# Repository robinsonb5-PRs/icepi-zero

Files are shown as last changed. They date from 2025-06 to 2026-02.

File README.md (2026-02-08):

# Icepi Zero - The portable FPGA development board

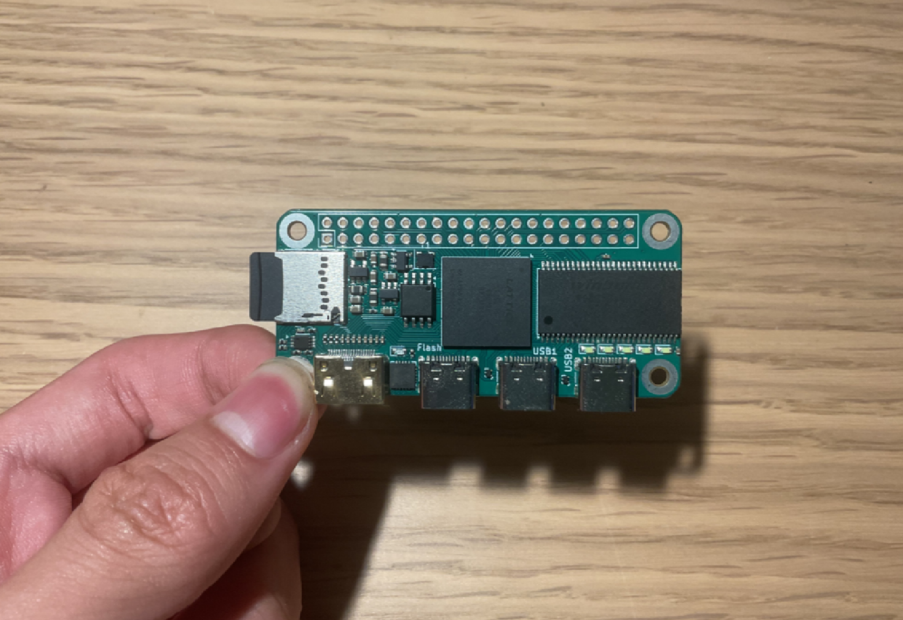
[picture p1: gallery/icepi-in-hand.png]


| Get your own on: | [**Crowd Supply**](https://www.crowdsupply.com/icy-electronics/icepi-zero)! | [**Elecrow**](https://www.elecrow.com/icepi-zero.html) |
| --- | --- | --- |

## What is the Icepi Zero?

The Icepi Zero is an FPGA development board in the popular Raspberry Pi Zero form factor. It carries a Lattice ECP5 25F, enabling powerful designs while keeping a small portable size. It also has a GPDI mini (General Purpose Display Interface, same as the one on the Pi Zero) port allowing easy digital video output.

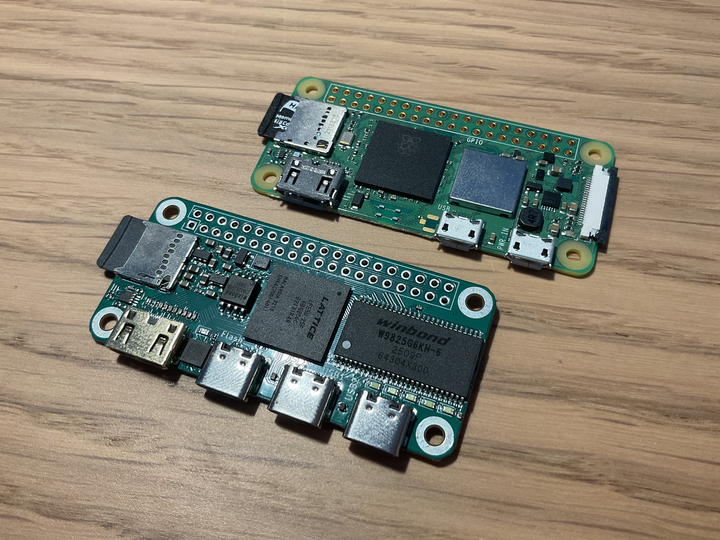
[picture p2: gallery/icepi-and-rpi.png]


## Why Icepi Zero?

Currently most powerful FPGA boards on the market are expensive and bulky.

I've always wanted a low-cost portable FPGA with video output to make my own CPU, but there isn't any on the market.

The Icepi Zero aims to fix this. Carrying a powerful ECP5 FPGA on a small Raspberry Pi Zero form factor, it is the ultimate portable solution for FPGA development. Additionally packing a GPDI mini port and 3 USB-C ports, it allows interfacing with multiple external I/O devices.

Icepi Zero is for everyone: Students can use it to learn about the internals of modern processors. Gamers can use it to emulate old hardware. Programmers can use it to test their code on multiple architectures.

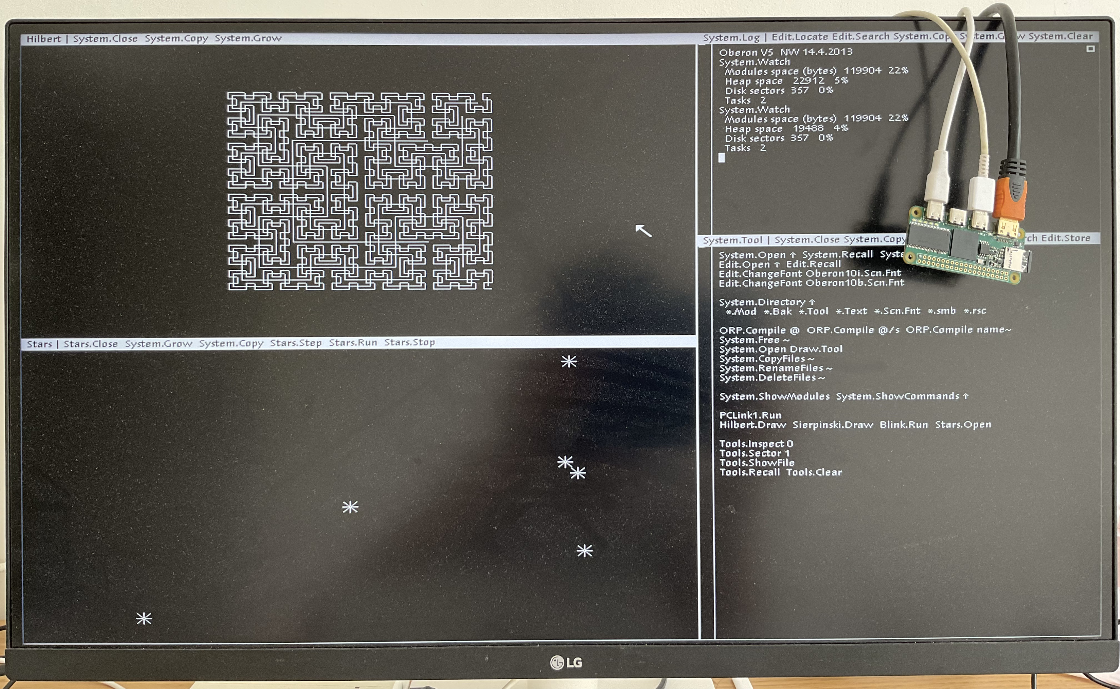
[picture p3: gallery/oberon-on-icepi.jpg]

<sub>Oberon running on Icepi Zero</sub>

Icepi Zero also has an on-board USB to JTAG converter, so no external programmers are needed.

Moreover Icepi Zero is fully open-source, no strings attached. Learn from the design! ([OSHWA cerified FR000026](https://certification.oshwa.org/fr000026.html)).



## Features

- Raspberry Pi Zero form factor
- Lattice ECP5U FPGA:
    - 24k LUT
    - 112 KiB of RAM
- One MiniGPDI connector (it's HDM- but I don't have the money to buy a license...)
- Three USB-C Ports
- 256Mbit 166MHz SDRAM
- MicroSD card slot
- On-board USB to JTAG and UART converter
- 50MHz external oscillator
- 128 Mbit of flash
- 4 user LEDs
- 2 user buttons

This powerful configuration allows the PCB to be used in numerous ways, including real time video processing, hardware AI acceleration and prototyping of ASICs. 

## Emulation

Over the course of multiple weeks, multiple emulation cores have been ported over, such as the [Oberon](https://github.com/cheyao/oberon), [Apple I](https://github.com/cheyao/apple-one) and the [Acorn Atom](https://github.com/cheyao/acorn_atom)! The Icepi Zero allows you to take cycle accurate replicas of your favourite systems in your pocket.


<sub>Apple I running on the Icepi</sub>


<sub>Acorn Atom running on the Icepi</sub>

## Learning

It is also supported by icestudio (custom fork: https://github.com/cheyao/icestudio), allowing easy access for beginners.



## Usage

Check out the `firmware` folder for example code and compilation instructions!

If you want to order this board, it uses a 1.2mm/1.6mm PCB with JLC04121H-7628 Stackup. Gerbers are in the `production` folder in the `hardware` directory.

For the PCB, the smallest component size is 0201 for 27 Ohm resistors on the USB-C datalines. But if you want only 0402 components, just delete those 0201 resistors and you will be fine.

NOTE: If you fabbed v1.1 before 01/06, the pins of the USB pullups and LED0 is different - check your gerbers.



[View PCB online](https://kicanvas.org/?github=https%3A%2F%2Fgithub.com%2Fcheyao%2Ficepi-zero%2Ftree%2Fmain%2Fhardware%2Fv1.2)

## Contact

If there is any questions DM `cyao.` on Discord. (Yup, with a dot. Send me a friend request!) Mail is also accepted at `cyao _at_ duck.com`. :)

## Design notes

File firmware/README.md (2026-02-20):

# Icedev Zero Firmware

## Table of Contents
- [Toolchain Setup](#toolchain-setup)
    - [Open Source Toolchain](#option-1-open-source-toolchain)
    - [Lattice Diamond](#option-2-lattice-diamond-ide)
- [Building Demos](#how-to-build-the-demos)
- [Flashing board](#how-to-flash)
- [Pinout](#pinout)
- [Linux on Litex SoC](#litex-soc)
- [More resources](#other-examples)

Welcome to the firmware folder! You can find numerous examples here:

- `blinky`: Classic LED counter!
- `counter`: Counter using the button as input :D
- `uart`: Uart transmission example
- `dvi`: GPDI example
- `usb`: USB examples
    - `usbmouse`: Shows a GPDI screen with an controllable mouse
- `third-party`: Third party verilog code
    - `memtest`: Memory tester w/ hdmi output! Pressing the button increases skew, middle row displays memory test cout, bottom row displays the number of bad memory reads.

## Toolchain setup

### Option 1: Open source toolchain

Download the latest build of the [OSS CAD Suite](https://github.com/YosysHQ/oss-cad-suite-build/releases/).

Unzip it anywhere and set shell command search path:
```
Linux              : export PATH=[path-to-bin]:$PATH
MacOS              : export PATH=[path-to-bin]:$PATH
Windows Powershell : $ENV:PATH = "[path-to-bin];" + $ENV:PATH
Windows cmd.exe    : PATH=[path-to-bin];%PATH%
```

### Option 2: Lattice Diamond IDE

To use the Diamond IDE, you must first request a license. (Free for individuals.)

Go to the [licensing page](https://www.latticesemi.com/Support/Licensing/DiamondAndiCEcube2SoftwareLicensing/DiamondFree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) and create an account. Then copy your device's MAC address, remove all colons and enter it into the "Host NIC" field. Click "Generate License". You should receive a license in your email after a few minutes.

After that, go to Diamond IDE's [download page](https://www.latticesemi.com/LatticeDiamond), install it following their instructions and select the license file when prompted.

You can now use Diamon IDE to create programs and flash it onto your Icepi with openFPGALoader!

Read more detailed instructions in the `DIAMOND.md` file.

## How to build the demos

Just `cd` into the directories, and type `make`!

- `make` runs `make debug`
- `make debug` installs the program to chip (bitstream is lost on power loss)
- `make install` installs the program to flash (bitstream is retained on power loss)
- `make install-bitstream` installs the `bitstream.bit` file to flash without rebuilding
- `make build` builds the bitstream (bitstream is retained on power loss)
- `make clean` deletes all the temporary files

## Make your own!

Just copy the `icepi-zero.lpf` and `Makefile` to the root of your directory, call your main module `top`, and you are good to go!

## How to flash

---
> An example bitstream file exists in the [documentation](../documentation/) folder.

The following command is used to flash the development board

```zsh
openFPGALoader -cft231X --pins=7:3:5:6 bitstream.bit
```

You can also add the `--write-flash` flag to permanantly write the bitstream to flash, this way the bitstream file will be saved even when the board powers down.

Note: If you use the newest version of openFPGALoader, it supports the `-b icepi-zero` flag that can replace `-cft231X --pins=7:3:5:6`.

Alternatively, you can use the web version of openFPGALoader on Google Chrome: [https://ofl.trabucayre.com/](https://ofl.trabucayre.com/).

Select "Default" as the cable and "icepi-zero" as the board, upload your .bit file and press Program.



Then select "FT231X USB UART" from the popup menu:



Now your board should be flashed! Happy hacking.

> Getting an error when flasing? Check out the [openFPGALoader troubleshooting](https://trabucayre.github.io/openFPGALoader/guide/troubleshooting.html) page.

## Pinout

The GPIO pinout is exactly the same as a [Pi Zero](https://pinout.xyz/):

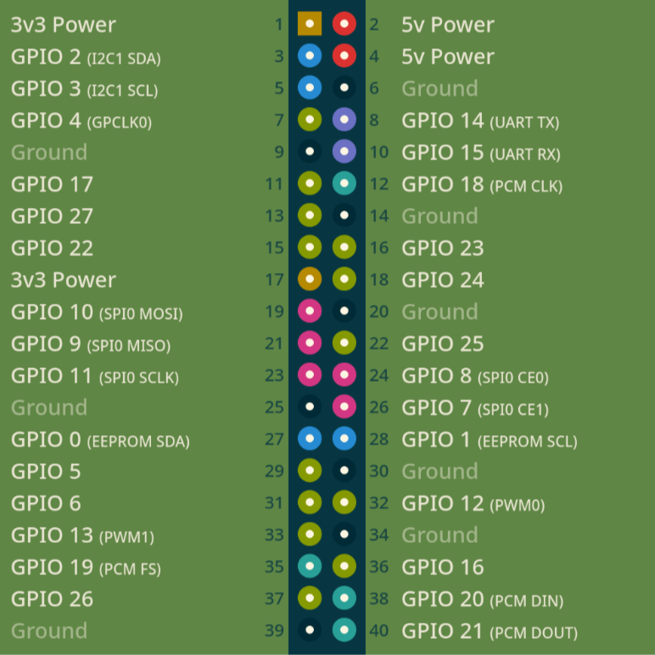
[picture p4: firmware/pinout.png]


You can find the name of rest of the I/O pins in `icepi-zero.lpf`:

- `gpio[27:0]`: gpio pins
- `led[4:0]`: User LEDs
- `button`: User button
- `gpdi_dp[3:0]`: GPDI interface
- `sdram_*`: SDRam interface
- `flash_*`: Flash interface
- `sd_*`: SDCard interface
- `usb_*`: FTDI/USB ports (UART/USB)
- `tp[1:0]`: Test points

Debug pins are distrubuted as the follwing picture shows:

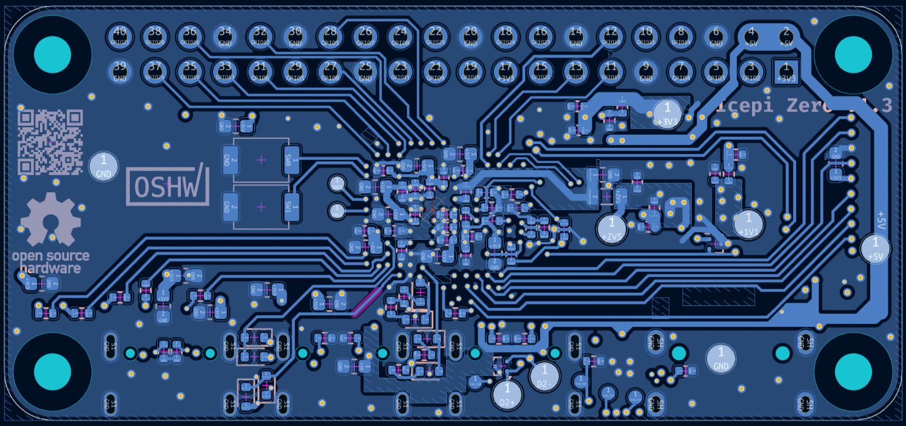
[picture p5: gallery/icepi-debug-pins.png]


## LiteX SoC

You can run a VexRiscv CPU (and Linux) on the Icepi Zero using [Litex](https://github.com/enjoy-digital/litex), @oliver408i wrote an [awesome guide](https://github.com/oliver408i/icepi-zero-litex) on how to use it!

## Other examples

This board is already supported by [apio](https://github.com/FPGAwars/apio/) and [icestudio](https://github.com/FPGAwars/icestudio)'s development branch. The board should be supported on stable in the next release.

The [litex-boards](https://github.com/litex-hub/litex-boards) also supports the Icepi Zero, while [linux-on-litex-vexriscv](https://github.com/litex-hub/linux-on-litex-vexriscv) has an pr open. (Forgot to open it last month, opps!)

And here are some retro ports:

- [Apple 1 Emulator](https://github.com/alangarf/apple-one)
- [Port of Acorn Atom](https://github.com/cheyao/acorn_atom)
- [Commodore 64!](https://github.com/cheyao/c64)
- [Oberon](https://github.com/cheyao/oberon)
- [Sega Master System](https://github.com/cheyao/sega-sms)
- [Port of Silice](https://github.com/sylefeb/Silice/) (Check out the projects folder - it's full of interesting programs)

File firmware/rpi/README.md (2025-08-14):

Examples for interfacing with a Raspberry Pi Zero

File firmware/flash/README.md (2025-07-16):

This example reads flash from 0x200000 and outputs the data to uart.

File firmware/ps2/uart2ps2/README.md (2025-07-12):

## UART2PS2 converter for ECP5
For those of us who doesn't have an old keyboard :)

Inputs 115200 8N1 UART via the "Flash" USB port

Outputs PS/2 on both USB ports (exact copies of the signal)

Limitation: No host to device communication, nor any stops

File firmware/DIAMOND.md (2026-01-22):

# How to use Lattice Diamond

## Obtain a License

To use the Diamond IDE, you must first request a license. (Free for individuals.)

Go to the [licensing page](https://www.latticesemi.com/Support/Licensing/DiamondAndiCEcube2SoftwareLicensing/DiamondFree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) and create an account. Then copy your device's MAC address, remove all colons and enter it into the "Host NIC" field. Click "Generate License". You should receive a license in your email after a few minutes.

After that, go to Diamond IDE's [download page](https://www.latticesemi.com/LatticeDiamond), install it following their instructions and select the license file when prompted.

## Creating a project

Open up Diamond IDE! If you are on linux, you should have an executable named `diamond` in the `diamond/3.14/bin/lin64/` folder of your instalation.

Now click on `File > New > Project...` and a new window should pop up.

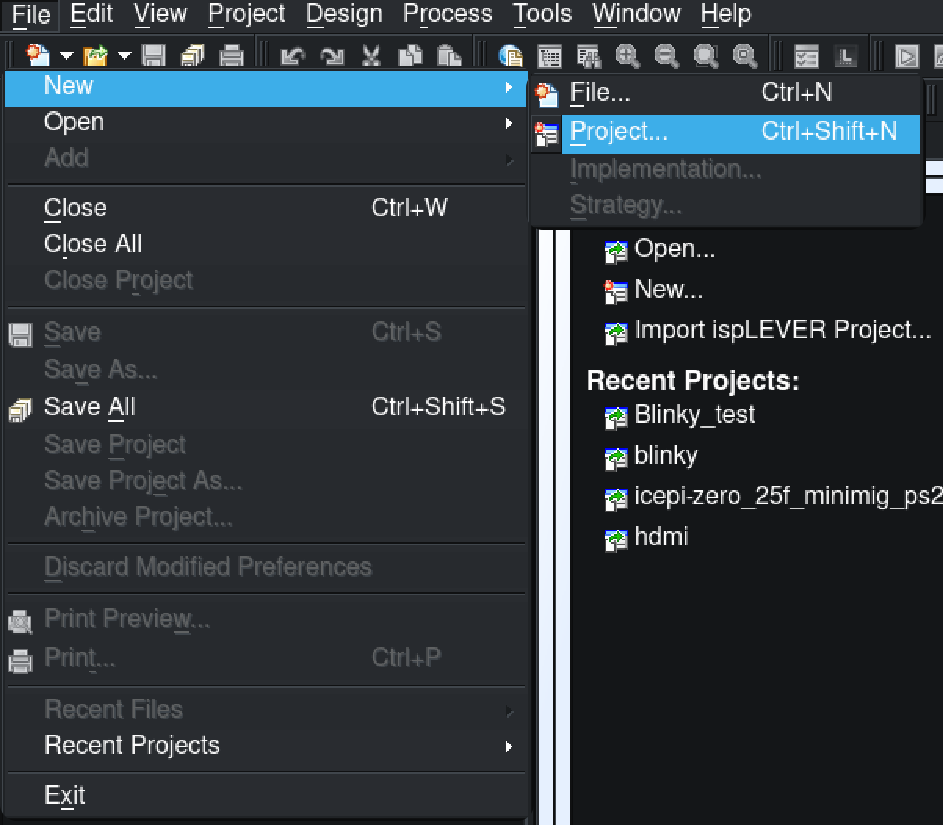
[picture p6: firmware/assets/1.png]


Now follow the menu while configuring your project:

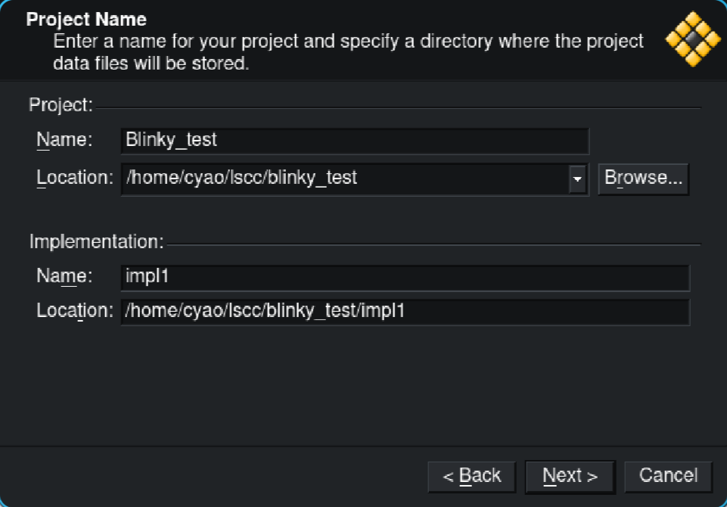
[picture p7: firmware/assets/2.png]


For sources, you don't need to add the Makefile, only your HDL sources and the lpf file. Do **NOT** add the pll.sv generated by `ecppll`, it isn't compatiable with Diamond IDE. To use a pll you need to generate an IP using the Clarity Designer inside the IDE.

This is what would need to be selected for the blinky project:

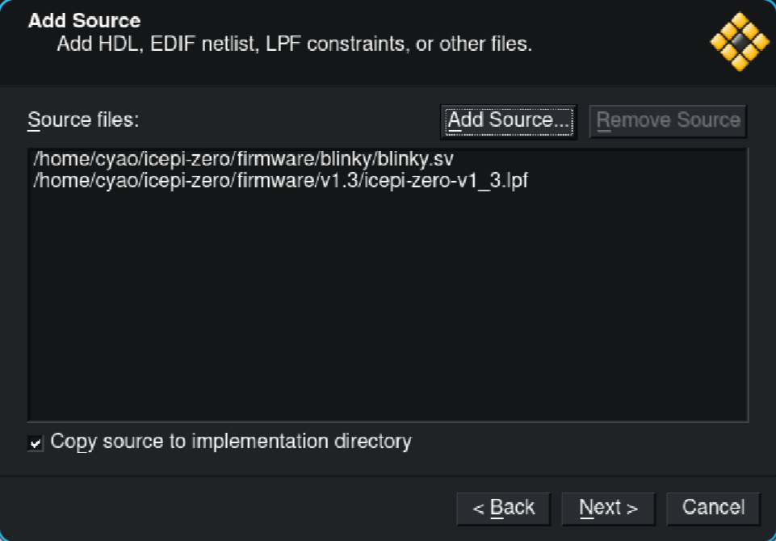
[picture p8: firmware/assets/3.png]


(Note: to select the lpf you need to change "Files of type" in the file selector to all files)

Now you need to select the device. For the Icepi Zero, choose "ECP5U" as the family, "LFE5U-25F" as the device and make sure to select "CABGA256" as the package type.

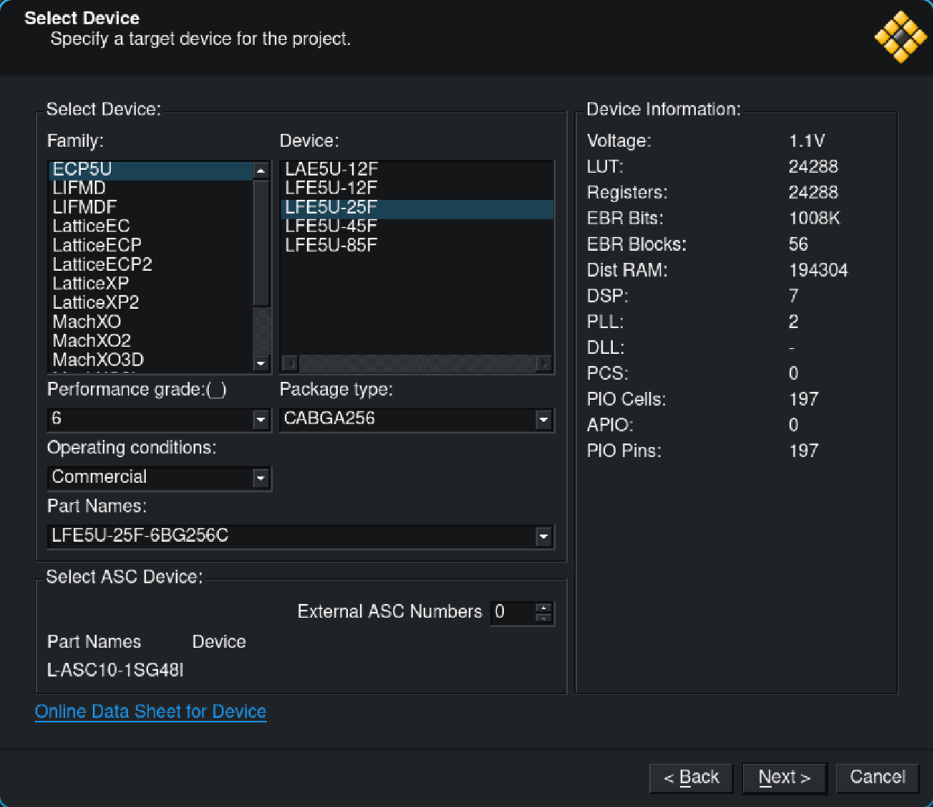
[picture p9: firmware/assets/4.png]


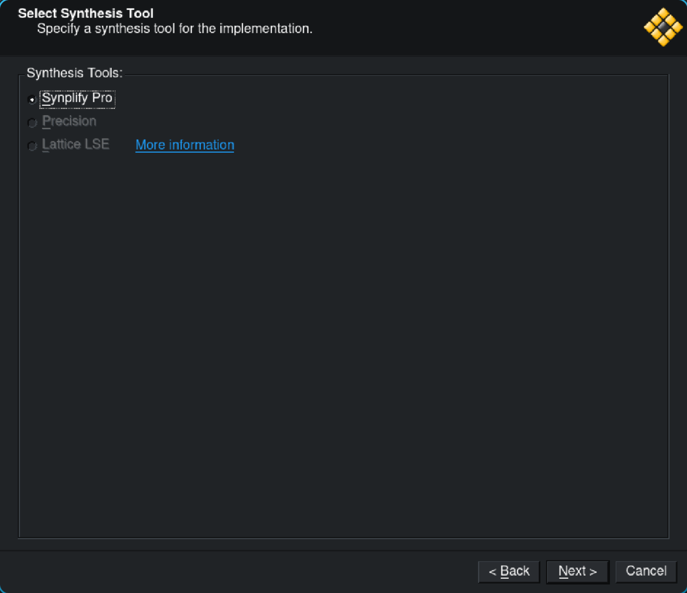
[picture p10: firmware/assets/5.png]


Click next, now on the left panel switch to the process tab, and check everything like this:

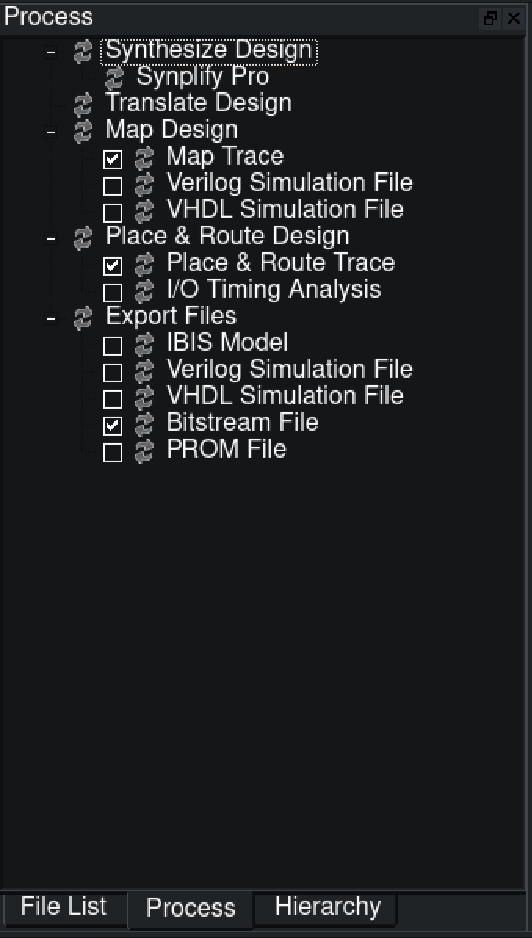
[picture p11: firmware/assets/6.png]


Double click "Export Files", and all the processes should run one by one. When everything has finished running, you should be left with a file named "Blinky_test_impl1.bit" in the "impl" folder, which can be flashed onto the board:

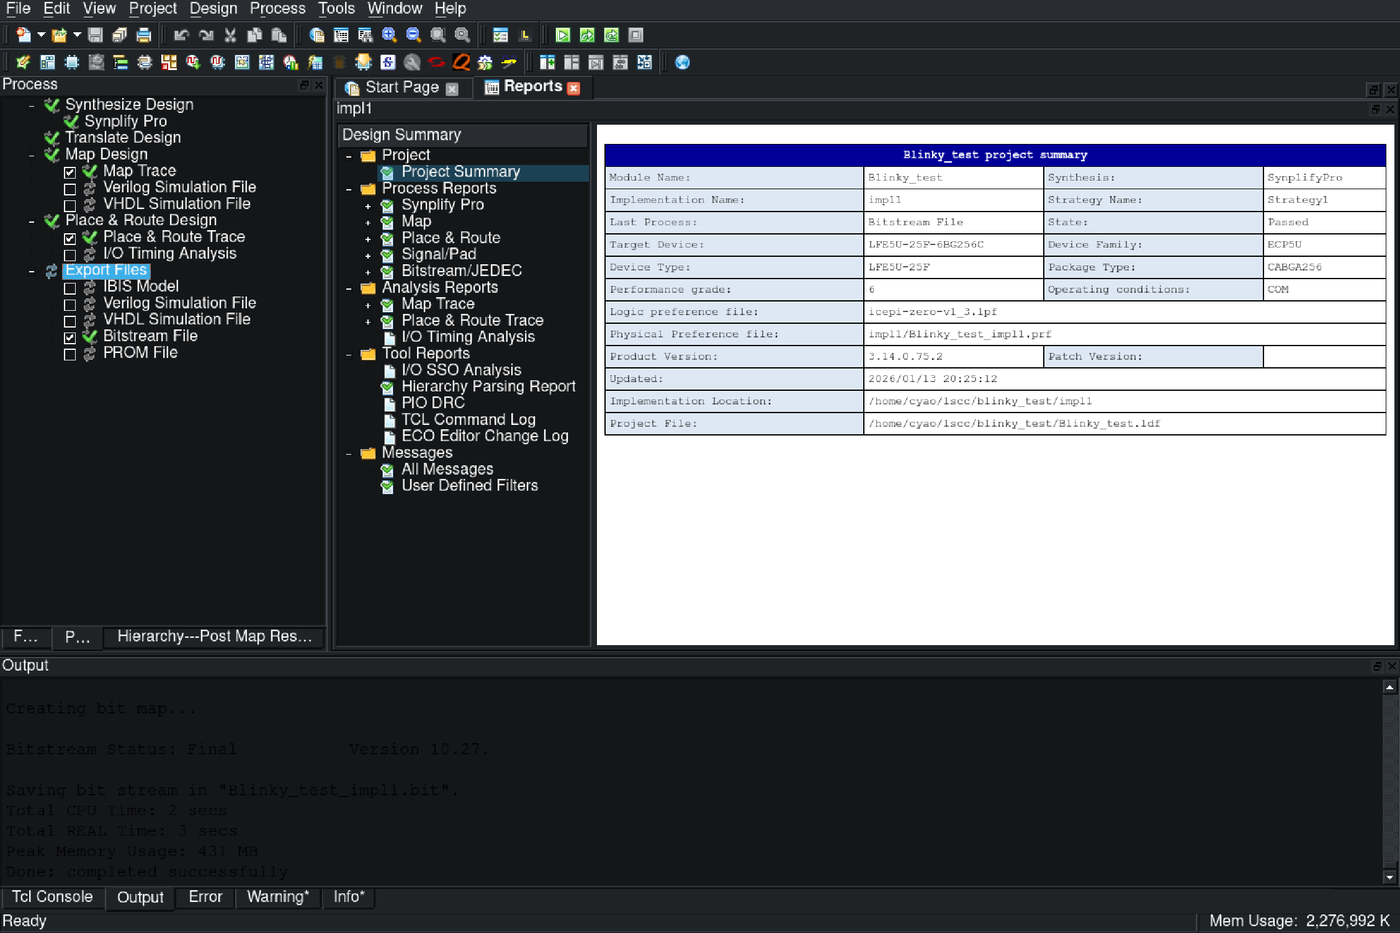
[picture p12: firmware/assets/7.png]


Unfortunetly Diamond IDE doesn't support the FT231XQ chip that the board uses, so you need to use `openFPGALoader` ([Github](https://github.com/trabucayre/openFPGALoader), contained in oss cad suite) to flash the bitstream onto the board.

Happy hacking!

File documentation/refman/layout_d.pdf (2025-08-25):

Layout-Anderungen mit L ¨ | ATEX

EDV-Zentrum der TU Wien, Abt. Digitalrechenanlage Hubert Partl
1988-10-04
Axel Kielhorn∗
1996-01-01
H27.0 — Version 1

Zusammenfassung

Dieses Dokument beschreibt die Möglichkeiten der refart und refrep Class fur L ¨ ATEX 2ε. Sie arbeitet nicht mehr mit dem alten LATEX 2.09 zusammen und enthält einige Verbesserungen gegen-
uber dem Original. Alte ¨ | REFMAN Quellen sollten sich aber problem-
los an die Class anpassen lassen.

Dieses Heft ist als Ergänzung zu Kapitel 5 (“Designing It Yourself”) des LATEX-Manuals von Leslie Lamport gedacht.

Inhaltsverzeichnis

1 Einleitung | 3
1.2 Layout-Anderungen | | 3 ¨
2 Die Kunst des Layout-Design | 4
2.2 Spezielle Hinweise fur technische Beschreibungen | | 5 ¨
3 Wie kann man das LATEX-Layout ändern? | 6
3.4 Vorgangsweise bei Layout-Anderungen | | 7 ¨
3.6 Ein etwas komplexeres Beispiel (Reference Manual) . . . . | 10
Anhang | 13

∗ A.Kielhorn@web.de

A Die Seitenaufteilung in LATEX | 13
B Beschreibung der Dokumentklasse Refman | 16
B.3 Layout-Anderungen | | 17 ¨

### 1 Einleitung

### 1.1 Autor, Layout-Designer und Setzer

Jedes Schriftstuck – von einer kurzen handgeschriebenen Notiz bis zu ¨ einem gedruckten Buch –besteht aus zwei Komponenten: Inhalt und Form. In den meisten Fällen ist die Form nicht Selbstzweck sondern
dient nur dazu, den Inhalt fur den Leser verst ¨ | ändlich darzustellen.
Autor: | Der Inhalt wird vom jeweiligen Autor geliefert. Bei Druckwerken wird
der Autor meist durch den Lektor des Verlages oder den Herausgeber der Zeitschrift unterstutzt. ¨

Bei der Verwendung des Textsatzsystems LATEX wird der Inhalt im Hauptteil des LATEX-Eingabefiles angegeben – also zwischen \begin{document} und \end{document} – ergänzt durch LATEX-Befehle, die angeben, welche Bedeutung die einzelnen TextTeile haben.

Designer: Die Form eines Druckwerks wird ublicherweise vom Verleger festgelegt, ¨ der das Layout von den im Verlag angestellten Designern entwerfen läßt.

Die mit LATEX mitgelieferten sogenannten ”

Document Classes“ wurden
von professionellen amerikanischen Layout-Designern fur die von Les- ¨
lie Lamport vorgesehenen Arten von Schriftstucken entworfen, also f ¨ | ur ¨
wissenschaftliche Zeitschriften, Berichte und Bucher – auf der Grundla- ¨ ge der in den USA ublichen Konventionen. Die ¨
”

Koma-Script- Classes“
sind an den europäischen Geschmack angepaßt und in vielen Kleinigkeiten optimiert worden. Diese Layouts sind in den sogenannten ”

Class-Files“ festgelegt. Am Beginn des LATEX-Eingabefiles – vor dem Befehl \begin{document} – wird angegeben, in welcher Form der Inhalt des Schriftstucks gesetzt und ausgedruckt werden soll. ¨

Setzer: Der Setzer in der Druckerei bringt den vom Autor bzw. Lektor gelieferten Inhalt in die vom Layout-Designer festgelegte Form, in der das Schriftstuck dann schließlich ausgedruckt wird. ¨

Bei der Verwendung von LATEX erfolgt das Setzen durch das Computer-Programm TEX und das Ausdrucken durch ein weiteres Computer-Programm, den sogenannten Device-Driver.

### 1.2 Layout-Anderungen ¨

Wenn das Schriftstuck nicht in einem der vorgefertigten L ¨ | ATEX-Layouts
gesetzt werden soll, sind die folgenden zwei Voraussetzungen notwendig:
1. Das Layout muß entworfen werden. Dies sollte im allgemeinen von einem professionellen Designer gemacht werden. Falls kein solcher zur Verfugung steht, muß sich der Autor oder der Herausgeber als ¨

”

Amateur-Designer“ versuchen – am besten durch Anlehnung an professionell gestaltete Vorbilder.

→ 2 | Ausfuhrlichere Hinweise dazu werden in Kapitel 2 angegeben. ¨
2. Das Layout muß in Form eines LATEX-Class-Files formuliert werden. Dies kann entweder als ”

Class-Option“ geschehen, oder durch die Definition einer neuen ”

Class“. Die komplette Neudefinition hat den Vorteil, das sie weitreichendere Anderungen erlaubt. Ich ha- ¨ be mich daher bei der Portierung nach LATEX 2ε fur eine eigene ¨

”

Class“ entschieden. Dadurch wird die Ubertragung von alten Da- ¨ teien zwar etwas erschwert, aber meiner Meinung nach uberwiegen ¨ die Vorteile. Die Angabe dieser ”
Class“ bzw. dieser ”

Class-Option“

am Beginn des LATEX-Eingabefiles bewirkt dann, daß der Inhalt des Schriftstucks in dieser neuen Form gesetzt und gedruckt wird. ¨

→ 3 | Ausfuhrlichere Hinweise dazu werden in Kapitel 3 angegeben. ¨

### 2 Die Kunst des Layout-Design

### 2.1 Allgemeine Regeln

Es gibt fast keine allgemeingultigen Regeln, sondern man muß f ¨ | ur je- ¨
des Schriftstuck oder jede Reihe von Schriftst ¨ | ucken ein eigenes Layout ¨
entwerfen.

Dieses Layout muß sich vor allem daran orientieren, wer das Schriftstuck ¨ wie lesen wird.

Ein wichtiges Kriterium ist z. B., ob der Leser es eher von A bis Z durchgehend lesen will wie einen Kriminalroman oder ein ”

Tutorial“, oder ob
er eher bestimmte Stellen rasch auffinden will wie in einem Telefonbuch oder in einem ”

Reference Manual“.

Außerdem muß das Layout die bestehenden Konventionen berucksichti- ¨ gen, vor allem die Gewohnheiten des Lesers, aber auch den sogenannten ”

House Style“, durch den sich verschiedenartige Schriftstucke und die ¨ Produkte verschiedener Hersteller oder Institutionen voneinander unterscheiden sollen.¹

! → Der Hauptzweck des Layouts ist stets, daß der Leser die gesuchten Informationen gut findet und sie gut lesen kann, und daß er den Inhalt und den logischen Aufbau des Schriftstucks richtig versteht. Wichtig sind also ¨
Ubersichtlichkeit, Lesbarkeit, Konsistenz und dergleichen. Die Sch ¨ | önheit
(Asthetik) steht demgegen ¨ | uber im allgemeinen nur an zweiter Stelle. ¨
2

Im folgenden werden ein paar einfache ”

Faustregeln“ fur den Seitenaufbau ¨
angefuhrt, die f ¨ | ur die meisten Anwendungen G ¨ | ultigkeit haben. ¨
Zeilenabstände : | Die Zeilenabstände mussen gr ¨ | ößer als die Wortabstände sein, damit
die Augen des Lesers richtig entlang der Zeilen gefuhrt werden. ¨

Zeilenlänge : Die Zeilenlänge – bzw. bei mehrspaltigem Druck die Spaltenbreite – soll möglichst bei etwa 60 Zeichen pro Zeile liegen. Zu lange Zeilen sind schlecht lesbar, weil sie anstrengende Augenbewegungen erfordern und gleichzeitig die Wahrscheinlichkeit erhöhen, beim Zeilenwechsel in die falsche Zeile zu geraten. Zu kurze Zeilen machen Probleme beim Randausgleich (Blocksatz) und beim Abteilen (Silbentrennung). Wenn längere Zeilen notwendig sind, dann mussen ¨ die Zeilenabstände vergrößert werden.

Seitenaufbau : Die normalen Textseiten sollen einen möglichst einheitlichen Aufbau haben. Abbildungen, Tabellen und spezielle Seiten wie Inhaltsverzeichnis, Index usw. sollen aber nicht in dasselbe Schema gepreßt werden, sondern stets so viel Platz einnehmen, wie fur die ¨
jeweilige Tabelle etc. am gunstigsten ist (also durchaus k ¨ | urzer oder ¨
länger als die normale Zeilenlänge, evtl. mit einem Rahmen darum herum). Wenn möglich sollten bei der Seitenaufteilung auch ästhetische Grundregeln wie z. B. der ”

Goldene Schnitt“ (13 : 8 ≈ 8 : 5) angewendet werden.

1 Man vergleiche z. B. das jeweils typische Layout verschiedener Fachzeitschriften oder Tageszeitungen.
2 Dies gilt naturlich nicht f ¨ | ur Werbeprospekte, Bildb ¨ | ände und dgl.

Randnoten : ” Randnoten“ sind fur viele Zwecke besser geeignet als Fußnoten, ¨
weil sie direkt neben dem Text erscheinen, auf den sie sich beziehen. Dazu zählen auch Symbole wie z. B. ”

Achtung-Zeichen“, die wichtige Text-Teile markieren bzw. den Leser auf sie hinweisen.

Kopf- und Fußzeilen : | Der Inhalt von Kopf- und Fuß-Zeilen soll die Orientierung innerhalb
| des Schriftstucks erleichtern. Falls zu erwarten ist, daß manche Le- ¨
ser einzelne Seiten aus dem Schriftstuck herauskopieren (z. B. einen ¨ Artikel aus einer Zeitschrift), sollte in der Kopf- oder Fußzeile auch die Information zu finden sein, aus welchem Schriftstuck die Seiten ¨ stammen. Falls häufig neue Versionen eines Schriftstucks erstellt ¨ werden (z. B. bei Software-Manuals), sollte auch das Datum oder die Versionsnummer in der Kopf- oder Fußzeile erscheinen.

### 2.2 Spezielle Hinweise fur technische Beschreibungen ¨

Wir wollen kurz die Eignung von drei verschiedenen Layouts fur den ¨ an unserer Universität häufigen Spezialfall von technischen Beschreibungen, Users’ Guides, Reference Manuals, Mitteilungsblättern und ähnlichen technischen Druckwerken vergleichen:³

Plain TEX : Das Standardformat von Plain TEX hat vor allem den großen Nachteil, daß die Zeilen viel zu lang sind, was sich schlecht auf die Les-
| barkeit und Ubersichtlichkeit auswirkt. Dieses von Schreibmaschi- ¨
nenschrift gewohnte Schriftbild eignet sich nicht fur die von T ¨ | EX
| unterstutzte ¨
”
| | Druck“-Schrift. Die an der TU Wien vor der Einfuh- ¨
rung von LATEX entwickelten Macros EASY.TEX und ARTii.TEX bzw. REPii.TEX haben außerdem einige weitere Design-Mängel, z. B. sind die Abstände zwischen den Kapitel-Uberschriften zu groß. ¨

Standard-LATEX : Auch das Standardformat von LATEX ist fur diese Zwecke nicht ide- ¨ al. Die Zeilenlänge ist zwar richtig gewählt, aber die Seiten enthalten einen zu großen ungenutzten Rand, insbesondere oben und ¨
unten. Außerdem werden fur die Kapitel- ¨ | Uberschriften etwas zu ¨
große Schriften verwendet.
Reference-Manual-Style : | Ein fur solche Zwecke g ¨ | unstigeres Seiten-Layout findet man bei ei- ¨
nigen in den letzten Jahren neu erschienenen Reference Manuals:⁴
- Der fortlaufenden Text steht mit einer relativ kurzen, gut lesbaren Zeilenlänge im rechten Teil der Seite. Dieser Teil dient also zum fortlaufenden Lesen einzelner Abschnitte.
- Im breiten linken Rand jeder Seite stehen die Uberschriften so- ¨ wie Stichworte und andere ”
Randnoten“. Dieser Teil dient also zum raschen Auffinden von bestimmten Informationen innerhalb des gesamten Schriftstucks. ¨
- Abbildungen und Tabellen stehen je nach ihrem Platzbedarf in der einen oder anderen Spalte oder gehen uber die gesamte ¨
| Seitenbreite.
→ 3.6 | Eine Anleitung, wie man ein solches Layout mit LATEX realisieren
kann, wird in Abschnitt 3.6 angegeben.

3 Diese Hinweise stammen von Paul Stiff, der Layout-Design an der University of Reading unterrichtet.
4 Ein häufig zitiertes – allerdings in den konkreten Details auch nicht ganz ideales – Beispiel ist das ”
| | PostScript Reference Manual“.

### 3 Wie kann man das LATEX-Layout ändern?

### 3.1 Vor und Nachteile des Textsatzsystems LATEX

Der große Vorteil von LATEX besteht darin, daß es ein ”
Vorteile: | generisches“ oder

”

logisches“ Design unterstutzt. Darunter versteht man, daß der Autor ¨ nur mit einigen wenigen Befehlen angeben muß, welche Bedeutung die einzelnen Text-Teile haben: Uberschriften, Zitate, mathematische Glei- ¨ chungen, Listen, Aufzählungen, Literaturangaben usw. Diese logischen Begriffe werden dann vom System automatisch in der richtigen Art und Weise gesetzt und ausgedruckt. Was ”

richtig“ ist, muß dem System vorher in geeigneter Weise mitgeteilt werden, bei LATEX durch die Angabe der

”

Document Class“ und eventuell weiterer ”
Packages“.

Im Gegensatz dazu steht das von älteren Textverarbeitungsprogrammen und auch von Plain TEX unterstutzte ¨
”

visuelle“ Design, bei dem der Autor die sichtbaren Eigenschaften wie Schriftart, Schriftgröße, vertikale Abstände, horizontale Einruckungen usw. angeben muß. ¨

Das Prinzip des logischen Design macht einerseits die Anwendung durch den Autor wesentlich einfacher und ubersichtlicher und stellt andererseits ¨ die logische Konsistenz des Schriftstucks sicher (z. B. einheitliche Schrift- ¨
art fur alle ¨ | Uberschriften des gleichen Levels, einheitliche Numerierung ¨
von Kapiteln und von Gleichungen, einheitliche Darstellung von Listen und Aufzählungen, usw.).

Nachteile: Als Nachteil von LATEX wird immer wieder angefuhrt, daß es den Autor ¨ zu sehr einschränkt und daß man das Layout zu wenig ändern kann. Dies ist nur teilweise richtig, nämlich nur dann, wenn man sich auf die vier mit LATEX mitgelieferten Standard-Layouts beschränkt, die sich selbstverständlich nicht fur alle Anwendungen eignen und die außerdem sehr ¨ stark an amerikanische Konventionen angepaßt sind.

LATEX ist aber wesentlich mächtiger und flexibler: Man kann praktisch beliebige Anderungen am Layout dadurch erreichen, daß man die in den ¨ Style-Files enthaltenen Definitionen ändert, die geänderten Definitionen in privaten Style-Option-Files speichert und diese dann als zusätzliche
Style-Options aufruft. Der Aufwand dafur ist keineswegs gr ¨ | ößer als bei der
Verwendung von Plain TEX, in manchen Fällen sogar wesentlich geringer.

### 3.2 Eingabe-Dateien und Class-Dateien

In Einklang mit dem Prinzip des logischen Design und der Trennung von Inhalt und Form verwendet LATEX grundsätzlich zwei Arten von Dateien:

- Der Inhalt einschließlich der logischen Struktur des Schriftstucks ¨ wird in den LATEX-Eingabefiles festgelegt.
- Die Form (das Layout) wird in sogenannten Class-Files und eventuell auch Packages festgelegt.

Welche Class- und Package-Files ein Schriftstuck verwendet – d. h. in ¨ welchem Layout es gesetzt werden soll – wird am Beginn des Eingabefiles mit den Befehlen \documentclass bzw. \usepackage angegeben.

Fur die Erzeugung eines Schriftst ¨ | ucks mit L ¨ | ATEX sind also zumindest zwei
Files notwendig: ein Eingabefile und ein Class-File.

Diese Trennung entspricht den in der Einleitung erläuterten unterschiedlichen Funktionen von Autor und Layout-Designer. Sie hat aber auch fur ¨ den Fall, daß der Autor selbst das Layout festlegt, wesentliche Vorteile:

- Einerseits wird damit sichergestellt, daß zusammengehörige Schriftstucke automatisch im selben Layout gesetzt werden, auch wenn ¨ dieses Layout nach dem Erstellen des Textes noch geändert wurde. Dies wäre nur schwer zu erreichen, wenn die Layout-Definitionen direkt in jedem einzelnen Eingabefile enthalten wären.
- Andererseits ist es auf diese Weise ohne großen Aufwand möglich, denselben Inhalt in verschiedenen Layouts auszudrucken, z. B. als Artikel fur die eine oder andere wissenschaftliche Zeitschrift oder ¨ als Kapitel einer Dissertation und eines Forschungsberichts.

### 3.3 Class-Files und Package-Files

LATEX unterstutzt innerhalb der Layout-Definition die folgende Hierarchie ¨ von ”

Class“ und ”

Option“, die sich in den verschiedenen Parametern des Befehls \documentclass widerspiegelt:

- Als erstes wird der Inhalt desjenigen ”
Class-Files“ verarbeitet, dessen Name im \documentclass-Befehl zwischen den geschwungenen Klammern angegeben wurde. Dies gibt die grundsätzliche Art des Schriftstucks an. ¨
- Dann werden der Reihe nach diejenigen ”
Class-Option-Files“ verarbeitet, deren Namen zwischen den eckigen Klammern angegeben wurden. Damit kann man verschiedene Layout-Varianten auswählen.
- Als dritter Schritt werden dann die im \usepackage-Befehl angegebenen Packages geladen, die ihrerseits wieder Optionen laden können.

Diese mehrstufige Verarbeitung macht es möglich, die Layout-Definition in mehrere kleinere Einheiten zu zerlegen, wobei in einem Class-Option-
File sowohl Layout-Definitionen der ursprunglichen Class-Files abge ¨ | än-
dert als auch weitere Definitionen hinzugefugt werden k ¨ | önnen.

Class-Files, Class-Option-Files und Packages unterscheiden sich von ” normalen“ Eingabefiles im wesentlichen durch die folgenden Punkte:

- Sie durfen nur Definitionen enthalten, aber keine Text-Ausgaben ¨ bewirken.
- Das Sonderzeichen ”

Klammeraffe“ (@) hat in ihnen die Bedeutung eines Buchstabens (”

letter“), d. h. es ist innerhalb von Befehlsnamen erlaubt. Die meisten von LATEX intern verwendeten Befehle enthalten Klammeraffen in ihren Namen, damit Kollisionen mit den vom Benutzer verwendeten Befehlen ausgeschlossen werden.

- Die Filenamen haben die ”
Extension“ cls bzw. clo oder sty fur ¨ Packages (nicht tex).

### 3.4 Vorgangsweise bei Layout-Anderungen ¨

3.4.1 Festlegen der Anderungen gegen ¨ | uber dem Original-Layout ¨
Im allgemeinen ist es gunstiger, die Class-Files f ¨ | ur das neue Layout nicht ¨
von Null an neu zu erstellen, sondern die bereits bestehenden LATEX-Class-Files als Vorbilder zu verwenden und so viel wie möglich von den darin enthaltenen Definitionen zu ubernehmen. ¨

In den meisten Fällen genugt es sogar, ein mehr oder weniger kurzes ¨ Package-File zu erstellen, das nur die Unterschiede des neuen Layouts ge-
genuber einem der originalen L ¨ | ATEX-Layouts enthält, und diese ” Option“
dann in Verbindung mit der originalen ”
| Class“ zu verwenden.

Im ersten Schritt legt man daher fest, in welchen Bereichen sich das neue Layout vom originalen LATEX-Layout unterscheidet und worin diese Unterschiede im einzelnen bestehen. Man geht dabei am besten so vor, daß
man sich fur alle als L ¨ | ATEX-Befehle oder -Environments definierten logi-
schen Einheiten uberlegt, in welchem Layout sie gesetzt werden sollen. ¨ Neue zusätzliche LATEX-Befehle sollte man nach Möglichkeit nicht erfinden – und wenn, dann nur im Einklang mit dem Prinzip des logischen Design und mit der Struktur der anderen LATEX-Befehle (z. B. neue En-
vironments fur spezielle Tabellen, oder eigene Befehle f ¨ | ur spezielle Her- ¨
vorhebungen).

3.4.2 Finden der Original-Definitionen

Im zweiten Schritt muß man finden, wo und wie alle die Layout-Eigenschaften, die man ändern will, im Original definiert sind. Dazu soll man die folgenden Quellen in der folgenden Reihenfolge durchsuchen:⁵

1. das LATEX-Manual von Leslie Lamport,
2. die Dokumentations-Files *.dtx
3. die Kernal-Files *.ltx,
4. das TEXbook von Donald E. Knuth.
Die beiden Bucher sind im Buchhandel erh ¨ | ältlich (Verlag Addison Wes-
ley). Ob und wo die Files an Ihrem Computer angelegt sind, ist im ”
| LATEX
Local Guide“ Ihrer Installation angegeben. Die Files sind sehr gut kommentiert, sodaß man sich im allgemeinen auch dann gut in ihnen zurechtfindet, wenn man nicht alle Details der darin enthaltenen Befehle versteht.

3.4.3 Schreiben eines neuen Package-Files

Im dritten Schritt erzeugt man das neue Package-File. Man wählt einen
Namen fur die neue Package (z. B. ¨ | refman) und bildet den Filenamen aus
diesem Namen und der Extension sty (z. B. refman.sty). Ausgerechnet fur ¨ refman trift diese Vorgehensweise nicht zu, da es sich inzwischen um eine eigenständige Class handelt.

Dieses File muß nur diejenigen Definitionen (\def-Befehle, Wertzuweisungen und dergleichen) enthalten, die sich gegenuber der Originalversion ¨ unterscheiden, und/oder diejenigen, die man zusätzlich definieren will.

Bei den Anderungen geht man am besten so vor, daß man die betreffenden ¨ \def-Befehle, Wertzuweisungen usw. aus den originalen Files in das neue File kopiert und dann dort entsprechend modifizert.

Auch bei neuen Definitionen lehnt man sich am besten an Vorbilder in den originalen Files an.

Außerdem muß man den Zweck des Files, seine Verwendung, den Autor und das letzte Anderungsdatum sowie alle im File enthaltenen Defini- ¨ tionen auf Kommentarzeilen innerhalb des Files dokumentieren. Bei sehr

5 Diese Hinweise stammen von Sue Brooks, die im Rahmen der TEX-Konferenz 1988 in Exeter ein Workshop fur ¨
| ” LATEX-Hacker“ leitete.

umfangreichen Style-Files kann man dazu das docstrip-Programm benutzen, mit dem auch alle LATEX 2ε Dateien dokumentiert wurden. Das Script (*.ins) erzeugt aus dem Dokument (*.dtx) dann eine Package (*.sty) oder Class (*.cls). Die dtx-Datei dient gleichzeitig als Dokumentation. Dadurch bleibt gewährleistet das Package und Dokumentation
ubereinstimmen. In den meisten F ¨ | ällen genugt es aber, nur ein ¨ | sty-File
mit allen Kommentaren anzulegen.

3.4.4 Verwendung der neuen Style-Option

Durch die Angabe des neuen Package-Namens im \usepackage-Befehl
werden die Anderungen f ¨ | ur das betreffende Schriftst ¨ | uck wirksam, d. h. die- ¨
ses wird im neuen Layout gesetzt. Beispiel:

%Alte Version:
\documentstyle[11pt,twoside,german,refman]{article}

wird zu:

%Neue Version: (LaTeX2e)
\documentclass[11pt,twoside,a4paper]{refart} \usepackage{german}
%\usepackage{mysty} %<- Hier wird meine Package geladen

Davon abgesehen sollten keine Anderungen im Eingabefile notwendig sein ¨
– es sei denn, das Schriftstuck enth ¨ | ält spezielle logische Text-Elemente,
die im neuen Layout vorgesehen sind, aber in Original-LATEX nicht unterstutzt werden. ¨

! → Wenn man das Eingabefile an einen anderen Computer ubertragen will, ¨ muß man alle darin verwendete Package-Files mitubertragen, damit es ¨ auch dort verarbeitet werden kann.

### 3.5 Ein einfaches Beispiel (Gleichungsnummern)

Angenommen, Sie wollen, daß in einem ”

Article“ die Gleichungen innerhalb jeder ”

Section“ separat numeriert werden.

Im LATEX-Manual finden Sie den Hinweis, daß der ”

| | Report“-Style etwas
Ahnliches pro ¨
”
| Chapter“ macht.

Sie schauen das File report.cls an und finden darin die folgenden zwei Befehle, die sich – wie in den Kommentarzeilen angegeben ist – auf die Gleichungsnummern beziehen:

\@addtoreset{equation}{chapter} \def\theequation{\thechapter .\arabic{equation}}
% In LaTeX2e ab 1995/06/01: \renewcommand\theequation{\thechapter.\@arabic\c@equation}

Es ist nicht notwendig, daß sie diese beiden Befehle in allen Details ver-
stehen, es genugt, wenn Sie erkennen, daß sich ¨ | | chapter in beiden Fällen
auf die Numerierung pro Kapitel bezieht.

Sie legen ein File mit dem Namen eqpersec.sty an,⁶ kopieren die Befehle in dieses File, ersetzen darin konsequent chapter durch section und erhalten also die neuen Definitionen

6 Je nach dem Computer, an dem Sie arbeiten, kann der Filename eine andere Syntax haben, z. B. EQPERSEC_STY an einer CYBER unter NOS/VE.

% Dies ist equation_per_section.sty
% Kurzname: eqpersec.sty
%
% Gleichungszaehler am Anfang einer section
% zuruecksetzen.
\@addtoreset{equation}{section}
% Gleichungsnummer = sectionnummer.equationnummer \def\theequation{\thesection .\arabic{equation}}
% oder:
\renewcommand\theequation{\thesection.\@arabic\c@equation}

Naturlich f ¨ ugen Sie auch noch Kommentarzeilen hinzu, die den Zweck ¨ des Files erklären und Ihren Namen als den Autor dieses neuen Style-Option-Files sowie das Anderungsdatum angeben. ¨

Wann immer Sie nun in Ihrem LATEX-Eingabefile die Package eqpersec angeben, z. B. mit

\documentclass[11pt]{article}
\usepackage{eqpersec}

dann werden die Gleichungen in Ihrem Artikel nach dieser neuen Konvention numeriert.

### 3.6 Ein etwas komplexeres Beispiel (Reference Manual)

Wir wollen ein ähnliches Seiten-Layout wie beim PostScript Reference Manual erreichen: mit einem breiten linken Rand, der fur ¨ Uberschriften ¨ und Randnoten benutzt wird, und mit nur einem eher knappen freien ¨ Rand oben, rechts und unten.

Dies scheint eine sehr grundlegene Anderung zu sein. Durch die gute ¨ Modularität von LATEX sind aber auch fur eine solche Aufgabe nur relativ ¨ wenige Anderungen notwendig, die im folgenden komplett beschrieben ¨ werden.

3.6.1 Seitenaufteilung

Die neue Seitenaufteilung wird im wesentlichen mit den im LATEX-Manual beschriebenen Parametern festgelegt. In diesem Beispiel verwenden wir dazu die Plain-TEX-Befehle \newdimen, Wertzuweisung und \advance, wir könnten aber genausogut auch die entsprechenden LATEX-Befehle \newlength, \setlength und \addtolength verwenden.

Horizontal: | Zunächst definieren wir zwei neue Bezeichnungen fur Gr ¨ | ößen, die im fol-
| genden öfter verwendet werden:

\fullwidth gibt die komplette Breite (Textbreite + genutzter linker ¨ Rand) an und erhält denselben Wert wie in Plain TEX, nämlich 6.5 Inch, sodaß am Papier rechts und links noch jeweils 1 Inch freier Rand bleiben.
(Dies ist jetzt naturlich von der Papiergr ¨ | öße abhängig)

\leftmarginwidth gibt die Breite des Randes an, der links von der nor-
| malen Textbreite fur ¨ Uberschriften und Randnoten verwendet wird: ¨

leftmarginwidth = fullwidth − textwidth

Da die entsprechenden Maße in Abhängigkeit von der Papierbreite berechnet werden, möchte ich hier auf eine genaue Beschreibung verzichten.

Diese Class wurde mit dem docstrip-Programm erstellt und erlaubt es eine ausfuhrliche Dokumentation zu erzeugen. (Allerdings in Englisch) ¨

Vertikal: Das vertikale Layout wird abhängig von der Papierhöhe berechnet. Auch hier möchte ich auf die Dokumentation zur Class verweisen.

3.6.2 Kapitel-Uberschriften ¨

Die Uberschriften von Sections, Sub- und Subsubsections sollen so abge- ¨ ändert werden, daß sie in den linken Rand hinausragen.

Im File classes.dtx finden wir, daß diese Uberschriften durch Aufru- ¨ fe des Befehls \@startsection definiert sind, dessen Funktion auf den Kommentarzeilen beschrieben ist. Fur uns relevant sind nur folgende Pa- ¨ rameter: Der Absolutbetrag des vierten und des funften Parameters gibt ¨ den Abstand vor bzw. nach der Uberschrift an. Der sechste Parameter ¨
gibt an, wie der Text der Uberschrift gesetzt werden soll. Der Befehl f ¨ | ur ¨
Sections ist z. B. im Original so definiert:

\newcommand\section{\@startsection
{section}{1}{\z@}%
{-3.5ex plus -1ex minus -.2ex}% {2.3ex plus .2ex}%
{\normalfont\Large\bfseries}}

und analog die Befehle fur Sub- und Subsubsections. Die Anpassung an ¨ die jeweilige Schriftgröße erfolgt automatisch durch die Verwendung der relativen Einheit ex.

Wir definieren zunächst eine Abkurzung ¨ | \secshape fur das neue Layout ¨
aller dieser Uberschriften. Die wesentliche ¨ | Anderung besteht darin, daß ¨
die Uberschriften um die Breite des linken Randes weiter links als der ¨ normale Text beginnen sollen. Zu diesem Zweck setzen wir den linken Rand auf die entsprechende negative Größe. Außerdem wollen wir, daß die Wörter in der Uberschrift nicht abgeteilt werden und daß deshalb rechts ¨ kein Randausgleich gemacht wird. Dies erreichen wir mit den folgenden Befehlen, die im TEXbook beschrieben sind:

\def\secshape{\leftskip=-\leftmarginwidth
\rightskip=0pt plus 1fil
\hyphenpenalty=2000}

Ein Aufruf dieses Befehls soll nun jeweils in den sechsten Parameter von \@startsection eingefugt werden. ¨

Da die Uberschriften durch das Hinausragen in den linken Rand deutlich ¨ genug vom normalen Text abgesetzt sind, mussen sie nicht durch so große ¨ Schrift und Abstände wie im Original hervorgehoben werden. Wir verkleinern daher auch noch die entsprechenden Angaben im vierten, funften ¨ und sechsten Parameter und erhalten schließlich die neue Definition

\newcommand\section{\@startsection
{section}{1}{\z@}%
{-2ex plus -1ex minus -.2ex}%
{0.5ex plus .2ex}%
{\secshape\normalfont\large\bfseries}}

und analoge neue Definitionen fur Sub- und Subsubsections. ¨

3.6.3 Positionierung der Randnoten

Die Positionierung der Randnoten muß so abgeändert werden, daß alle Randnoten in den linken Rand gesetzt werden – unabhängig davon, ob es sich um eine rechte oder linke Seite und um eine normale oder verkehrte Randnote handelt.

Im File latex.dtx finden wir die viele Zeilen lange Definition des Befehls \@addmarginpar, der das Setzen der Randnoten durchfuhrt. Wir brau- ¨ chen uns nicht um alle Details dieses komplizierten Befehls zu kummern, ¨ wir mussen nur eines herausfinden: Im ersten Teil des Befehls wird eine ¨ interne Größe \@tempcnta entweder auf \@ne oder auf \m@ne gesetzt, je nachdem, ob die Randnote rechts oder links vom Text gesetzt werden soll. Dazu dienen die folgenden Zeilen.

\@tempcnta\@ne
\if@twocolumn
\if@firstcolumn \@tempcnta\m@ne \fi \else
\if@mparswitch
\ifodd\c@page \else\@tempcnta\m@ne \fi \fi
\if@reversemargin \@tempcnta -\@tempcnta \fi \fi

Diese Zeilen ersetzen wir also einfach durch die Zuweisung

\@tempcnta\m@ne

Die restlichen Zeilen, die das eigentliche Setzen der Randnote je nach dem Wert von \@tempcnta an die richtige Stelle der Seite bewirken, lassen wir unverändert.

3.6.4 Erweiterungen

Die hier angefuhrten Definitionen gen ¨ | ugen durchaus f ¨ | ur einfache Anwen- ¨
dungen. In der Praxis können allerdings noch einige Erweiterungen nutz- ¨
lich sein. Ein Beispiel fur eine solche ¨ | ”
→ B | komplette“ Style-Option ist in An-
hang B beschrieben.

Anhang

A Die Seitenaufteilung in LATEX

In diesem Anhang wird angegeben, aus welchen Komponenten der Seitenaufbau besteht und wie die einzelnen Parameter in LATEX definiert sind
→ Abb. 1 | (siehe auch Abbildung 1, die von Nelson Beebe an der University of Utah
erzeugt wurde).

Textbereich : Der normale Textbereich (”

Body“) umfaßt den laufenden Text einschließlich Fußnoten, Tabellen und Abbildungen. Nicht zu diesem Bereich gehören Kopfzeilen, Fußzeilen und Randnoten.

Der Textbereich hat die Breite \textwidth und die Höhe \textheight.

Bei zweispaltiger Ausgabe enthält der Textbereich zwei Spalten, die jeweils \columnwidth breit sind, und zwischen ihnen einen Abstand der Breite \columnsep. Die Spaltenbreite \columnwidth ist also etwas geringer als die Hälfte von \textwidth.

\textwidth bzw. \columnwidth soll ein Vielfaches der Buchstabenbreite des tt-Fonts sein.

\textheight soll ein Vielfaches der Zeilenhöhe \baselineskip, vermehrt um die Konstante \topskip, sein.

Innerhalb des Textbereichs werden Einruckungen mit ¨ | \leftskip
und \rightskip festgelegt. Diese beiden Größen sollen nicht explizit verändert werden sondern nur implizit durch die Environments.

linker Rand : Der Rand links vom Textbereich ist um 1 Inch mehr als \odd- bzw. \evensidemargin, je nachdem ob die Seitennummer ungerade oder gerade ist. Normalerweise sind beide Größen gleich, nur bei der Option twoside werden rechte (=ungerade) und linke (=gerade) Seiten verschieden gesetzt.

oberer Rand : Der Rand oberhalb des Textbereichs ist um 1 Inch mehr als die Summe von \topmargin, \headheight und \headsep.

rechter Rand : Der Rand rechts vom Textbereich ergibt sich aus der Papierbreite minus der Breite von linkem Rand und Textbereich.

unterer Rand : Der Rand unterhalb des Textbereichs ergibt sich aus der Papierhöhe minus der Höhe von oberem Rand und Textbereich.

Kopfzeilen : Kopfzeilen (”

Header“) stehen innerhalb des oberen Randes, und zwar so, daß zwischen dem unteren Rand der Kopfzeile und dem oberen Rand des Textbereichs der Abstand \headsep bleibt. Oberhalb der Kopfzeile bleibt ein freier Rand von 1 Inch mehr als \topmargin.

Fußzeilen : Fußzeilen (”

Footer“) stehen innerhalb des unteren Randes, und zwar so, daß der Abstand vom unteren Rand des Textbereichs zum unteren Rand der Fußzeile \footskip ist.

Randnoten : Randnoten (”

Margin Notes“) stehen innerhalb des rechten oder linken Randes. Sie haben eine Breite von \marginparwidth, und zwischen den Randnoten und dem Textbereich bleibt ein horizontaler Abstand von \marginparsep. Der vertikale Abstand zwischen aufeinanderfolgenden Randnoten ist mindestens \marginparpush.

Die Papierhöhe setzt sich also von oben nach unten aus folgenden Elementen zusammen:

1 Inch
\topmargin
\headheight
\headsep
\textheight
\footskip
Rest der Seite

Bei Seiten mit rechten Randnoten – was der Standardfall ist – setzt sich die Papierbreite von links nach rechts aus folgenden Elementen zusammen:

1 Inch
\oddsidemargin bzw. \evensidemargin \textwidth
\marginparsep
\marginparwidth
Rest der Seite

Bei der Option twoside besteht die Seitenbreite von linken Seiten mit linken Randnoten aus folgenden Elementen:

1 Inch
\evensidemargin
\textwidth
Rest der Seite
Anmerkungen: | Die Größen \topmargin, \oddsidemargin und \evensidemargin können auch negative Werte haben, dann ergibt sich an der betreffenden Stelle ein Rand von weniger als 1 Inch. Auch \leftskip und \rightskip kön- nen negative Werte haben, dann ragt der Text entsprechend aus dem Textbereich heraus. Ausfuhrlichere Hinweise und Skizzen zu diesem The- ¨ ma findet man unter anderem in der Zeitschrift TUGboat Vol.9, No.1 (April 1988).
| Die Größe \footheight ist in LATEX2e nicht mehr definiert, da sie an- scheinend von niemandem benutzt wurde.

Abbildung 1: Seiten-Layout

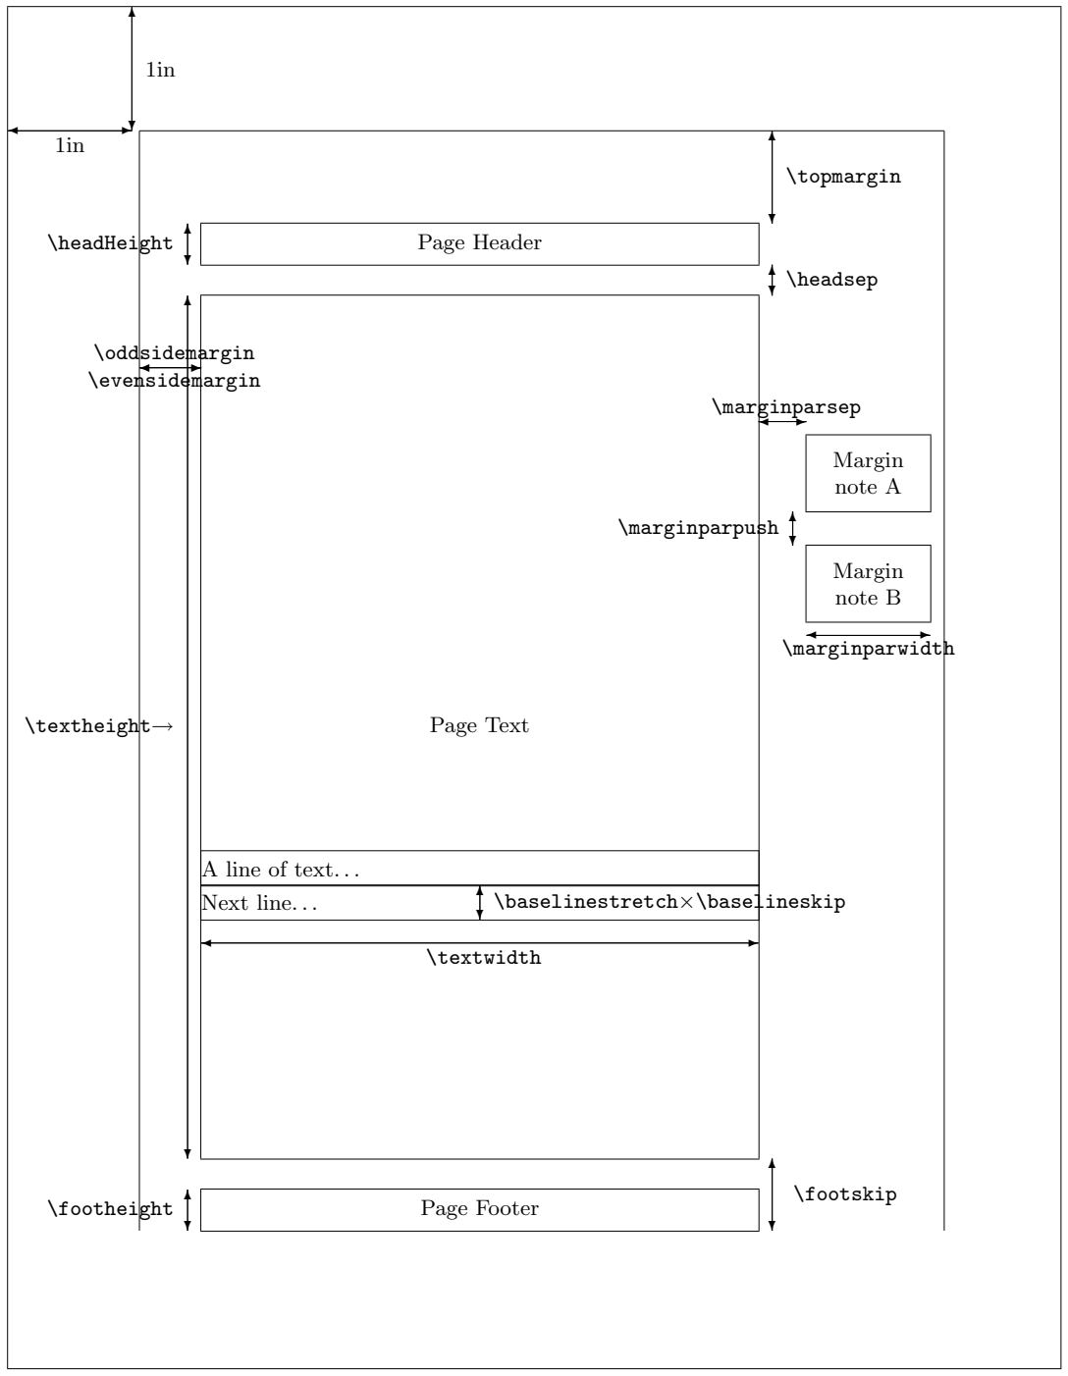
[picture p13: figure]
A line of text. . .; \oddsidemargin ✛; \evensidemargin; Page Text; Page Footer ❄; \footheight; \footskip; \textwidth; \textheight→; \headHeight; ✻❄\headsep; \topmargin; Page Header; Margin note A; \marginparpush ✻❄; Margin note B; \marginparwidth; \marginparsep ✛✲

Next line. . . | ✻❄\baselinestretch×\baselineskip

B Beschreibung der Dokumentklasse Refman

Am EDV-Zentrum der TU Wien wurde – aufbauend auf den in den
vorangegangenen Kapiteln angefuhrten Grunds ¨ | ätzen – eine Style-Option
refman zu den LATEX-Styles article und report entwickelt, die ein Layout fur Reference Manuals, technische Beschreibungen und dergleichen ¨ realisiert. Das Layout entspricht im wesentlichen den Angaben in Abschnitt 3.6: Die normalen Textseiten haben einen breiten linken Rand,
der fur ¨ Uberschriften und Randnoten ben ¨ | utzt wird, und nur einen eher ¨
knappen freien Rand oben, rechts und unten.

Fur L ¨ ATEX2e wurde diese Option in eine echte Class umgewandelt. Dadurch ist es leichter möglich, verschiedene Papierformate zu unterstuzen. ¨ Außerdem gibt es neben der report-ähnliche refrep-Class eine article-ähnliche refart-Class, die sich durch andere Einträge in Kopf- und Fuß-Zeile sowie das Fehlen der Gliederungsebene chapter von refrep unterscheidet.

Die derzeitige Version dieser Class wird im folgenden kurz in Hinblick auf ihre Anwendeung beschrieben. Dies soll gleichzeitig als Beispiel dafur ¨
dienen, welche Anderungen und zus ¨ | ätzliche Komponenten ein typischer
neuer LATEX-Style enthalten kann.

Das vorliegende Handbuch wurde mit der Documentclass refart gesetzt. Es ist also gleichzeitig ein Beispiel fur das von dieser Class bewirkte Lay- ¨ out.

B.1 Aufruf

Im LATEX Local Guide ist jeweils angegeben, ob und wo dieses oder ein ähnliches Class-File in einer bestimmten LATEX-Installation verfug- ¨ bar ist. Der Aufruf erfolgt durch die Angabe der Class refart im Befehl \documentclass, also z. B. mit

\documentclass[11pt,a4paper]{refart}
\usepackage{german}

B.2 Optionen

Die Class refart ersetzt die Class article und die Class refrep die Class report. Sie kann nicht mit der folgenden Option verwendet werden: twocolumn.

Da es sich jetzt um eine selbstständige Class handelt, sind folgende Optionen möglich: landscape, square sowie die aus den Standard–Classes bekannten Papiergrößen-Optionen a4paper, a5paper oder auch die Op-
tionen fur amerikanische Formate. Die ¨ | square-Option erzeugt ein qua-
dratisches Layout, bei dem die Höhe auf die Papierbreite begrenzt wird.

Sie kann auch mit zahlreichen anderen Optionen kombiniert werden, auch
z. B. mit twoside oder fleqn. Die Option titelpage erzeugt bei der refart-Class eine eigene Titelseite. Bei der Class refrep ist dies die Standardeinstellung.

Die Classes refart und refrep unterstutzen nur die einspaltige Ausgabe, ¨ die Befehle \twocolumn und \onecolumn können in diesem Fall nicht verwendet werden.

Der Index wird automatisch zweispaltig gesetzt. Das Layout entspricht hier dem der Standard–Classes, allerdings mit kleinen Uberschriften wie ¨ im Rest des Dokumentes.

B.3 Layout-Anderungen ¨

B.3.1 Seitenaufteilung

Horizontal: | Die komplette genutzte Breite ( ¨ | \fullwidth) berechnet sich so, daß am
Papier rechts und links noch jeweils 1 Inch freier Rand bleiben. Die Zeilenlänge des normalen Textes (\textwidth) und alle davon abgeleiteten Größen betragen 70% der \fullwidth. Die Breite des Randes (\leftmarginwidth), der links vom normalen Textbereich fur ¨ Uberschrif- ¨ ten und Randnoten verwendet wird, ergibt sich aus der Differenz von
| \fullwidth und \textwidth.
Vertikal: | Die Texthöhe berechnet sich so, daß ein oberer und unterer Rand von
1 Inch bleibt. Manche Pagestyles verwenden einen anderen Wert fur den ¨
| oberen Rand. (siehe B.4.3).

Mit der Option smallborder wird der Rand auf 0,25 Inch verringert.

Der Rand kann durch den Befehl \setlength\papermarginwidth{0.25in} umdefiniert werden, danach ist der Befehl \setpagefraction{0.7} aufzurufen, um das neue Layout zu berechnen. Dies funktioniert nur in der Präambel. Die Blattgröße wird dem DVI-Treiber mitgeteilt, wenn die Option pagesize angegeben wird.

Es wird kein vertikaler Randausgleich gemacht (\raggedbottom).

B.3.2 Kapitel-Uberschriften ¨

| Die Uberschriften von ¨ | \section, \subsection und \subsubsection ver-
wenden die gesamte Seitenbreite, d. h. sie ragen in den linken Rand hin-
| aus. Dafur werden kleinere vertikale Abst ¨ | ände vor und nach den Uber- ¨
schriften und eine weniger große Schrift verwendet. In den Uberschriften ¨ werden keine Wortabteilungen und kein rechter Randausgleich gemacht.

Beim Style refart werden die von \maketitle und \part erzeugten
| Uberschriften im folgenden Layout gesetzt: Sie stehen am Beginn einer ¨
neuen Seite (\clearpage), verwenden die gesamte Breite und sind von zwei waagrechten Linien eingeschlossen. Der Befehl \maketitle setzt die
Uberschrift ( ¨ | \title) und den Autor (\author). Der Befehl \makeauthor,
| wird nicht mehr unterstutzt. Beim Befehl ¨ | \part wird nur die römische
Nummer des Abschnitts vor den Text gesetzt (ohne das Wort ”
| | Part“ oder
| ” Teil“).
Beim Style refrep werden Kapitel-Uberschriften ( ¨ | \chapter) im folgen-
den Layout gesetzt: Sie stehen am Beginn einer neuen Seite (\clearpage), verwenden die gesamte Breite und sind von zwei waagrechten Linien eingeschlossen. Die Befehle \maketitle und \part bleiben in diesem Style unverändert, es wird aber empfohlen, sie in ein Fullpage-Environment
| (siehe B.5.5) einzuschließen.

B.3.3 Absätze

Absätze werden durch einen vertikalen Abstand (\parskip) von einer hal-
ben Zeile getrennt, ohne horizontale Einruckung ( ¨ | \parindent ist Null).
Der vertikale Abstand enthält einen ”
| | stretchable“ Anteil von ” plus 2pt“;
dies vergrößert die Wahrscheinlichkeit, daß LATEX die am besten geeigne-
| ten Stellen fur alle Seitenwechsel findet. ¨

Die vertikalen Abstände in den List-Environments sind so gesetzt, daß sich vor, nach und innerhalb der Environments jeweils derselbe Abstand wie zwischen den normalen Absätzen ergibt.

B.4 Fußnoten

Das Layout der Fußnoten wurde an das Absatzlayout angepast, d. h. auch die Fußnoten werden ohne Einzug in der ersten Zeile gesetzt.

B.4.1 Description-Environment

Das description-Environment ist so abgeändert, daß die Item-Labels den gesamten linken Rand verwenden.

→ Kapitel 3 | Beispiele dafur finden sich unter anderem in Kapitel 3. ¨

B.4.2 Positionierung der Randnoten

Randnoten (\marginpar) werden stets in den linken Rand gesetzt und verwenden dessen gesamte Breite.

Der minimale vertikale Abstand zwischen Randnoten (\marginparpush) ist auf Null gesetzt, damit möglichst keine Verschiebung von Randnoten erfolgt.

B.4.3 Kopf- und Fußzeilen, Pagestyles

Beim Pagestyle plain werden die Seitennummern in der Fußzeile jeweils ganz rechts bzw. (auf linken Seiten bei der Option twoside) ganz links außen gesetzt.

Bei den Pagestyles headings und myheadings wird ebenfalls die gesamte Breite verwendet, und unter die Kopfzeile wird eine waagrechte Linie gesetzt. Beim Pagestyle headings enthält die Kopfzeile beim refart
die \section-Uberschrift auf der linke und die ¨ | \subsection-Uberschrift ¨
auf der linken Seite, beim refrep die \chapter-Uberschrift auf der linken ¨ und die \section-Uberschrift auf der rechten Seite. Die Schrift wird in ¨ schräger (slanted) Schrift gesetzt.

Seit Version 2.0 e wird fur die erste Seite eines Kapitels der Pagesty- ¨ le empty anstelle von plain verwendet. Bei Verwendung des Pagestyles headings kamm es zu seltsamen Effekten, wenn die erste Seite mit den Pagestyle plain gesätzt wurde.

Zusätzlich sind auch Pagestyles footings und myfootings definiert, die entsprechende Fußzeilen (mit einer waagrechten Linie daruber) setzen. ¨ Beispiel: Die folgenden Befehle setzen den Kurztitel des Schriftstucks in ¨ die Fußzeile:

\pagestyle{myfootings}
\markboth{Kurztitel}{Kurztitel}

Die Pagestyles headings und myheadings setzen den oberen Rand auf einen etwas größeren Wert, um die leere Fußzeile auszugleichen. Die Pagestyles footings und myfootings setzen den oberen Rand auf einen etwas kleineren Wert, um die leere Kopfzeile auszugleichen. Die Pagestyles empty und plain lassen den Rand unverändert. Daraus ergibt sich: Innerhalb eines Schriftstucks kann manentweder zwischen den Pagestyles ¨ headings, myheadings und empty
oder zwischen den Pagestyles footings, myfootings und empty wechseln, aber man sollte nicht zwischen footings- headings- und plain Seiten wechseln.

B.5 Zusätzliche Befehle

B.5.1 Marginlabel

Der Befehl \marginlabel{xxx} setzt das Wort oder den Text | xxx
rechtsbundig in den linken Rand. Dies kann f ¨ | ur Stichworte, kurze ¨ | Uber- ¨
schriften von Absätzen oder ähnliches verwendet werden.

Das Wort ”

Beispiel: | Beispiel:“ links von diesem Absatz ist ein Beispiel fur einen ¨
Marginlabel.

B.5.2 Attention

Der Befehl \attention setzt ein Ausrufungszeichen in den linken Rand. Dies dient zum Markieren wichtiger Absätze oder Sätze.

! → Das ist ein Beispiel fur ¨ \attention.

:-) Seit Version 2.0c ist es möglich das Symbol fur den ¨ | | \attention Befehl
mit Hilfe von \renewcommand{\attentionsymbol}{\texttt\{:-)\}} zu verändern. Mit \renewcommand{\attentionsymbol}
{\large \bfseries ! $\rightarrow$} wird wieder auf das Originalverhalten zuruckgeschaltet. ¨
Zusätzlich unterstutzt der ¨ | \attention Befehl ein optionales Argument
um das Symbol im Rand einmalig durch ein anderes zu ersätzen. In diesem
Fall ist es nicht notwendig, das \attentionsymbol zuruckzus ¨ | ätzen. Diese
Erweiterung dient vor allem zur Unterstutzung f ¨ | ur das ¨ | manfnt Paket und
:-( sollte nicht zur Erzeugung eines bunten Layouts mißbraucht werden.

Mit dem manfnt Paket existiert eine einfache Möglichkeit, um auf die Symbole des manfnt Zeichensatzes zuzugreifen. Dieser Zeichensatz enthält u.a. das ”

Dangerous Bend“ und ”

Double Dangerous Bend“ Zeichen.

B.5.3 Seealso

Der Befehl \seealso{n} markiert einen Verweis auf ein Kapitel oder eine Abbildung.

Beispiele dafur finden sich nicht nur hier (am linken Rand) sondern unter ¨
→ Kapitel 1 | anderem auch in Kapitel 1.

B.5.4 Maxipage-Environment

Das maxipage-Environment ist eine Art von ”
Minipage“, die sich uber ¨ die gesamte Seitenbreite erstreckt. Es eignet sich z. B. fur ¨ uberlange ma- ¨ thematische Gleichungen oder breite Tabellen innerhalb des Textes oder in ”

Floats“ (table oder figure). Innerhalb der ”
| | Maxipage“ sind kei-
ne Seitenwechsel und keine Randnoten möglich. Beginn und Ende des maxipage-Envrionment bewirken jeweils einen neuen Absatz und eine waagrechte Linie.

Hier folgt nun ein Beispiel fur eine Maxipage. ¨

Diese uberlangen Zeilen sind der Inhalt der Maxipage. Sie erstrecken sich ¨ | uber die gesamte Seitenbreite, ¨
ohne linken Rand.

Dies ist der normale Text nach dem Ende der Maxipage.

B.5.5 Fullpage-Environment

Das fullpage-Environment besteht aus einer oder mehreren Seiten, bei denen sich der Text uber die gesamte Seitenbreite erstreckt und kein ¨ linker Rand bleibt. Randnoten sind darin nicht möglich. Beginn und Ende des fullpage-Envrionment bewirken jeweils einen Seitenwechsel (\clearpage).

Dies eignet sich fur Spezialseiten wie mehrseitige große Tabellen, Pro- ¨ grammlistings, Titelseiten, Inhaltsverzeichnisse und ähnliches.

→ Seite 15 | Seite 15 ist ein Beispiel fur eine Fullpage. ¨

B.5.6 Noparskip

Der Befehl \noparskip entfernt den vertikalen Abstand vor einem Absatz – analog zum Befehl \noindent, der die horizontale Einruckung am ¨ Beginn eines Absatzes entfernt.

B.5.7 Setleftmarginwidth

Der Befehl \setleftmarginwidth wird nicht mehr unterstutzt. Statt- ¨ dessen kann mit dem Befehl \settextfraction der Anteil des Textes (normalerweise 70 %) geändert werden. Das Argument muß zwischen 0 und 1 liegen.

B.5.8 Descriptioncolon

Der Doppelpunkt in einer description kann durch den Befehl \descriptioncolonfalse ab und durch \descriptioncolontrue wieder eingeschaltet werden. Im
Normalfall ist der Doppelpunkt eingeschaltet.

B.5.9 Descriptionleft

Mit \descriptionlefttrue wird der Label fur eine ¨ | description links-
bundig in den Rand gesetzt. Der Normalfall ist rechtsb ¨ | undig, dies wird ¨
durch \descriptionleftfalse erreicht.

B.5.10 Maxipagerule

Mit \maxipagerulefalse lassen sich die Striche vor und nach einer maxipage abschalten. Sie sind normalerweise aktiv.

B.5.11 Condbreak

Mit \condbreak{2cm} wird sichergestellt, daß die nächsten 2 cm nicht getrennt werden. Sie erscheinen entweder auf der aktuellen Seite oder werden komplett auf die neue Seite umgebrochen.

B.5.12 Example

Die example-Umgebung erzeugt eine verse-Umgebung, schaltet allerdings auf tt und versucht einen Seitenumbruch vor der Umgebung zu vermeiden.

B.5.13 Pageperchapter

Der Befehl \pageperchapter erzeugt eine kapitelweise Seitennumerierung. Dies ist besonders fur umfangreiches Reference Manuals sinnvoll. ¨
Da nur refrep uber die Gliederungsebene ¨ | chapter verfugt, ist dieser ¨
Befehl auch nur hier möglich.

B.5.14 Smallborder

Der normale Seitenrand beträgt 1 inch (25,4 mm). Das ist fur ein ge- ¨ drucktes Dokument in Ordnung, fur die Betrachtung auf dem Monitor ¨ aber verschwendete Bildschirmfläche. Die Option smallborder reduziert den Rand auf 0,25 inch (6,35 mm). Damit klebt der Text noch nicht am Rand, es wird aber auch nicht zu viel Bildschirmfläche verschenkt.

Der Rand kann durch den Befehl \setlength\papermarginwidth{0.25in} umdefiniert werden, danach ist der Befehl \setpagefraction{0.7} aufzurufen, um das neue Layout zu berechnen.

B.5.15 Dvips

Die Option dvips teilt DVIPS die aktuelle Blattgröße mit.

B.5.16 Pdftex

Die Option pdftex teilt PDFTEX die aktuelle Blattgröße mit.

B.5.17 Pagesize

Pagesize wählt automatisch den passenden Befehl fur den jeweiligen DVI- ¨ Treiber. Dies funktioniert bei DVIPS und DVIPDFMX fur DVI-Ausgabe ¨ und PDFTEXfur PDF-Ausgabe. ¨

B.5.18 Ifpdfoutput

Mit dem Befehl \ifpdfoutput{pdftext}{dvitext} können Texte abhängig vom Ausgabeformat gesätzt werden. Die Option pagesize nutzt diesen Befehl.

Die letzten vier Befehle wurden aus KOMA-Script ubernommen, vielen ¨ Dank Markus!

Index
a4paper, 16
Attention, 19
Attentionsymbol, 19
Autor, 3

Condbreak, 20

Description-Environment, 18 Descriptioncolon, 20
Descriptionleft, 20
Design, generisches, 6
Design, logisches, 6
Design, visuelles, 6
Designer, 3
Dvips, 21

Example, 20

Faustregeln, 4
Footings, 18
Fullpage, 20
Fußzeilen, 5, 13

Headings, 18
House-Style, 4

Ifpdfoutput, 21

Kopfzeilen, 5, 13

Landscape, 16
Layout-Anderungen, Vorgangsweise, 7 ¨ Layout-Design, 4

manfnt, 19
Manual, 4
Marginlabel, 19
Maxipage, 19
Maxipagerule, 20
Myfootings, 18
Myheadings, 18

Optionen, 16

Pageperchapter, 21
Pagesize, 21
Pagestyles, 18
Pdftex, 21

Randnoten, 5, 13
Refart,Aufruf, 16
Refart.cls, 16
Refrep,Aufruf, 16
Refrep.cls, 16
Regeln, 4

Seealso, 19

Seitenaufbau, 4
Seitenaufteilung, horizontal, 17 Seitenaufteilung, vertikal, 17 Setleftmarginwidth, 20
Setzer, 3
Smallborder, 21
Square, 16

Telefonbuch, 4

Zeilenabstände, 4
Zeilenlänge, 4

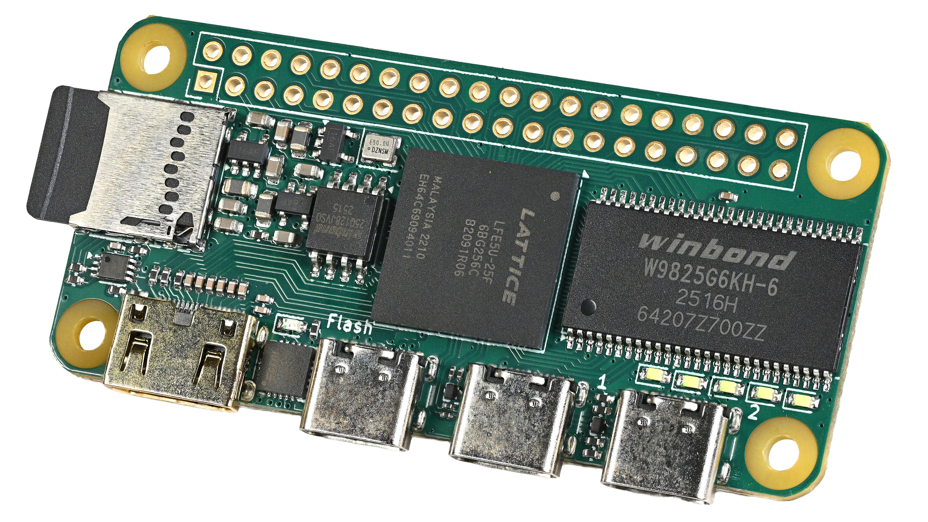
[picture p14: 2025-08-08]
gallery/icepi-zero-angle.jpg

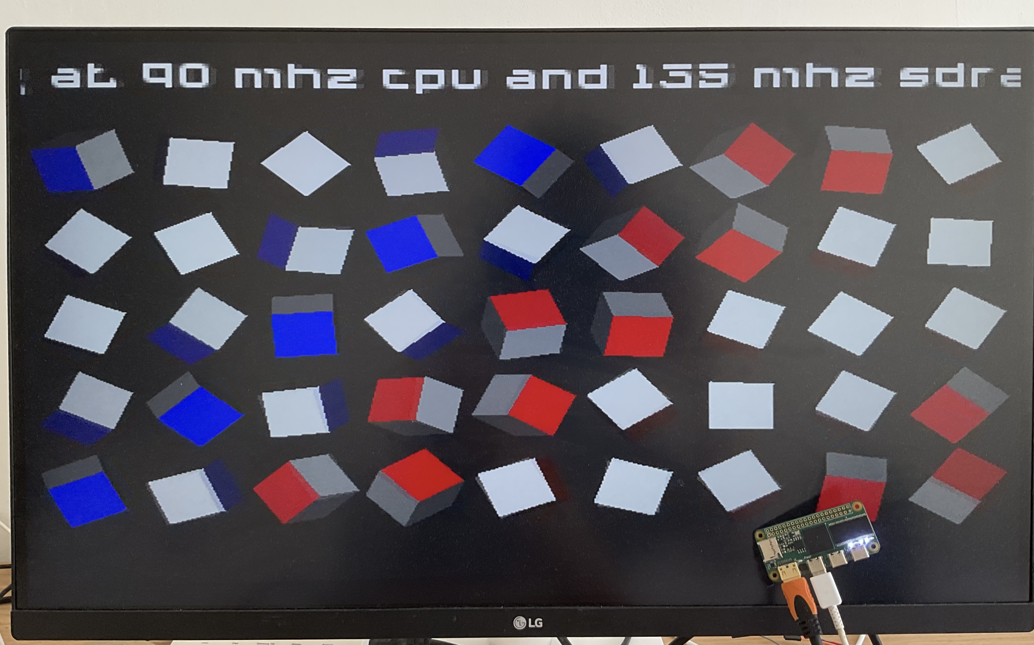
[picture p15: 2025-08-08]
gallery/fire-v-silice-riscv-core-on-icepi.jpg

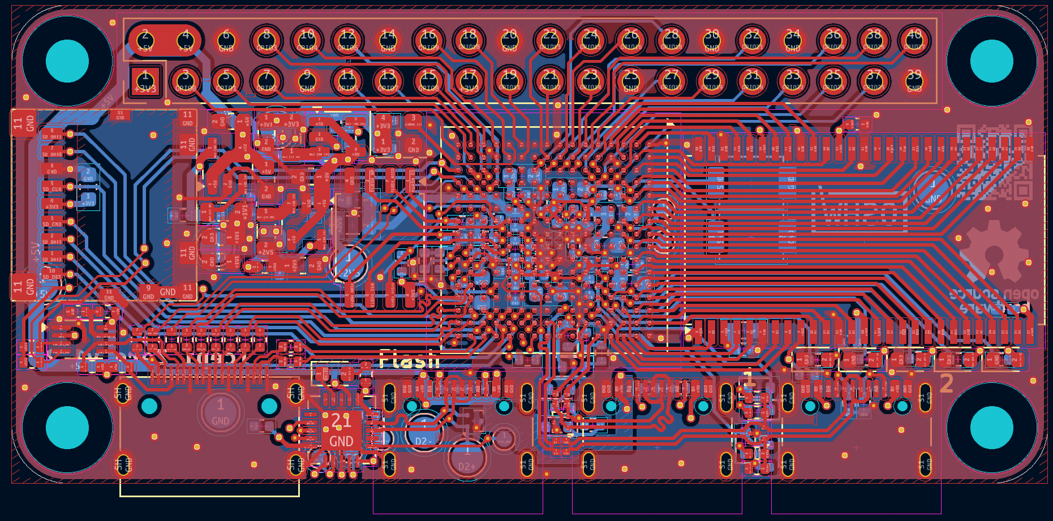
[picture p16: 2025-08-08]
gallery/pcb-editor-view.jpg

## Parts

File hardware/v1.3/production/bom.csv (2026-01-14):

Designator | Footprint | Quantity | Value | LCSC Part #
C1, C10, C14, C16, C17, C20, C24, C25, C26, C27, C28, C29, C31, C32, C35, C44, C5, C6, C7, C8, C9 | 0402 | 21 | 100nF | C307331
C11, C12, C13, C18, C19, C33, C45 | 0603 | 7 | 22uF | C59461
C15, C2, C21, C22, C23, C3, C30, C34, C4, C53, C54 | 0603 | 11 | 10uF | C19702
C36, C37, C38, C39, C40, C41, C42, C43 | 0402 | 8 | 22nF | C1532
C46, C47, C48, C49, C50, C51, C52 | 0603 | 7 | 22nF | C77571
D1, D2, D3, D4, D5 | 0603 | 5 | WHITE | C2290
D10, D11, D12, D13, D6, D7, D8, D9 | D_SOD-523 | 8 | 1N914WT | C2836064
D14 | 0603 | 1 | RED | C2286
FB1 | 0805 | 1 | 100R@100MHz | C74480
J2 | XKB Connection A71-05H4-111N1 | 1 | GPDI_C_1.3 | C2682170
J3, J4, J5 | USB_C_Receptacle_GCT_USB4105-xx-A_16P_TopMnt_Horizontal | 3 | USB_C_Receptacle_USB2.0_14P | C2765186
J6 | microSD_HC_SOFNG_TF-008 | 1 | Micro_SD_Card_Det2 | C428465
L1, L2, L3 | 0805 | 3 | 2.2uH | C107322
R1, R2, R20, R21, R3, R32, R33, R4, R42, R5 | 0402 | 10 | 1k | C11702
R10, R22, R23, R34, R35, R48, R49, R50, R8 | 0402 | 9 | 15k | C25756
R11, R18, R19 | 0402 | 3 | 3.3k | C25890
R12, R14 | 0402 | 2 | 470 | C25117
R13, R44, R45, R46, R47, R6 | 0402 | 6 | 10k | C25744
R15 | 0402 | 1 | 100k | C25741
R16, R17, R38, R39, R40, R41, R43, R9 | 0402 | 8 | 4.7k | C25900
R24, R25, R26, R29, R36, R37 | 0402 | 6 | 5.1k | C25905
R27, R28, R30, R31 | 0201 | 4 | 27 | C473051
R7 | 0402 | 1 | 12k | C25752
SW1, SW2 | switch_button_TS-1088-AR02016 | 2 | SW_Push | C720477
U1 | BGA-256_14.0x14.0mm_Layout16x16_P0.8mm_Ball0.45mm_Pad0.32mm_NSMD | 1 | ECP5-CABGA256 | C1521614
U10, U5, U7, U8 | Texas_DRT-3 | 4 | TPD2EUSB30A | C3011197
U11 | TSOP-II-54_22.2x10.16mm_P0.8mm | 1 | W9825G6KH | C62246
U12 | SOIC-8_5.3x5.3mm_P1.27mm | 1 | W25Q128JVS | C97521
U2, U3, U4 | SOT-23-5 | 3 | TLV62569DBV | C141836
U6 | VSSOP-8_2.3x2mm_P0.5mm | 1 | PCA9306DC1 | C129510
U9 | QFN-20-1EP_4x4mm_P0.5mm_EP2.5x2.5mm | 1 | FT231XQ | C132159
Y1 | Oscillator_SMD_SiT_PQFN-4Pin_2.5x2.0mm | 1 | SG-8018CG 50.000000MHz | C390526

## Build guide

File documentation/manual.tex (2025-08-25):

\documentclass{article}

\begin{document}
\title{Icepi Zero Regulatory Compliance and safety information}

\maketitle

Product name: Icepi Zero

\textbf{WARNINGS}

- This product shall only be powered by an certified external power supply rated at 5V DC, with an minimum current of 1A.

- This product should be operated in a well ventilated environment and should not be covered.

- This product should be placed on a stable, flat, non-conductive surface in use and should not be contacted by conductive items.

- The connection of unapproved devices to the GPIO connector may affect compliance or result in damage to the unit and invalidate the warranty.

- All peripherals used with the Icepi Zero should comply with relevant standards for the country of use and be marked accordingly to ensure that safety and performance requirements are met. These articles include but are not limited to keyboards, monitors, and mice used in conjunction with the Icepi Zero. 

- Do not expose it to water, moisture or place on a conductive surface whilst in operation.

- Do not expose it to heat from any source; the Icepi Zero is designed for reliable operation at normal ambient room temperatures.

- Take care whilst handling to avoid mechanical or electrical damage to the printed circuit board and connectors.

- Avoid handling the printed circuit board while it is powered. Only handle by the edges to minimise the risk of
electrostatic discharge damage.

\end{document}

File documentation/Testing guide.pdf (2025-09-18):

# Icepi Zero Testing Guide

## Setup

Download the following bitstream file: https://github.com/cheyao/icepi-zero/raw/refs/heads/main/documentation/fire-v.bit

## Testing

1. Plug in a USB-C data cable to the left-most USB port on the PCB. (One next to the HDMI port, labeled Flash). Connect the other end to a PC/laptop. Also use a micro-HDMI to HDMI cable to connect the HDMI port to a monitor.
2. Open https://ofl.trabucayre.com/ in Google Chrome (Firefox does NOT work)
3. On the bottom left, in the “Automatic Operations” section, select the following options:

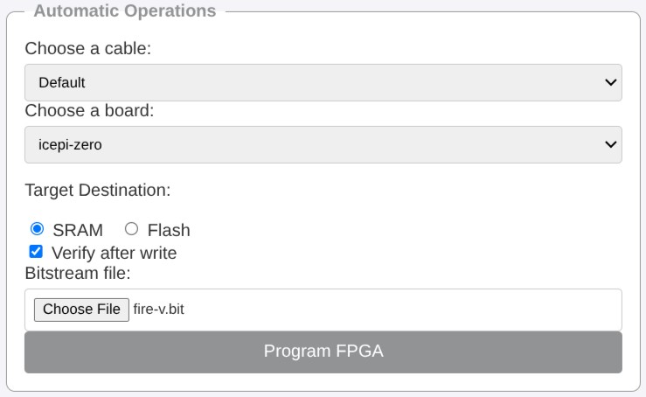
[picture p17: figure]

(Click “Choose File” and select the fire-v.bit file downloaded during setup)
4. Click on “Program FPGA” and select “FT231X USB UART” in the popup menu and click connect:

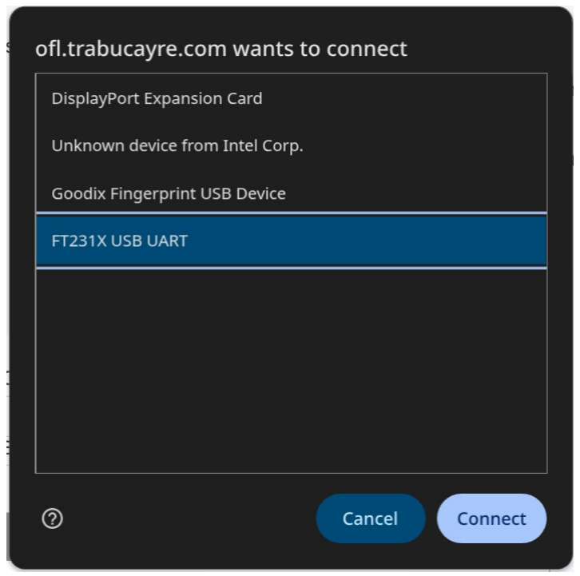
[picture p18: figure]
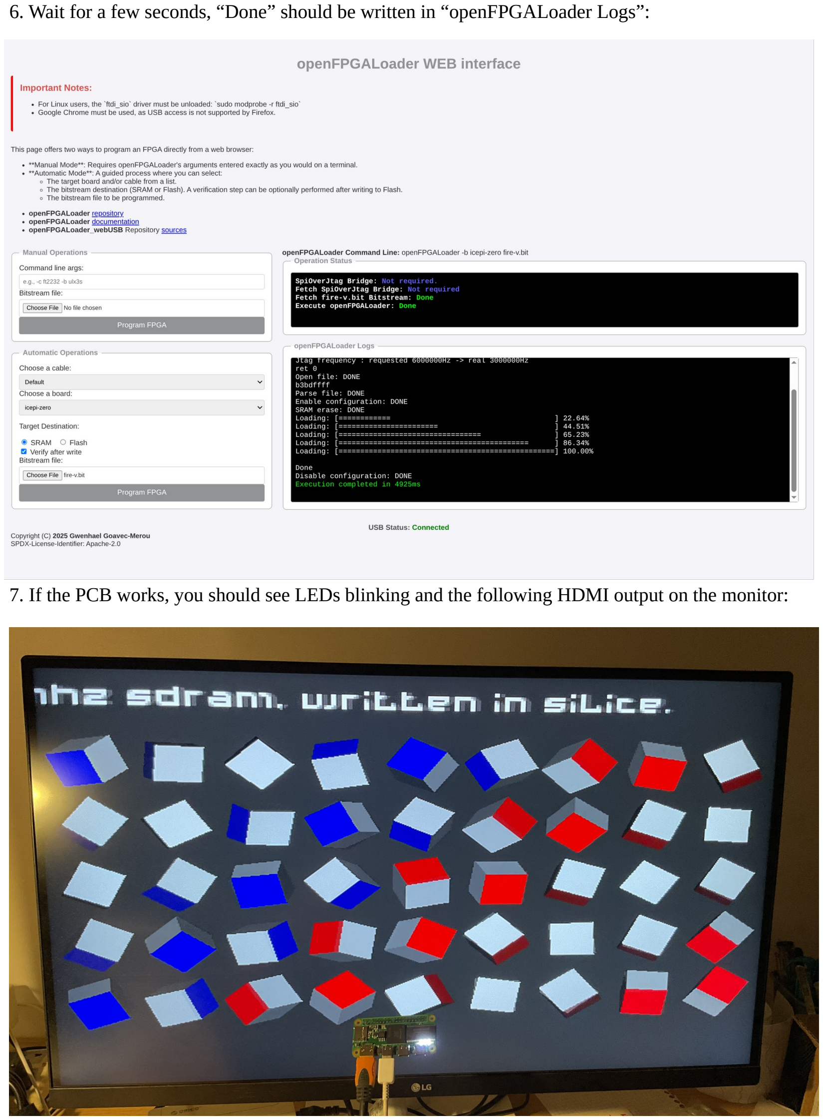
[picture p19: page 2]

6. Wait for a few seconds, “Done” should be written in “openFPGALoader Logs”:
7. If the PCB works, you should see LEDs blinking and the following HDMI output on the monitor:

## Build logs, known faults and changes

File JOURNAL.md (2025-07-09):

# From nothing to Icepi

## The start

I'll write a bit about my journey here :D

The journey all started when Hackclub's onboard live program was going to end. I've had 100$ worth of grants left, so I thought furiously about what I wanted - and the answer is a FPGA.

I've always wanted a FPGA from when I was 13, but they were just too expensive for me. So I've took the simplest ICE40 and made this, called anice:



Not bad tbh, went through multiple revisions. Got these boards and found out I made a few design errors though:

- I used an crystal instead of an crystal oscillator in the clock footprint
- The flashing half-works, idk how I designed it

Also it has few big flaws:

- It needed an external programmer
- It only has 4k LUTs
- Doesn't have enough built-in I/Os
- Missing a GPDI port!

The missing GPDI port was the biggest problem for me as I wanted to make my own CPU and OS on it :)

https://www.reddit.com/r/PrintedCircuitBoard/comments/1jzs6o1/review_ice40_development_board/

So it was time to rack the intensity up!

## Objective: Icepi Zero

I've decided to use the ECP5 on my second prototype, for it's open source toolchain and it's price.

This was my original prototype:




It was called anice and had a rpi-like factor, like way larger then a rpi. I sent this to review on reddit:

https://www.reddit.com/r/PrintedCircuitBoard/comments/1k7v7yk/review_request_ecp5_development_board/

Wow, I got so much feedback (and found so many imperfections). Off to v2 I go!

I've compleatly restarted the project - this time found a better uSD slot in order to fit my board on a true rpi footprint, and rerouted everything from zero:

WIP icepi

After a few days of blood and sweat (~And not studying for exams~), this is the final result I got:

Pre-alpha Icepi Zero

Looks awesome! I've also showcased this on the KiCAD Discord:

500 messages on the Discord thread,,, wow

The people in that community were super helpful, spotted quite a few errors for me: The thread ended up containing ~600 messages :O just wow.

With the help of some people on reddit and Max from our Hackclub slack, I've finished the v1.0 of the Icepi Zero (Check out Max's awesome [Tiny4FSK](https://github.com/New-England-Weather-Balloon-Society/Tiny4FSK)!)

V1.0 Icepi Zero

This isn't actually v1.0, I ended up rerouting like 4 times in the process.

pre-v1.0

Praying that this works, I did one last check in the morning, and off to production you go!

V1.0 order

I've tried to receive some funding to elevate the cost: I've contacted pcbway for sponsoring, they agreed to sponsor the PCBs, but not the PCBA. Aaand their PCBA was actually more costly then that of jlcpcb.

## Shipping off the project

After verifing that the basic functionallity works, I've started to actually *ship* my project. The first step was posting on reddit:

- https://www.reddit.com/r/electronics/comments/1kwwwm0/i_built_the_fpga_raspberry_pi_zero_equivalent/
- https://www.reddit.com/r/embedded/comments/1kwx5p7/i_built_the_fpga_raspberry_pi_zero_equivalent/
- https://www.reddit.com/r/PrintedCircuitBoard/comments/1kwxf7y/thanks_for_the_reviews_icepi_zero_came_back/
- https://www.reddit.com/r/FPGA/comments/1kwxvk8/ive_made_my_first_fpga_board_the_icepi_zero/
- https://www.reddit.com/r/raspberry_pi/comments/1kxag0m/i_built_the_fpga_raspberry_pi_zero_equivalent/

Holy, that blew up. Seems like people were interested in the project :D

After that, I've found out that Hackaday had a tip line, so I sent my project in :) (https://hackaday.com/submit-a-tip/) and a few days later, guess what I saw on the front page:

https://hackaday.com/2025/05/29/icepi-zero-a-pi-zero-for-fpga/

OMG! Being on Hackaday was my dream! I was shaking with exitement.

In the few days that followed, one of my friends sent me this picture:

Hackernews vial

Oh wow! I went to Hackernews front page too! (Yea IK it's my account, I posted it, but didn't know it'll also get onto the front page :P)

I also had to make my certifications compleate, so I've submitted my project to OSHWA, and they gove me an open source hardware certification!

https://certification.oshwa.org/fr000026.html

26th open source project of France... Wild.

After that, I've continued working on the Icepi, fixing numerous errors and ending up with the v1.3 of the Icepi.

Current V1.3 Icepi Zero

Currently I've ordered a batch of the Icepi Zero v1.3! Really exited ^.^



And v3 came!



## Off to the market

At the same time of working on my project, I've applied to Crowd Supply, and guess what? They have accepted me!

## Special thanks

Here at the end, I offer my profound thanks to Itai, for starting https://reflow.badbird.dev/, without which I would never have started this enourmous project.

Thanks to everyone who gave me a review on Reddit, for making me realize my flaws.

Thanks to Mpk and all the passionate engineers on the KiCAD Discord, for reviewing my PCB and instructing me on the aspects I lacked - without you the boards would never have worked.

Thanks to Echo, for helping me amass the funds for the first batch of boards. And at last Hackclub, for fostering such a great community of teen engineers.

Gratitude to Matthias, for making me realize my board's buissnes potential.

Also Acon for the cute pfp you drew :D

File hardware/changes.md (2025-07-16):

v1.3:

Swapped pins M1 and M2
PCLKC is not a clock pin :(
Like what :(

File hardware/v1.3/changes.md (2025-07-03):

Added USB pullup/down diodes
Reassigned a few pins

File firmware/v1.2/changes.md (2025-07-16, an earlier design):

Changed multiple pin assignments
Linked cts, dcd and ri to i/o pins
Changed hdmi to emmit less emc
Added aliases for sd card pins

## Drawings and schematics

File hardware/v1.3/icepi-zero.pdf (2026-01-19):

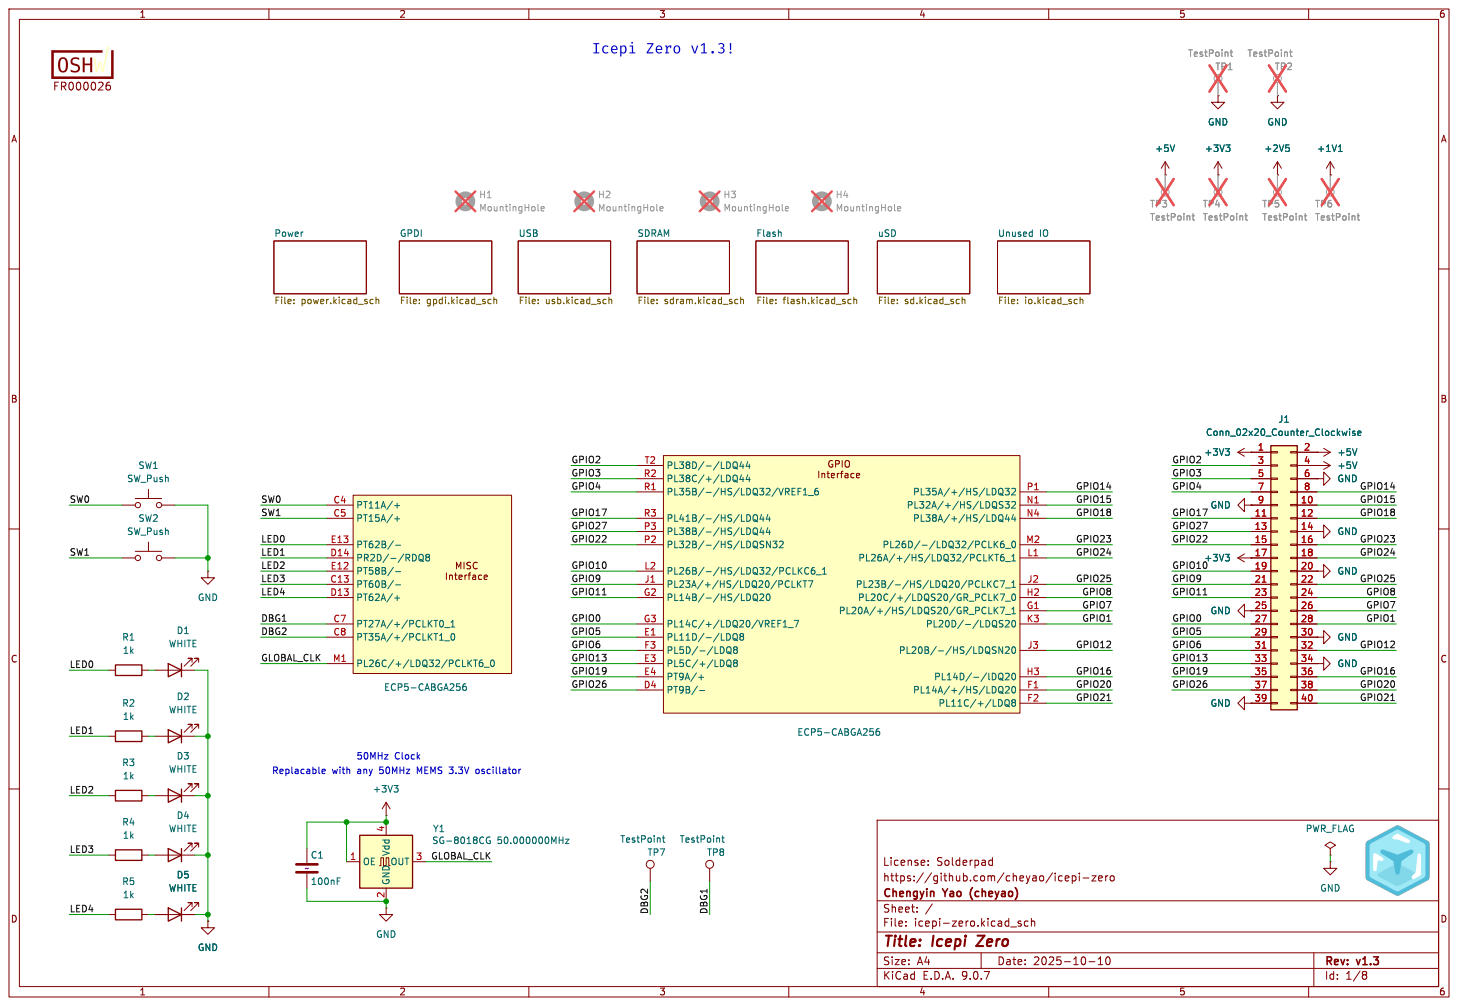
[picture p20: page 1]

License: Solderpad
https://github.com/cheyao/icepi-zero
File: icepi-zero.kicad_sch Sheet: / Chengyin Yao (cheyao)

Id: 1/8 Title: Icepi Zero

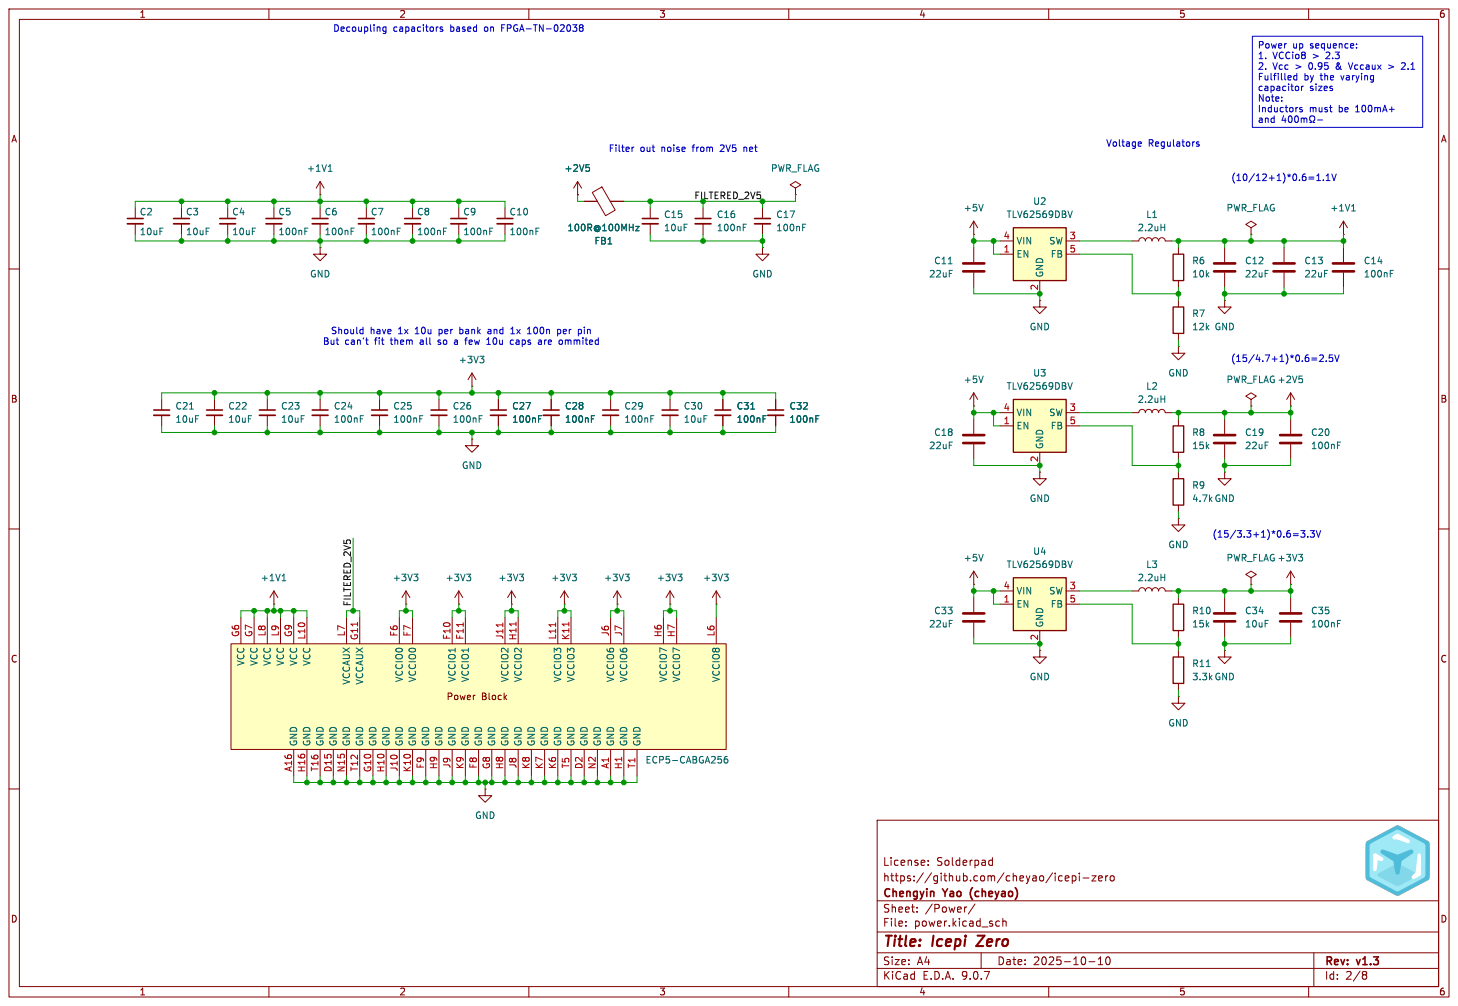
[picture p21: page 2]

License: Solderpad
https://github.com/cheyao/icepi-zero
File: power.kicad_sch Sheet: /Power/ Chengyin Yao (cheyao)

Id: 2/8 Title: Icepi Zero

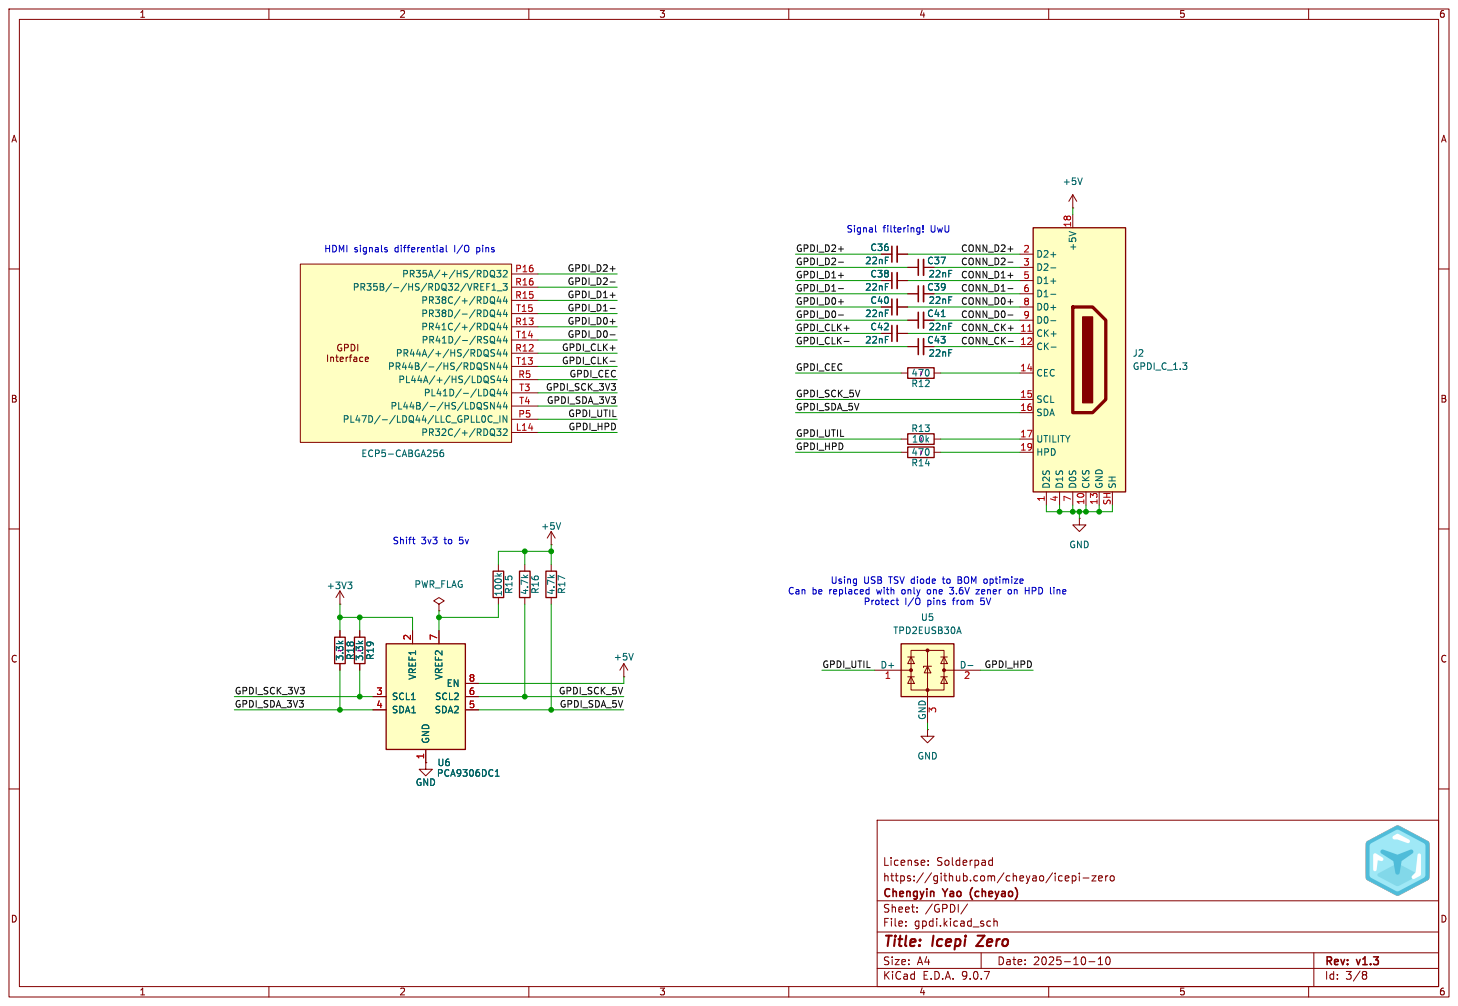
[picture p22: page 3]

License: Solderpad
https://github.com/cheyao/icepi-zero
File: gpdi.kicad_sch Sheet: /GPDI/ Chengyin Yao (cheyao)

Id: 3/8 Title: Icepi Zero

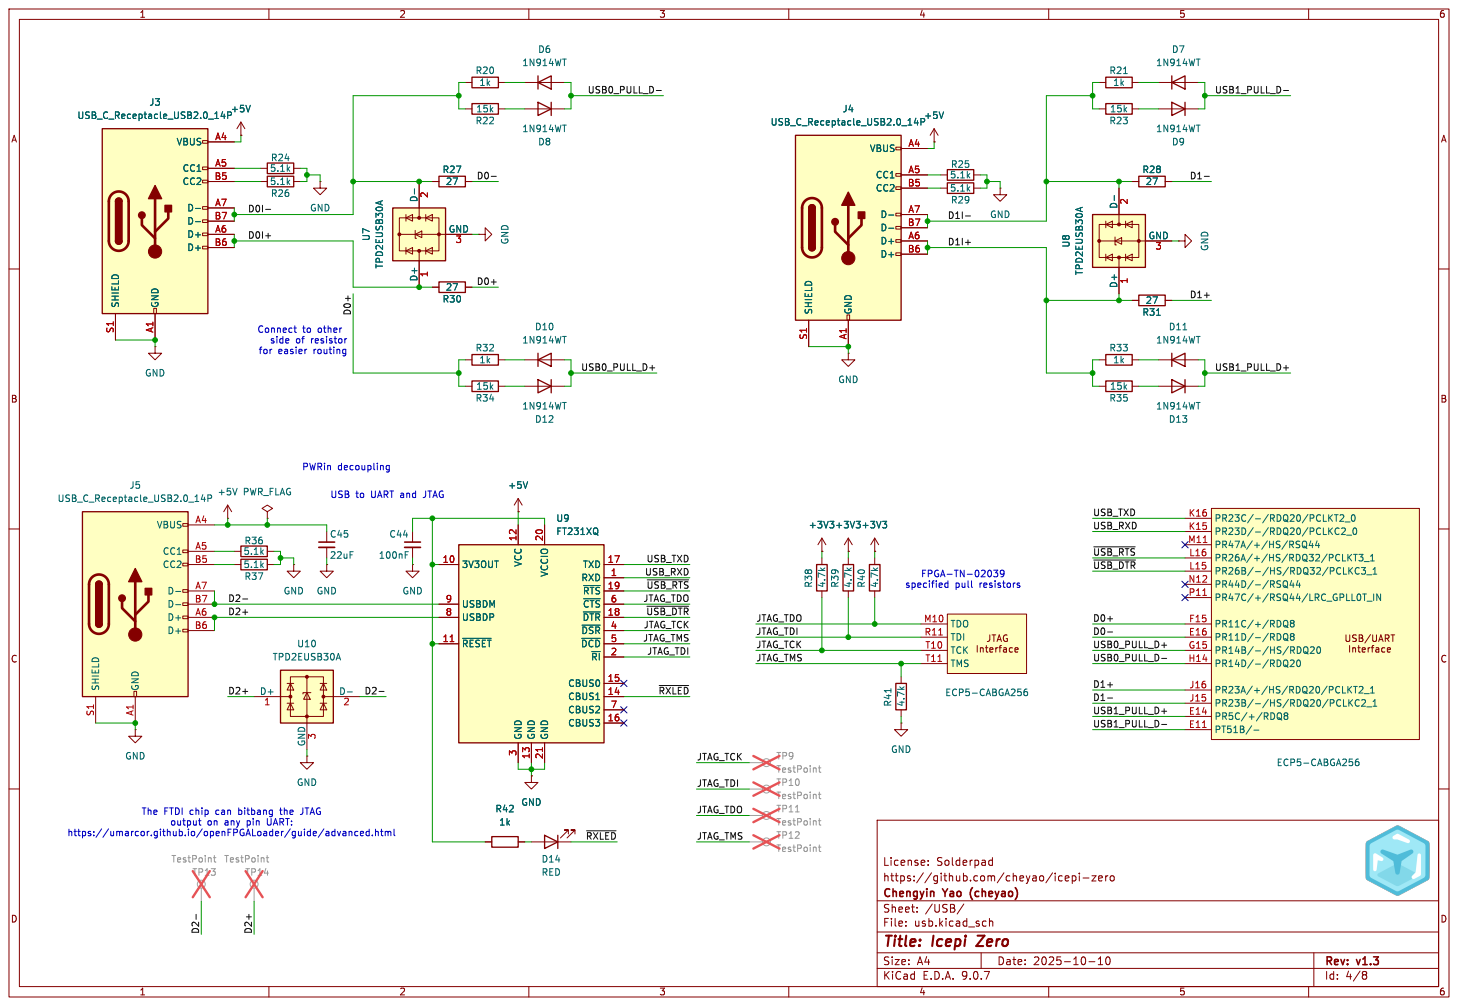
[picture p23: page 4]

3 GND 13 VCCIO 20 GND 21 TXD 17 RXD 1 ~{RTS}19 ~{CTS}6 ~{DTR}18 ~{DSR}4 ~{DCD}5 ~{RI}2 CBUS0 15 CBUS1 14 CBUS2 7 CBUS3 16 U9 FT231XQ

3 GND 13 VCCIO 20 GND 21 TXD 17 RXD 1 ~{RTS}19 ~{CTS}6 ~{DTR}18 ~{DSR}4 ~{DCD}5 ~{RI}2 CBUS0 15 CBUS1 14 CBUS2 7 CBUS3 16 GND

The FTDI chip can bitbang the JTAG

https://github.com/cheyao/icepi-zero
File: usb.kicad_sch Sheet: /USB/ Chengyin Yao (cheyao)

Id: 4/8 Title: Icepi Zero

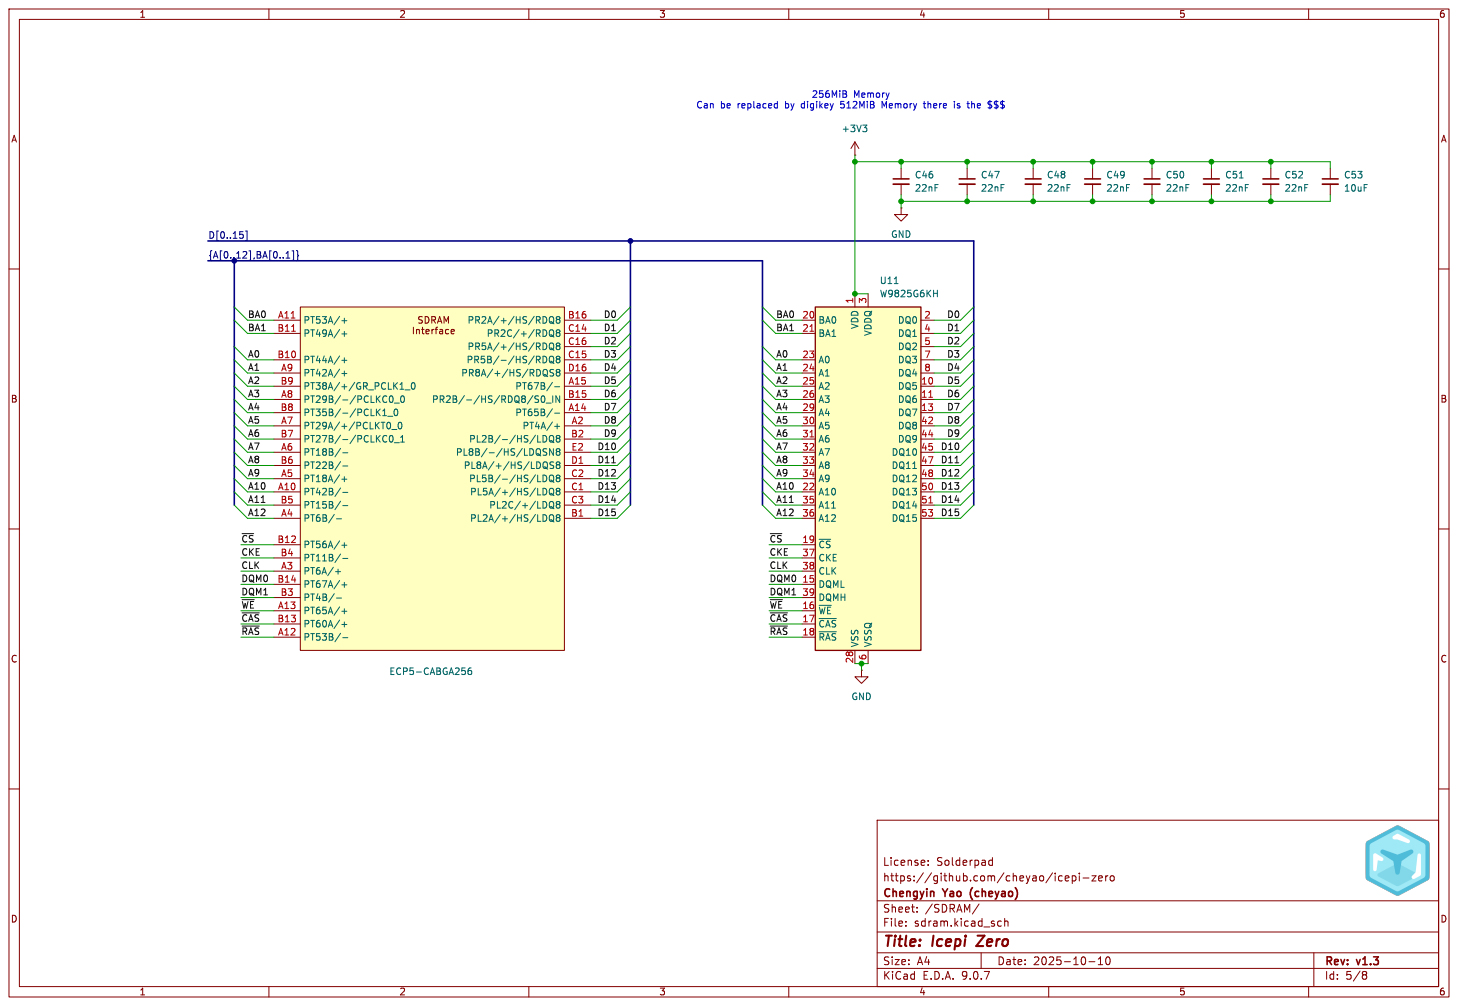
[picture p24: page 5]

License: Solderpad
https://github.com/cheyao/icepi-zero
File: sdram.kicad_sch Sheet: /SDRAM/ Chengyin Yao (cheyao)

Id: 5/8 Title: Icepi Zero

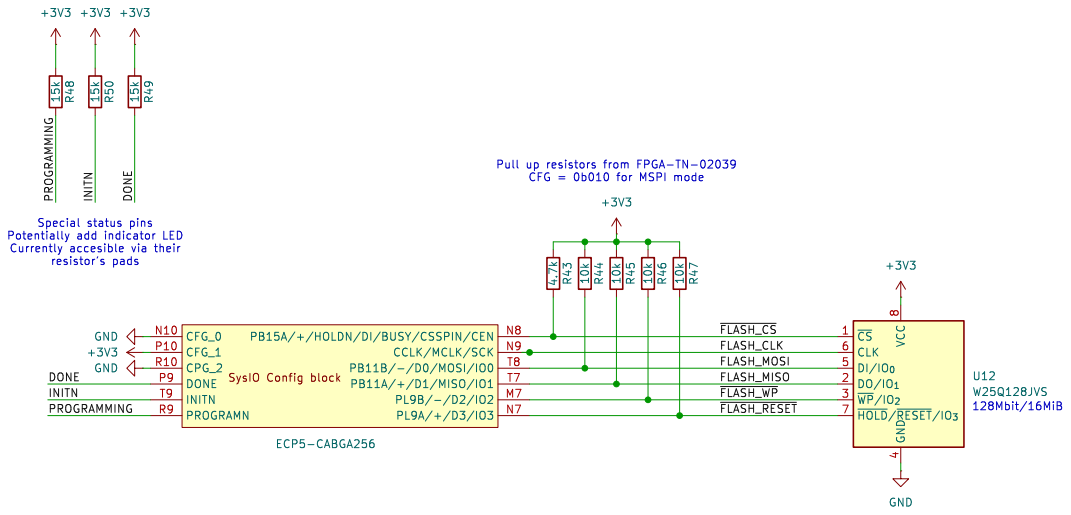
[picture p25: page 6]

https://github.com/cheyao/icepi-zero
File: flash.kicad_sch Sheet: /Flash/ Chengyin Yao (cheyao)

Id: 6/8 Title: Icepi Zero

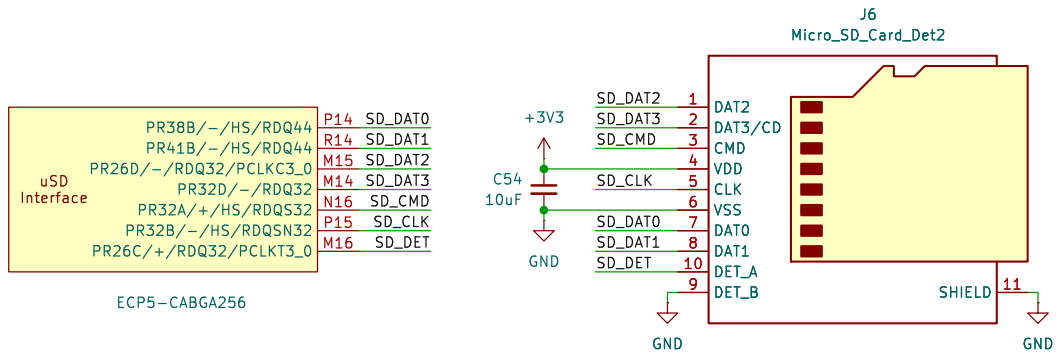
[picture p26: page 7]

https://github.com/cheyao/icepi-zero
File: sd.kicad_sch Sheet: /uSD/ Chengyin Yao (cheyao)

Id: 7/8 Title: Icepi Zero

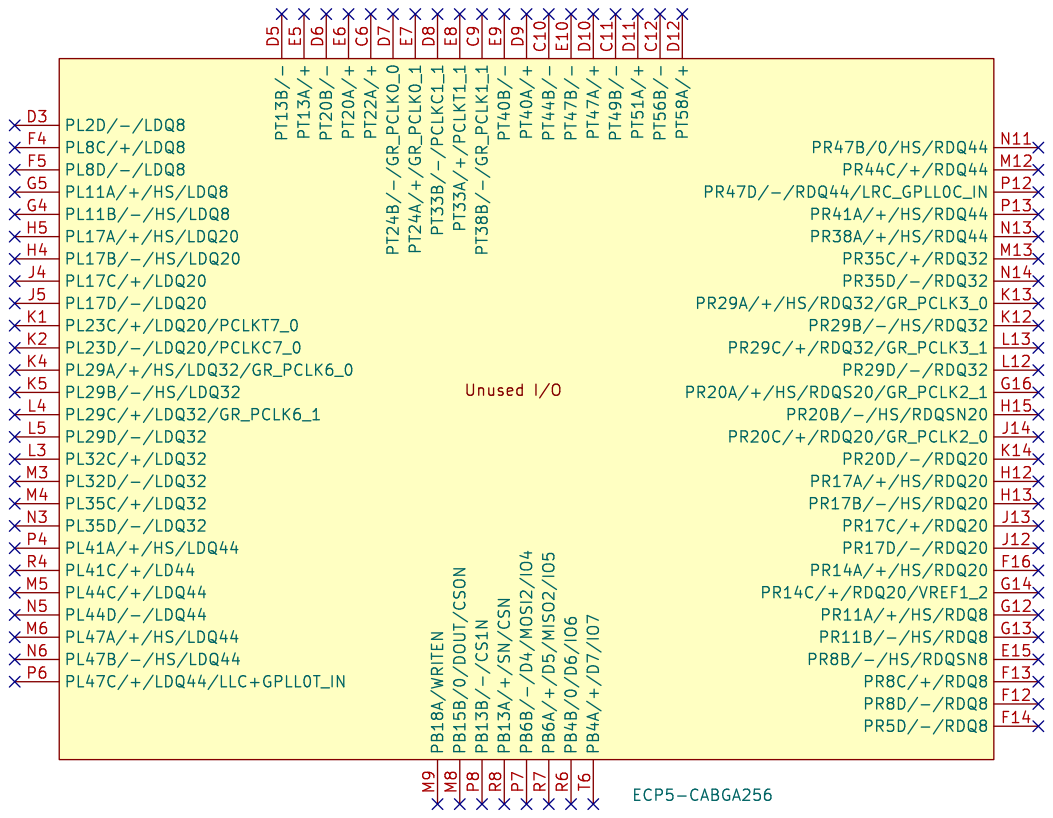
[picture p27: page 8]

https://github.com/cheyao/icepi-zero

Id: 8/8 Title: Icepi Zero

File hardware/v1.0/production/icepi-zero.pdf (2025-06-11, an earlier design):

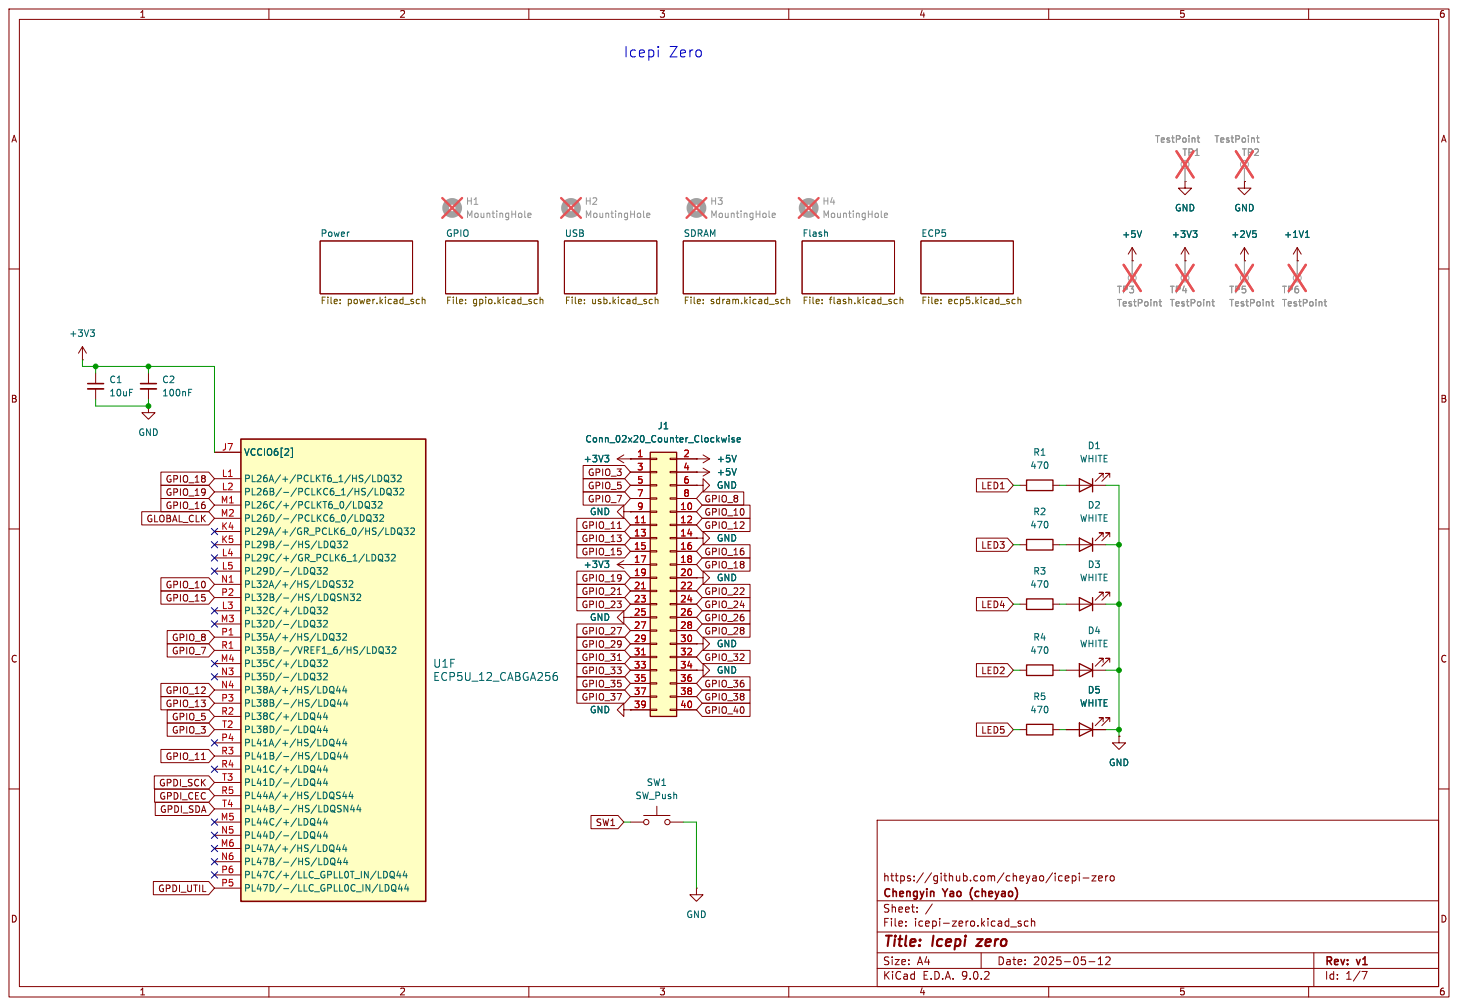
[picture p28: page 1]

TP1 TestPoint GND GND GND

Flash File: flash.kicad_sch GPIO

https://github.com/cheyao/icepi-zero
File: icepi-zero.kicad_sch Sheet: / Chengyin Yao (cheyao)

Id: 1/7 Title: Icepi zero

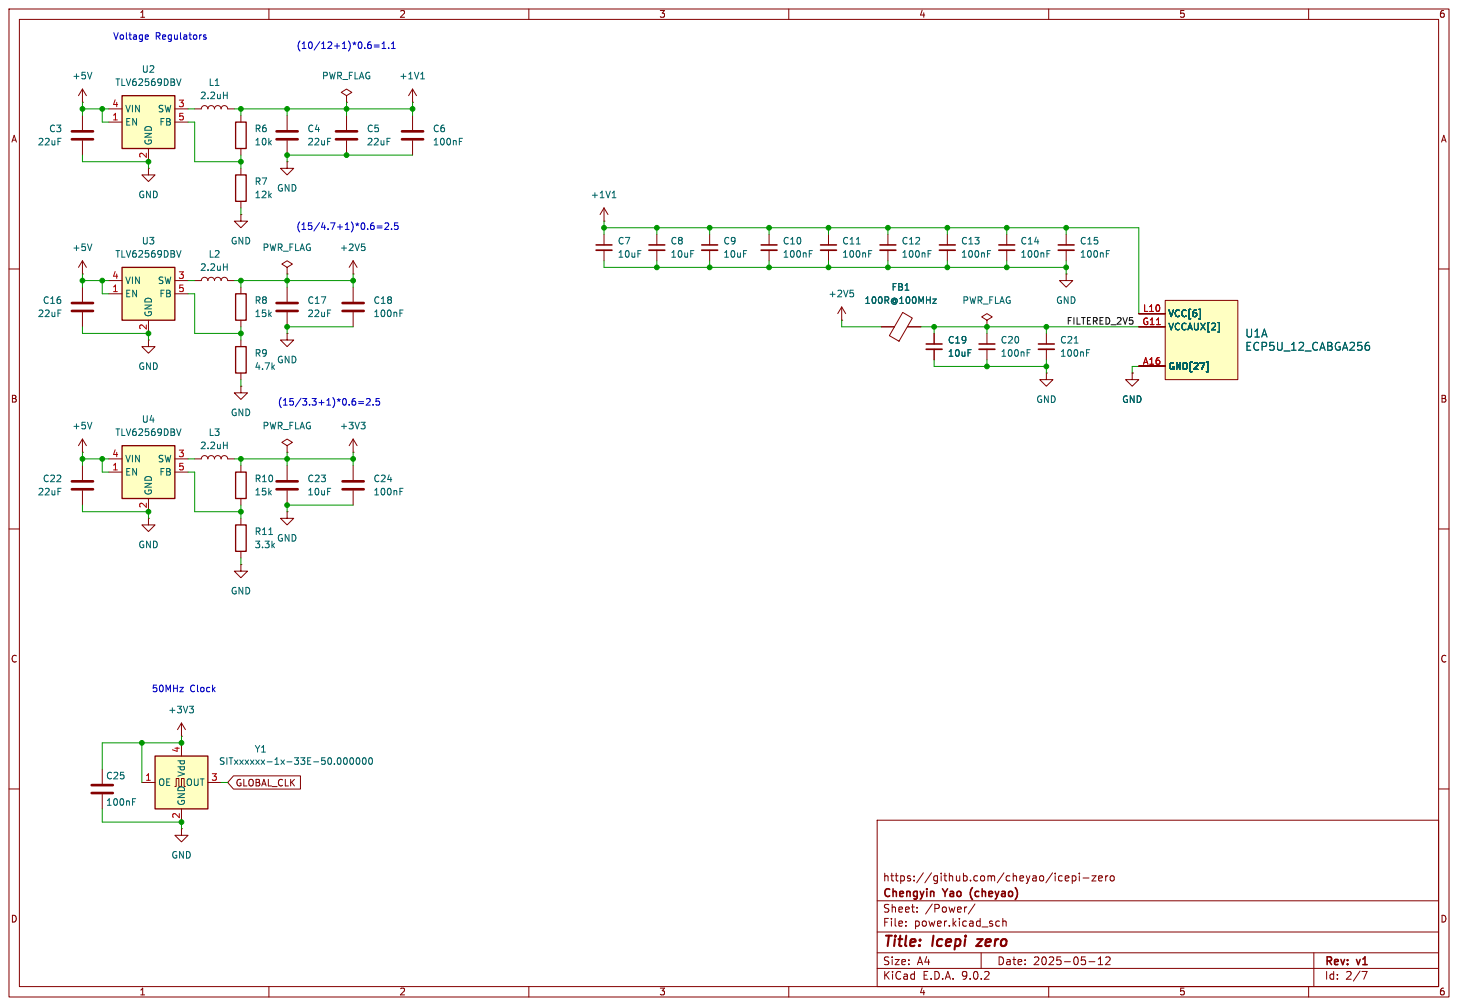
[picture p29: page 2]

https://github.com/cheyao/icepi-zero
File: power.kicad_sch Sheet: /Power/ Chengyin Yao (cheyao)

Id: 2/7 Title: Icepi zero

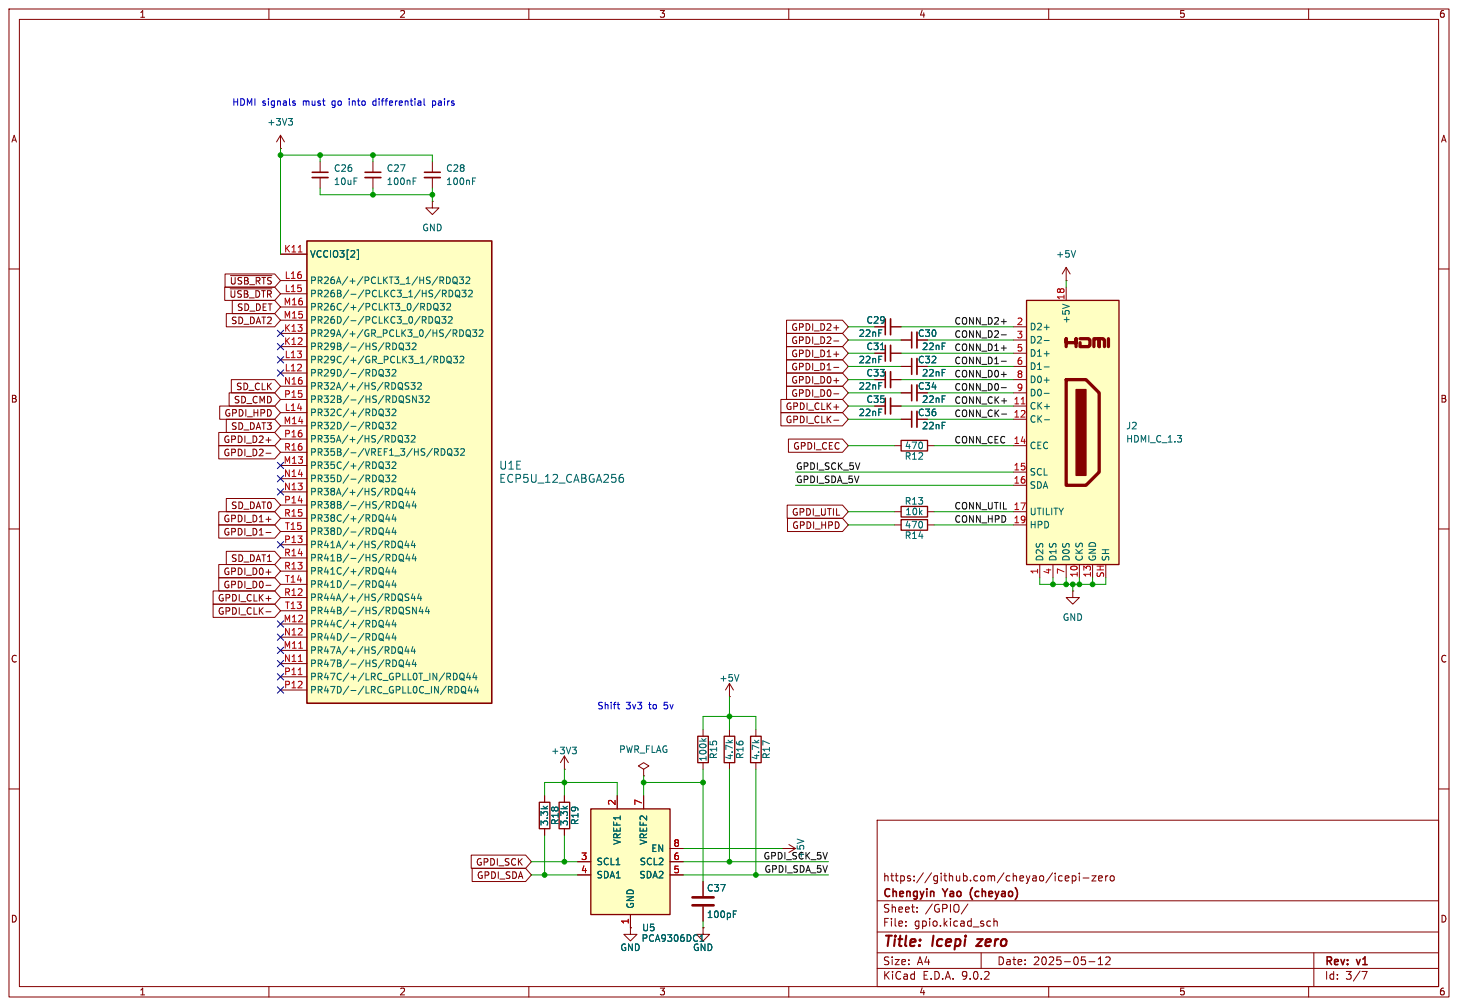
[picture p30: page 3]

https://github.com/cheyao/icepi-zero 3.3k R19

File: gpio.kicad_sch Sheet: /GPIO/ Chengyin Yao (cheyao)

Id: 3/7 Title: Icepi zero

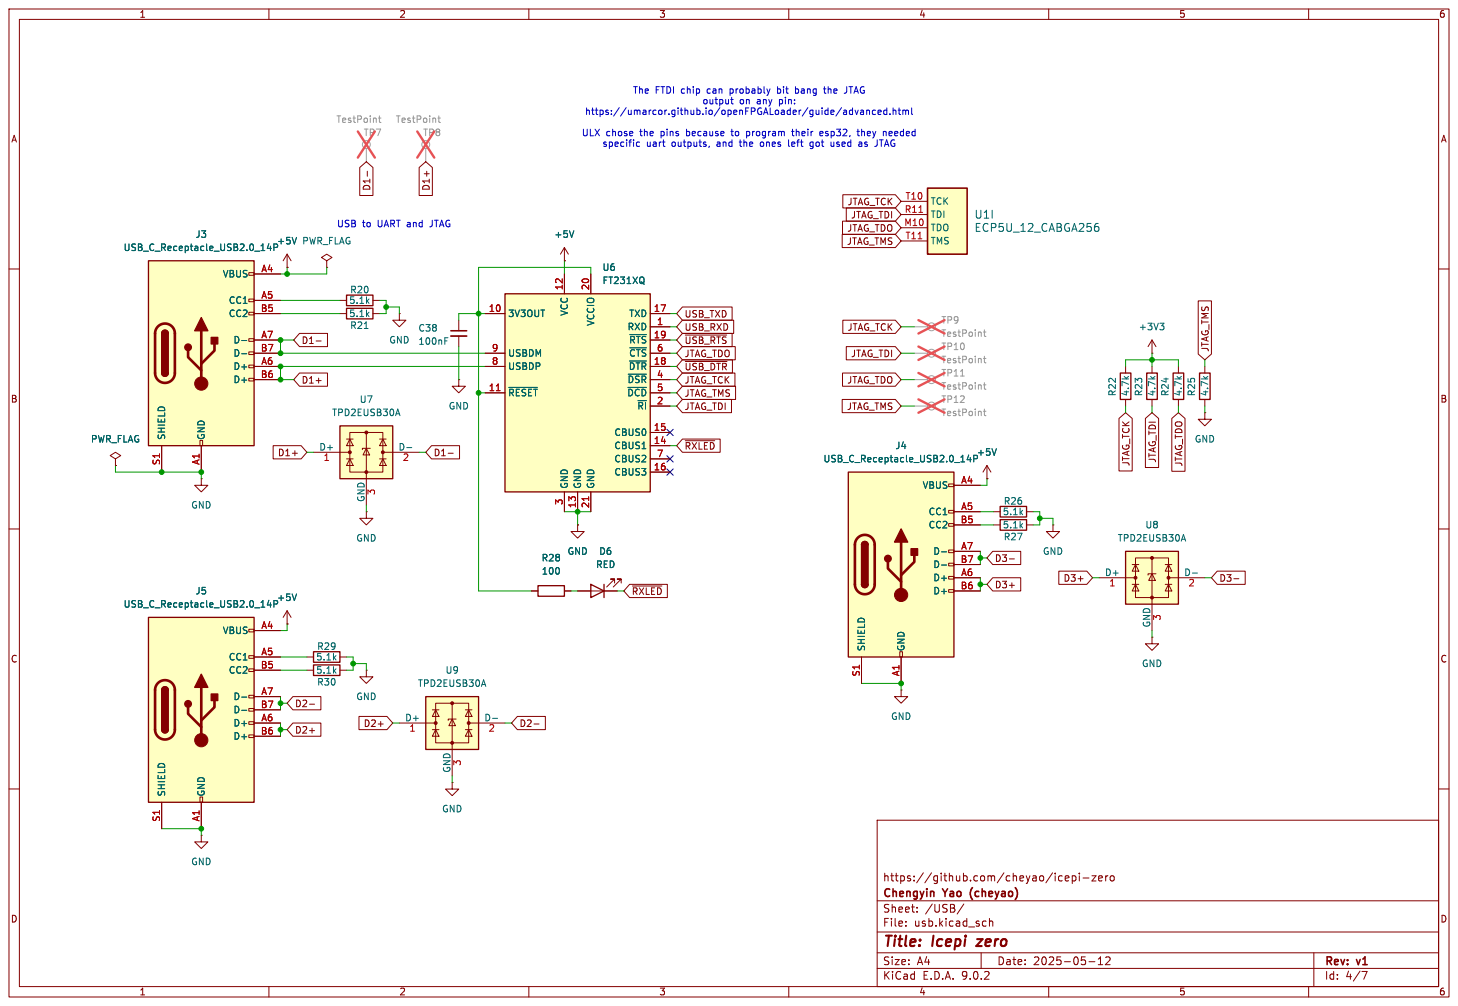
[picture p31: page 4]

https://umarcor.github.io/openFPGALoader/guide/advanced.html ULX chose the pins because to program their esp32, they needed
~{RXLED} JTAG_TCK

output on any pin:

USB to UART and JTAG

3 GND 13 VCCIO 20 GND 21 TXD 17 RXD 1 ~{RTS}19 ~{CTS}6 ~{DTR}18 ~{DSR}4 ~{DCD}5 ~{RI}2 CBUS0 15 CBUS1 14 CBUS2 7 CBUS3 16 U6 FT231XQ

3 GND 13 VCCIO 20 GND 21 TXD 17 RXD 1 ~{RTS}19 ~{CTS}6 ~{DTR}18 ~{DSR}4 ~{DCD}5 ~{RI}2 CBUS0 15 CBUS1 14 CBUS2 7 CBUS3 16 D6 RED

https://github.com/cheyao/icepi-zero
File: usb.kicad_sch Sheet: /USB/ Chengyin Yao (cheyao)

Id: 4/7 Title: Icepi zero


https://github.com/cheyao/icepi-zero GND

File: sdram.kicad_sch Sheet: /SDRAM/ Chengyin Yao (cheyao)

Id: 5/7 Title: Icepi zero


File: flash.kicad_sch Sheet: /Flash/ Chengyin Yao (cheyao)

Id: 6/7 Title: Icepi zero


https://github.com/cheyao/icepi-zero
File: ecp5.kicad_sch Sheet: /ECP5/ Chengyin Yao (cheyao)

Id: 7/7 Title: Icepi zero

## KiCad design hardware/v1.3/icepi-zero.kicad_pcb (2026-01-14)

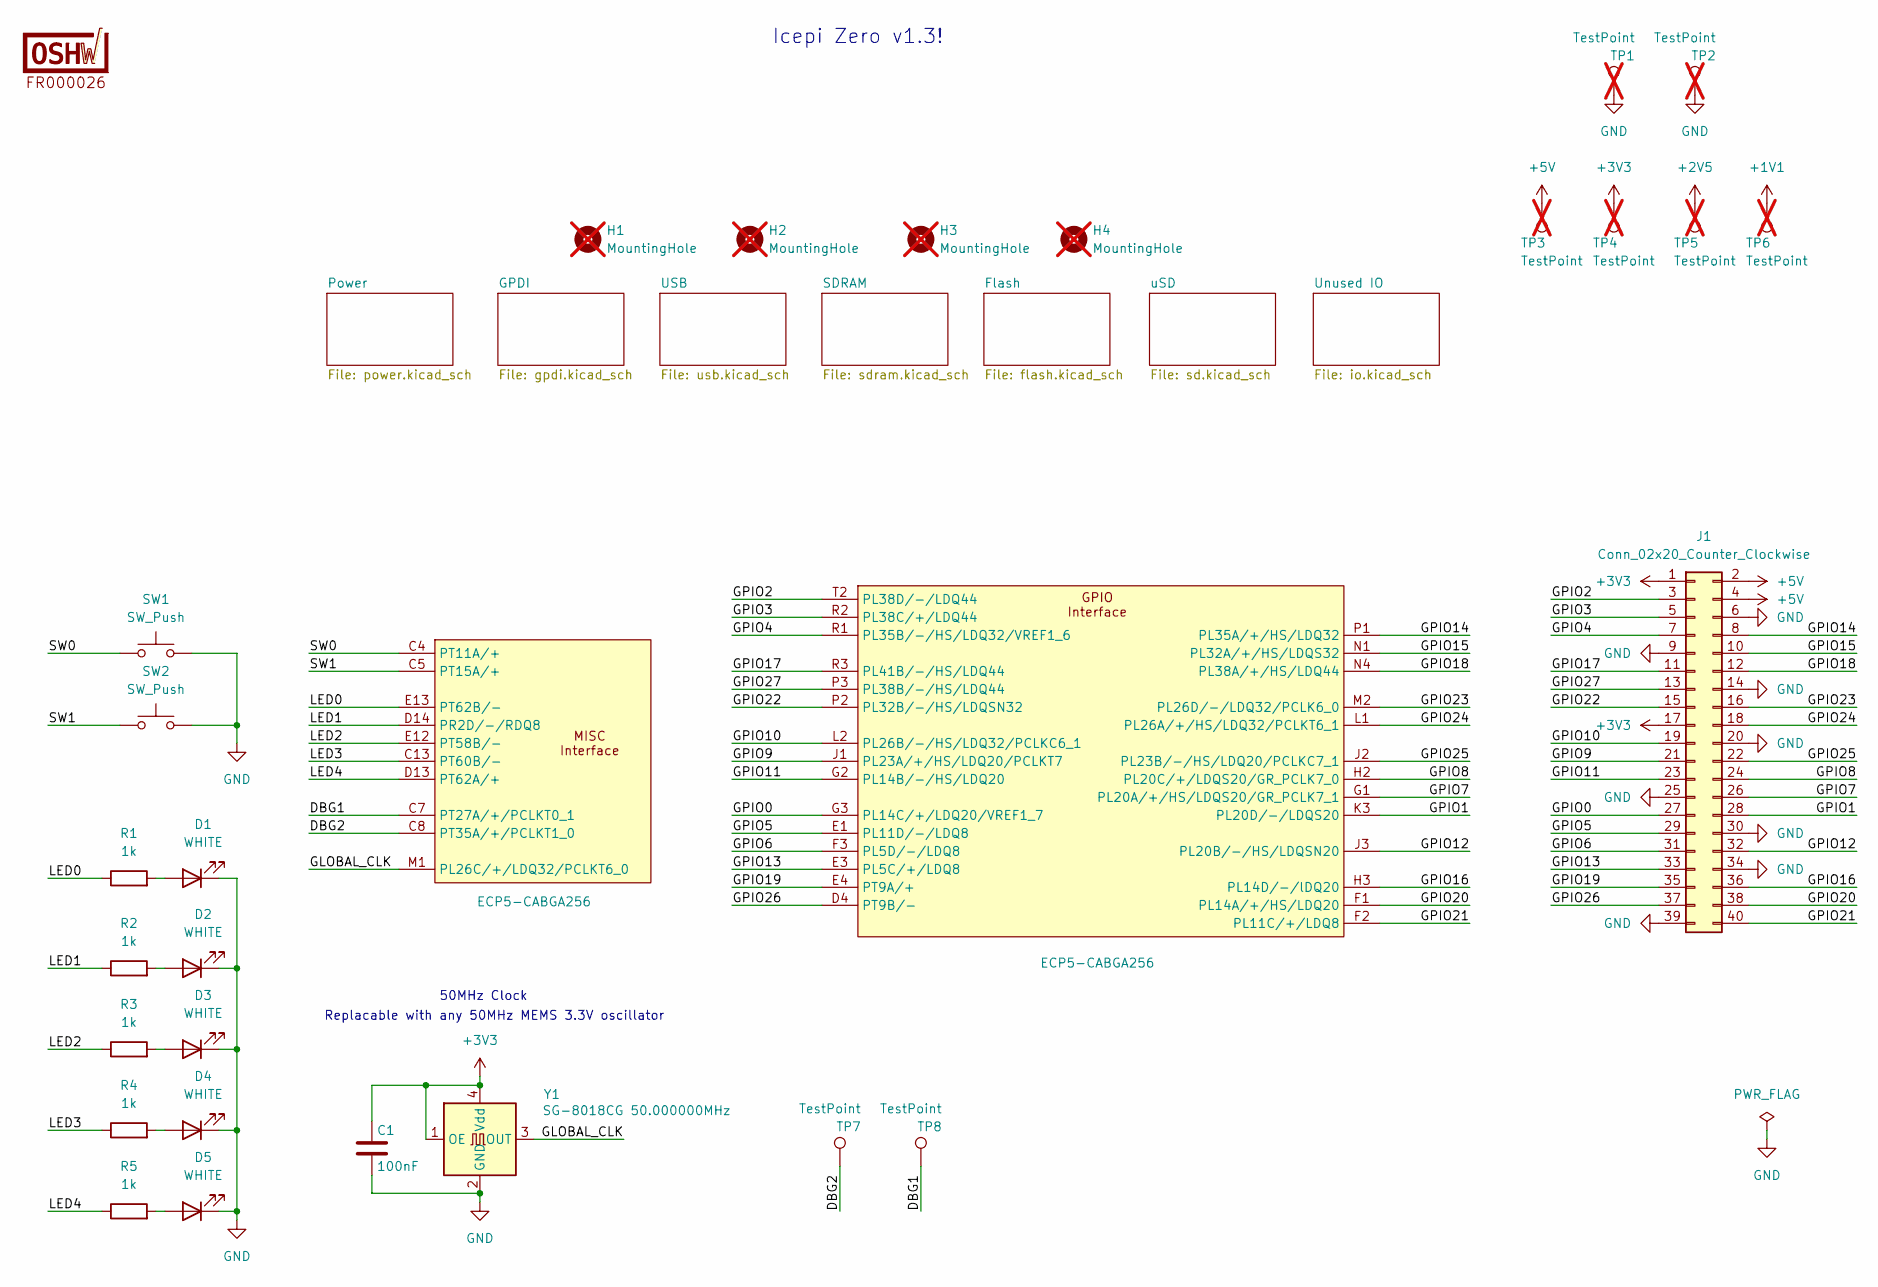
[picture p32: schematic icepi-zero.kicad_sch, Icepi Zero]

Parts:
C1: 100nF; C_0402_1005Metric; Manufactuer Part Number CL05B104KB54PNC; LCSC Part # C307331
D1, D2, D3, D4, D5: WHITE; LED_0603_1608Metric; Manufactuer Part Number KT-0603W; LCSC Part # C2290
H1, H2, H3, H4: MountingHole; MountingHole_2.7mm_M2.5; not fitted
J1: Conn_02x20_Counter_Clockwise; PinHeader_2x20_P2.54mm_Vertical
LOGO1: OSHW-Certification-Mark-Logo_6x3mm_SilkScreen
R1, R2, R3, R4, R5: 1k; R_0402_1005Metric; Manufactuer Part Number 0402WGF1001TCE; LCSC Part # C11702
SW1, SW2: SW_Push; switch_button_TS-1088-AR02016; Manufactuer Part Number TS-1088-AR02016; LCSC Part # C720477
TP1, TP2, TP3, TP4, TP5, TP6: TestPoint; TestPoint_Pad_D2.0mm_Blank; not fitted
TP7, TP8: TestPoint; TestPoint_Pad_D1.0mm_Blank
U1: ECP5-CABGA256; BGA-256_14.0x14.0mm_Layout16x16_P0.8mm_Ball0.45mm_Pad0.32mm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; Manufactuer Part Number LFE5U-25F-6BG256C; LCSC Part # C1521614
Y1: SG-8018CG 50.000000MHz; Oscillator_SMD_SiT_PQFN-4Pin_2.5x2.0mm; Manufactuer Part Number SG-8018CG 50.000000MHz TJHSA; LCSC Part # C390526

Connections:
+1V1: TP6.1; also elsewhere on the board
+2V5: TP5.1; also elsewhere on the board
+3V3: C1.1, J1.1, J1.17, TP4.1, Y1.1 (OE), Y1.4 (Vdd); also elsewhere on the board
+5V: J1.2, J1.4, TP3.1; also elsewhere on the board
/DBG1: TP8.1, U1.C7 (PT27A/+/PCLKT0_1)
/DBG2: TP7.1, U1.C8 (PT35A/+/PCLKT1_0)
/GLOBAL_CLK: U1.M1 (PL26C/+/LDQ32/PCLKT6_0), Y1.3 (OUT)
/GPIO0: J1.27, U1.G3 (PL14C/+/LDQ20/VREF1_7)
/GPIO1: J1.28, U1.K3 (PL20D/-/LDQS20)
/GPIO2: J1.3, U1.T2 (PL38D/-/LDQ44)
/GPIO3: J1.5, U1.R2 (PL38C/+/LDQ44)
/GPIO4: J1.7, U1.R1 (PL35B/-/HS/LDQ32/VREF1_6)
/GPIO5: J1.29, U1.E1 (PL11D/-/LDQ8)
/GPIO6: J1.31, U1.F3 (PL5D/-/LDQ8)
/GPIO7: J1.26, U1.G1 (PL20A/+/HS/LDQS20/GR_PCLK7_1)
/GPIO8: J1.24, U1.H2 (PL20C/+/LDQS20/GR_PCLK7_0)
/GPIO9: J1.21, U1.J1 (PL23A/+/HS/LDQ20/PCLKT7)
/GPIO10: J1.19, U1.L2 (PL26B/-/HS/LDQ32/PCLKC6_1)
/GPIO11: J1.23, U1.G2 (PL14B/-/HS/LDQ20)
/GPIO12: J1.32, U1.J3 (PL20B/-/HS/LDQSN20)
/GPIO13: J1.33, U1.E3 (PL5C/+/LDQ8)
/GPIO14: J1.8, U1.P1 (PL35A/+/HS/LDQ32)
/GPIO15: J1.10, U1.N1 (PL32A/+/HS/LDQS32)
/GPIO16: J1.36, U1.H3 (PL14D/-/lDQ20)
/GPIO17: J1.11, U1.R3 (PL41B/-/HS/LDQ44)
/GPIO18: J1.12, U1.N4 (PL38A/+/HS/LDQ44)
/GPIO19: J1.35, U1.E4 (PT9A/+)
/GPIO20: J1.38, U1.F1 (PL14A/+/HS/LDQ20)
/GPIO21: J1.40, U1.F2 (PL11C/+/LDQ8)
/GPIO22: J1.15, U1.P2 (PL32B/-/HS/LDQSN32)
/GPIO23: J1.16, U1.M2 (PL26D/-/LDQ32/PCLK6_0)
/GPIO24: J1.18, U1.L1 (PL26A/+/HS/LDQ32/PCLKT6_1)
/GPIO25: J1.22, U1.J2 (PL23B/-/HS/LDQ20/PCLKC7_1)
/GPIO26: J1.37, U1.D4 (PT9B/-)
/GPIO27: J1.13, U1.P3 (PL38B/-/HS/LDQ44)
/LED0: R1.1, U1.E13 (PT62B/-)
/LED1: R2.1, U1.D14 (PR2D/-/RDQ8)
/LED2: R3.1, U1.E12 (PT58B/-)
/LED3: R4.1, U1.C13 (PT60B/-)
/LED4: R5.1, U1.D13 (PT62A/+)
/SW0: SW1.1, U1.C4 (PT11A/+)
/SW1: SW2.1, U1.C5 (PT15A/+)
GND: C1.2, D1.1 (K), D2.1 (K), D3.1 (K), D4.1 (K), D5.1 (K), J1.6, J1.9, J1.14, J1.20, J1.25, J1.30, J1.34, J1.39, SW1.2, SW2.2, TP1.1, TP2.1, Y1.2 (GND); also elsewhere on the board
unnamed: D1.2 (A), R1.2
unnamed: D2.2 (A), R2.2
unnamed: D3.2 (A), R3.2
unnamed: D4.2 (A), R4.2
unnamed: D5.2 (A), R5.2

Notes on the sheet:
Icepi Zero v1.3!
Replacable with any 50MHz MEMS 3.3V oscillator
50MHz Clock

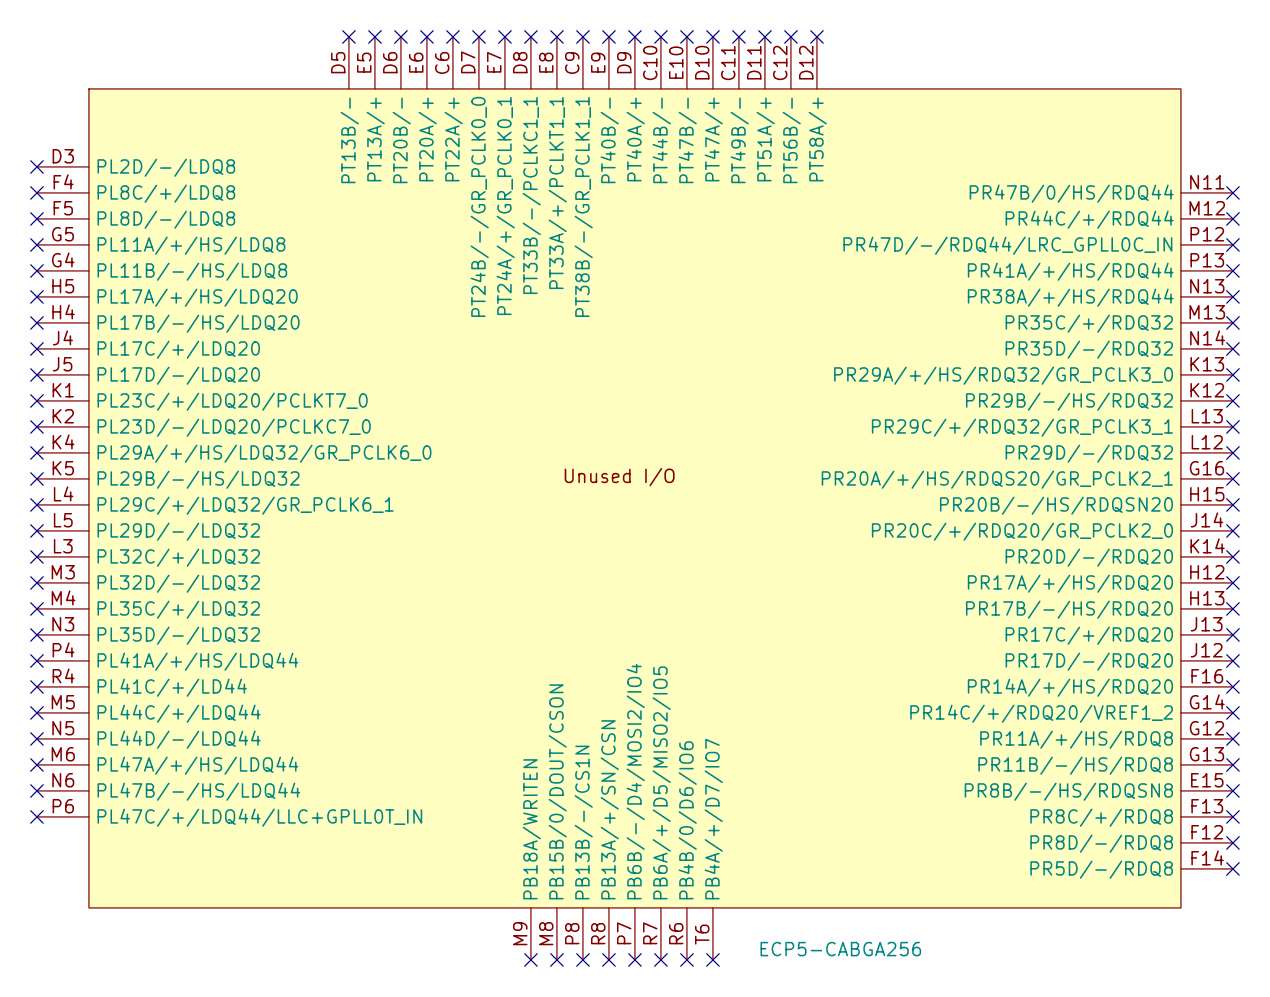
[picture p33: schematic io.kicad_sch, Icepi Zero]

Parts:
U1: ECP5-CABGA256; BGA-256_14.0x14.0mm_Layout16x16_P0.8mm_Ball0.45mm_Pad0.32mm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; Manufactuer Part Number LFE5U-25F-6BG256C; LCSC Part # C1521614

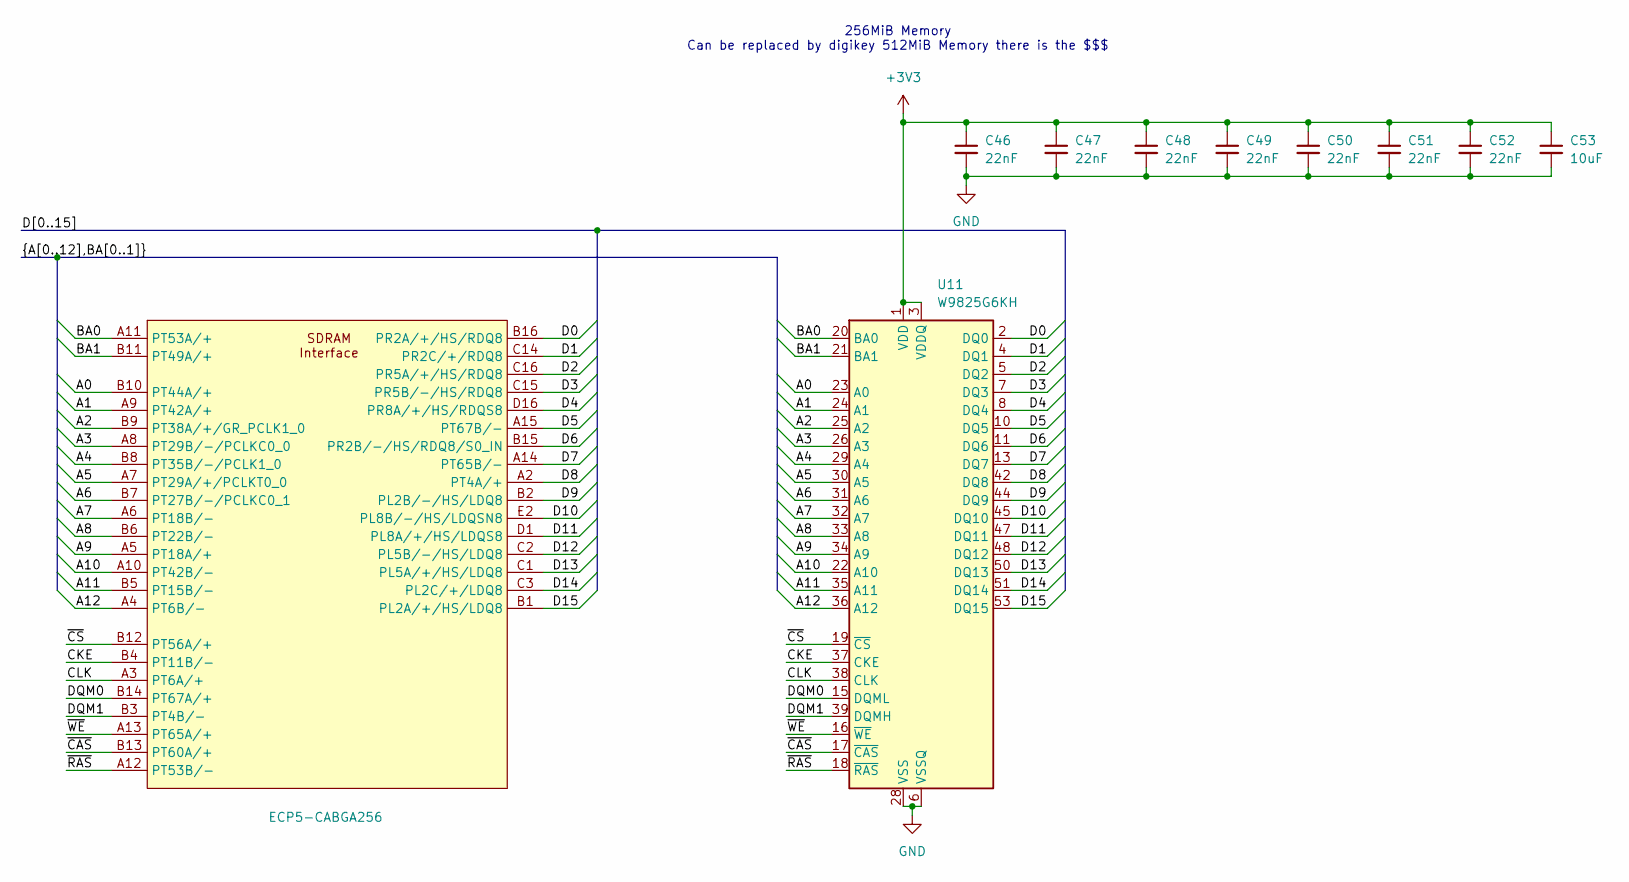
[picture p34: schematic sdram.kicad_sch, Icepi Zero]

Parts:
C46, C47, C48, C49, C50, C51, C52: 22nF; C_0603_1608Metric; Manufactuer Part Number 0603B223K500NT; LCSC Part # C77571
C53: 10uF; C_0603_1608Metric; Manufactuer Part Number CL10A106KP8NNNC; LCSC Part # C19702
U1: ECP5-CABGA256; BGA-256_14.0x14.0mm_Layout16x16_P0.8mm_Ball0.45mm_Pad0.32mm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; Manufactuer Part Number LFE5U-25F-6BG256C; LCSC Part # C1521614
U11: W9825G6KH; TSOP-II-54_22.2x10.16mm_P0.8mm; Manufactuer Part Number W9825G6KH-6; LCSC Part # C62246

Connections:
+3V3: C46.1, C47.1, C48.1, C49.1, C50.1, C51.1, C52.1, C53.1, U11.1 (VDD), U11.3 (VDDQ), U11.9 (VDDQ), U11.14 (VDD), U11.27 (VDD), U11.43 (VDDQ), U11.49 (VDDQ); also elsewhere on the board
/SDRAM/A0: U1.B10 (PT44A/+), U11.23 (A0)
/SDRAM/A1: U1.A9 (PT42A/+), U11.24 (A1)
/SDRAM/A2: U1.B9 (PT38A/+/GR_PCLK1_0), U11.25 (A2)
/SDRAM/A3: U1.A8 (PT29B/-/PCLKC0_0), U11.26 (A3)
/SDRAM/A4: U1.B8 (PT35B/-/PCLK1_0), U11.29 (A4)
/SDRAM/A5: U1.A7 (PT29A/+/PCLKT0_0), U11.30 (A5)
/SDRAM/A6: U1.B7 (PT27B/-/PCLKC0_1), U11.31 (A6)
/SDRAM/A7: U1.A6 (PT18B/-), U11.32 (A7)
/SDRAM/A8: U1.B6 (PT22B/-), U11.33 (A8)
/SDRAM/A9: U1.A5 (PT18A/+), U11.34 (A9)
/SDRAM/A10: U1.A10 (PT42B/-), U11.22 (A10)
/SDRAM/A11: U1.B5 (PT15B/-), U11.35 (A11)
/SDRAM/A12: U1.A4 (PT6B/-), U11.36 (A12)
/SDRAM/BA0: U1.A11 (PT53A/+), U11.20 (BA0)
/SDRAM/BA1: U1.B11 (PT49A/+), U11.21 (BA1)
/SDRAM/CKE: U1.B4 (PT11B/-), U11.37 (CKE)
/SDRAM/CLK: U1.A3 (PT6A/+), U11.38 (CLK)
/SDRAM/D0: U1.B16 (PR2A/+/HS/RDQ8), U11.2 (DQ0)
/SDRAM/D1: U1.C14 (PR2C/+/RDQ8), U11.4 (DQ1)
/SDRAM/D2: U1.C16 (PR5A/+/HS/RDQ8), U11.5 (DQ2)
/SDRAM/D3: U1.C15 (PR5B/-/HS/RDQ8), U11.7 (DQ3)
/SDRAM/D4: U1.D16 (PR8A/+/HS/RDQS8), U11.8 (DQ4)
/SDRAM/D5: U1.A15 (PT67B/-), U11.10 (DQ5)
/SDRAM/D6: U1.B15 (PR2B/-/HS/RDQ8/S0_IN), U11.11 (DQ6)
/SDRAM/D7: U1.A14 (PT65B/-), U11.13 (DQ7)
/SDRAM/D8: U1.A2 (PT4A/+), U11.42 (DQ8)
/SDRAM/D9: U1.B2 (PL2B/-/HS/LDQ8), U11.44 (DQ9)
/SDRAM/D10: U1.E2 (PL8B/-/HS/LDQSN8), U11.45 (DQ10)
/SDRAM/D11: U1.D1 (PL8A/+/HS/LDQS8), U11.47 (DQ11)
/SDRAM/D12: U1.C2 (PL5B/-/HS/LDQ8), U11.48 (DQ12)
/SDRAM/D13: U1.C1 (PL5A/+/HS/LDQ8), U11.50 (DQ13)
/SDRAM/D14: U1.C3 (PL2C/+/LDQ8), U11.51 (DQ14)
/SDRAM/D15: U1.B1 (PL2A/+/HS/LDQ8), U11.53 (DQ15)
/SDRAM/DQM0: U1.B14 (PT67A/+), U11.15 (DQML)
/SDRAM/DQM1: U1.B3 (PT4B/-), U11.39 (DQMH)
/SDRAM/~CAS: U1.B13 (PT60A/+), U11.17 (~CAS)
/SDRAM/~CS: U1.B12 (PT56A/+), U11.19 (~CS)
/SDRAM/~RAS: U1.A12 (PT53B/-), U11.18 (~RAS)
/SDRAM/~WE: U1.A13 (PT65A/+), U11.16 (~WE)
GND: C46.2, C47.2, C48.2, C49.2, C50.2, C51.2, C52.2, C53.2, U11.6 (VSSQ), U11.12 (VSSQ), U11.28 (VSS), U11.41 (VSS), U11.46 (VSSQ), U11.52 (VSSQ), U11.54 (VSS); also elsewhere on the board

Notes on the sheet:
256MiB Memory Can be replaced by digikey 512MiB Memory there is the $$$

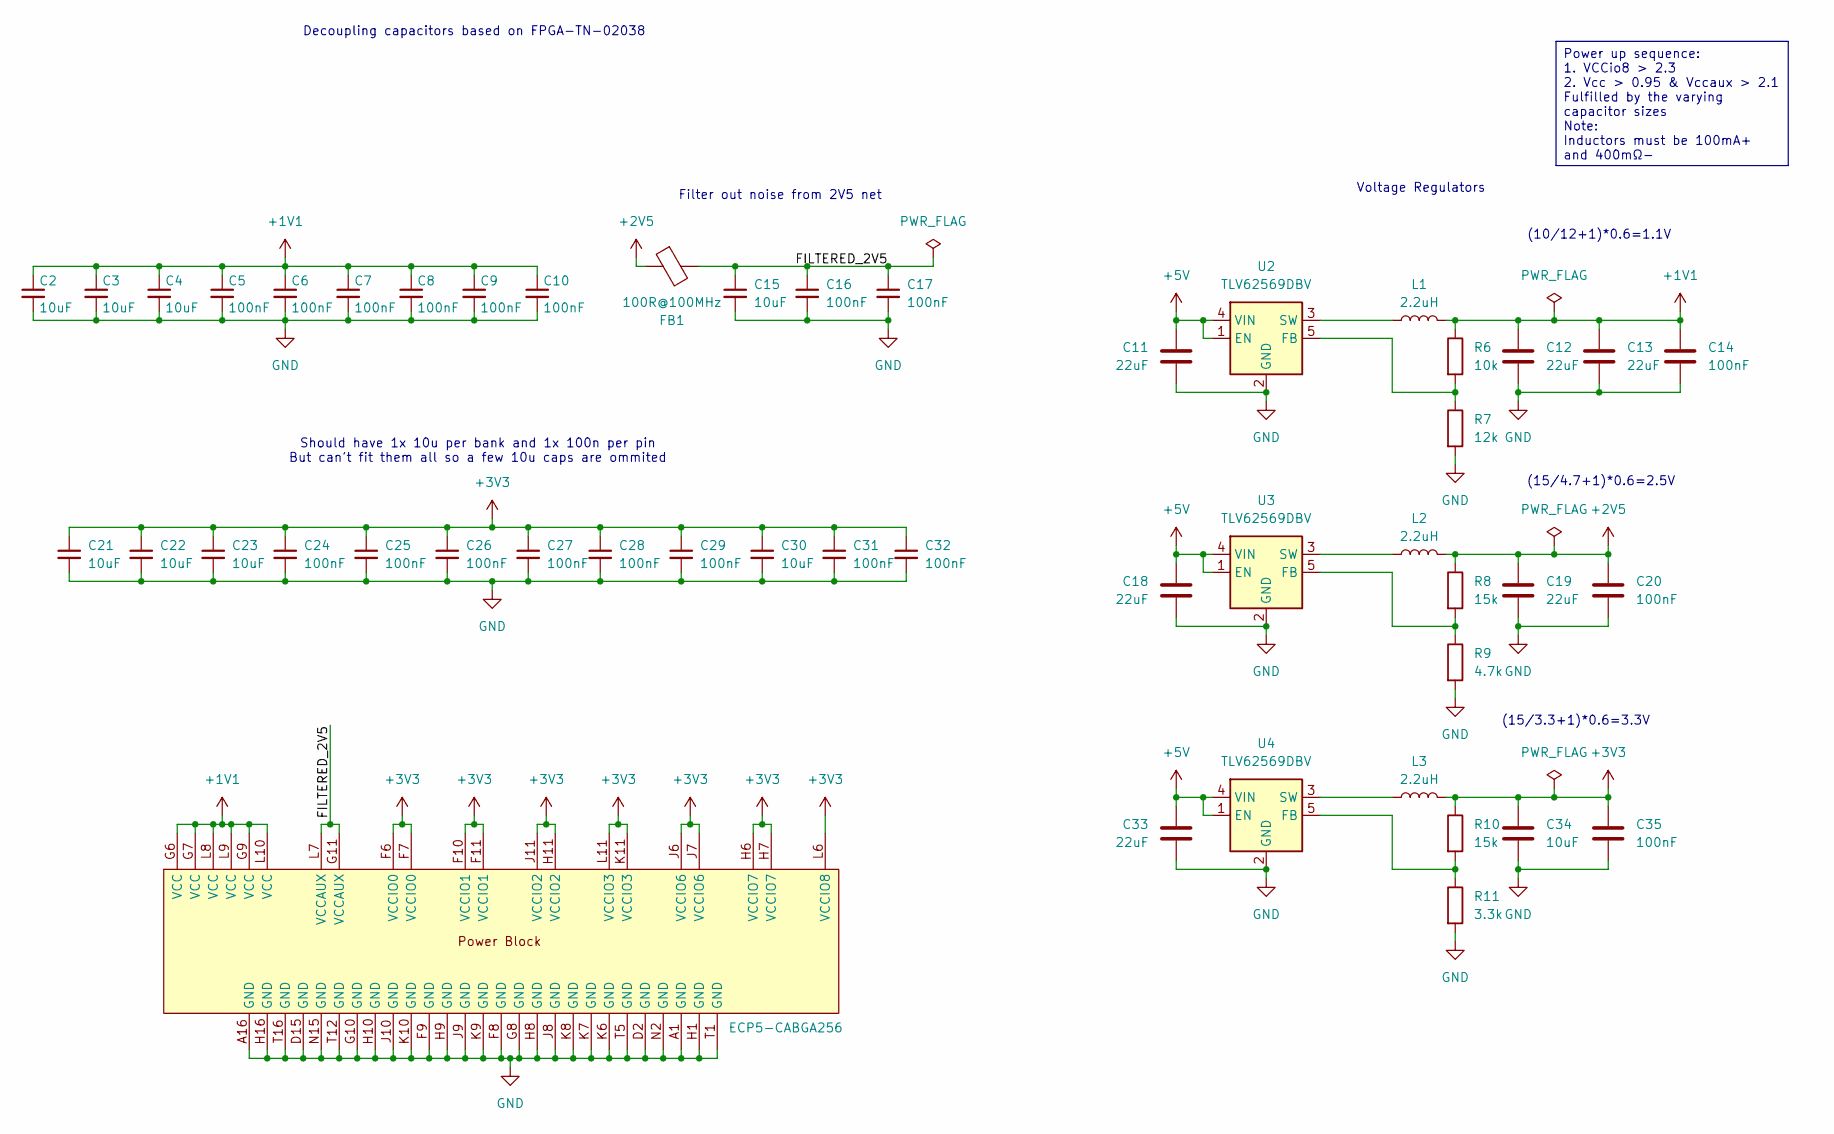
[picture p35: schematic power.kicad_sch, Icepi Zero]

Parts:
C2, C3, C4, C15, C21, C22, C23, C30, C34: 10uF; C_0603_1608Metric; Manufactuer Part Number CL10A106KP8NNNC; LCSC Part # C19702
C5, C6, C7, C8, C9, C10, C14, C16, C17, C20, C24, C25, C26, C27, C28, C29, C31, C32, C35: 100nF; C_0402_1005Metric; Manufactuer Part Number CL05B104KB54PNC; LCSC Part # C307331
C11, C12, C13, C18, C19, C33: 22uF; C_0603_1608Metric; Manufactuer Part Number CL10A226MQ8NRNC; LCSC Part # C59461
FB1: 100R@100MHz; L_0805_2012Metric; Manufactuer Part Number CBG201209U101T; LCSC Part # C74480
L1, L2, L3: 2.2uH; L_0805_2012Metric; Manufactuer Part Number TDK MLP2012S2R2MT0S1; LCSC Part # C107322
R6: 10k; R_0402_1005Metric; Manufactuer Part Number 0402WGF1002TCE; LCSC Part # C25744
R7: 12k; R_0402_1005Metric; Manufactuer Part Number 0402WGF1202TCE; LCSC Part # C25752
R8, R10: 15k; R_0402_1005Metric; Manufactuer Part Number 0402WGF1502TCE; LCSC Part # C25756
R9: 4.7k; R_0402_1005Metric; Manufactuer Part Number 0402WGF4701TCE; LCSC Part # C25900
R11: 3.3k; R_0402_1005Metric; Manufactuer Part Number 0402WGF3301TCE; LCSC Part # C25890
U1: ECP5-CABGA256; BGA-256_14.0x14.0mm_Layout16x16_P0.8mm_Ball0.45mm_Pad0.32mm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; Manufactuer Part Number LFE5U-25F-6BG256C; LCSC Part # C1521614
U2, U3, U4: TLV62569DBV; SOT-23-5; Manufactuer Part Number TLV62569DBVR; LCSC Part # C141836

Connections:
+1V1: C2.1, C3.1, C4.1, C5.1, C6.1, C7.1, C8.1, C9.1, C10.1, C12.1, C13.1, C14.1, L1.2, R6.1, U1.G6 (VCC), U1.G7 (VCC), U1.G9 (VCC), U1.L8 (VCC), U1.L9 (VCC), U1.L10 (VCC); also elsewhere on the board
+2V5: C19.1, C20.1, FB1.1, L2.2, R8.1; also elsewhere on the board
+3V3: C21.1, C22.1, C23.1, C24.1, C25.1, C26.1, C27.1, C28.1, C29.1, C30.1, C31.1, C32.1, C34.1, C35.1, L3.2, R10.1, U1.F6 (VCCIO0), U1.F7 (VCCIO0), U1.F10 (VCCIO1), U1.F11 (VCCIO1), U1.H6 (VCCIO7), U1.H7 (VCCIO7), U1.H11 (VCCIO2), U1.J6 (VCCIO6), U1.J7 (VCCIO6), U1.J11 (VCCIO2), U1.K11 (VCCIO3), U1.L6 (VCCIO8), U1.L11 (VCCIO3); also elsewhere on the board
+5V: C11.1, C18.1, C33.1, U2.1 (EN), U2.4 (VIN), U3.1 (EN), U3.4 (VIN), U4.1 (EN), U4.4 (VIN); also elsewhere on the board
/Power/FILTERED_2V5: C15.1, C16.1, C17.1, FB1.2, U1.G11 (VCCAUX), U1.L7 (VCCAUX)
GND: C2.2, C3.2, C4.2, C5.2, C6.2, C7.2, C8.2, C9.2, C10.2, C11.2, C12.2, C13.2, C14.2, C15.2, C16.2, C17.2, C18.2, C19.2, C20.2, C21.2, C22.2, C23.2, C24.2, C25.2, C26.2, C27.2, C28.2, C29.2, C30.2, C31.2, C32.2, C33.2, C34.2, C35.2, R7.2, R9.2, R11.2, U1.A1 (GND), U1.A16 (GND), U1.D2 (GND), U1.D15 (GND), U1.F8 (GND), U1.F9 (GND), U1.G8 (GND), U1.G10 (GND), U1.H1 (GND), U1.H8 (GND), U1.H9 (GND), U1.H10 (GND), U1.H16 (GND), U1.J8 (GND), U1.J9 (GND), U1.J10 (GND), U1.K6 (GND), U1.K7 (GND), U1.K8 (GND), U1.K9 (GND), U1.K10 (GND), U1.N2 (GND), U1.N15 (GND), U1.T1 (GND), U1.T5 (GND), U1.T12 (GND), U1.T16 (GND), U2.2 (GND), U3.2 (GND), U4.2 (GND); also elsewhere on the board
unnamed: R6.2, R7.1, U2.5 (FB)
unnamed: L1.1, U2.3 (SW)
unnamed: R8.2, R9.1, U3.5 (FB)
unnamed: L2.1, U3.3 (SW)
unnamed: R10.2, R11.1, U4.5 (FB)
unnamed: L3.1, U4.3 (SW)

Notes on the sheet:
Decoupling capacitors based on FPGA-TN-02038
(15/4.7+1)*0.6=2.5V
(10/12+1)*0.6=1.1V
Filter out noise from 2V5 net
(15/3.3+1)*0.6=3.3V
Should have 1x 10u per bank and 1x 100n per pin But can't fit them all so a few 10u caps are ommited
Voltage Regulators
Power up sequence: 1. VCCio8 > 2.3 2. Vcc > 0.95 & Vccaux > 2.1 Fulfilled by the varying capacitor sizes Note: Inductors must be 100mA+ and 400mΩ-

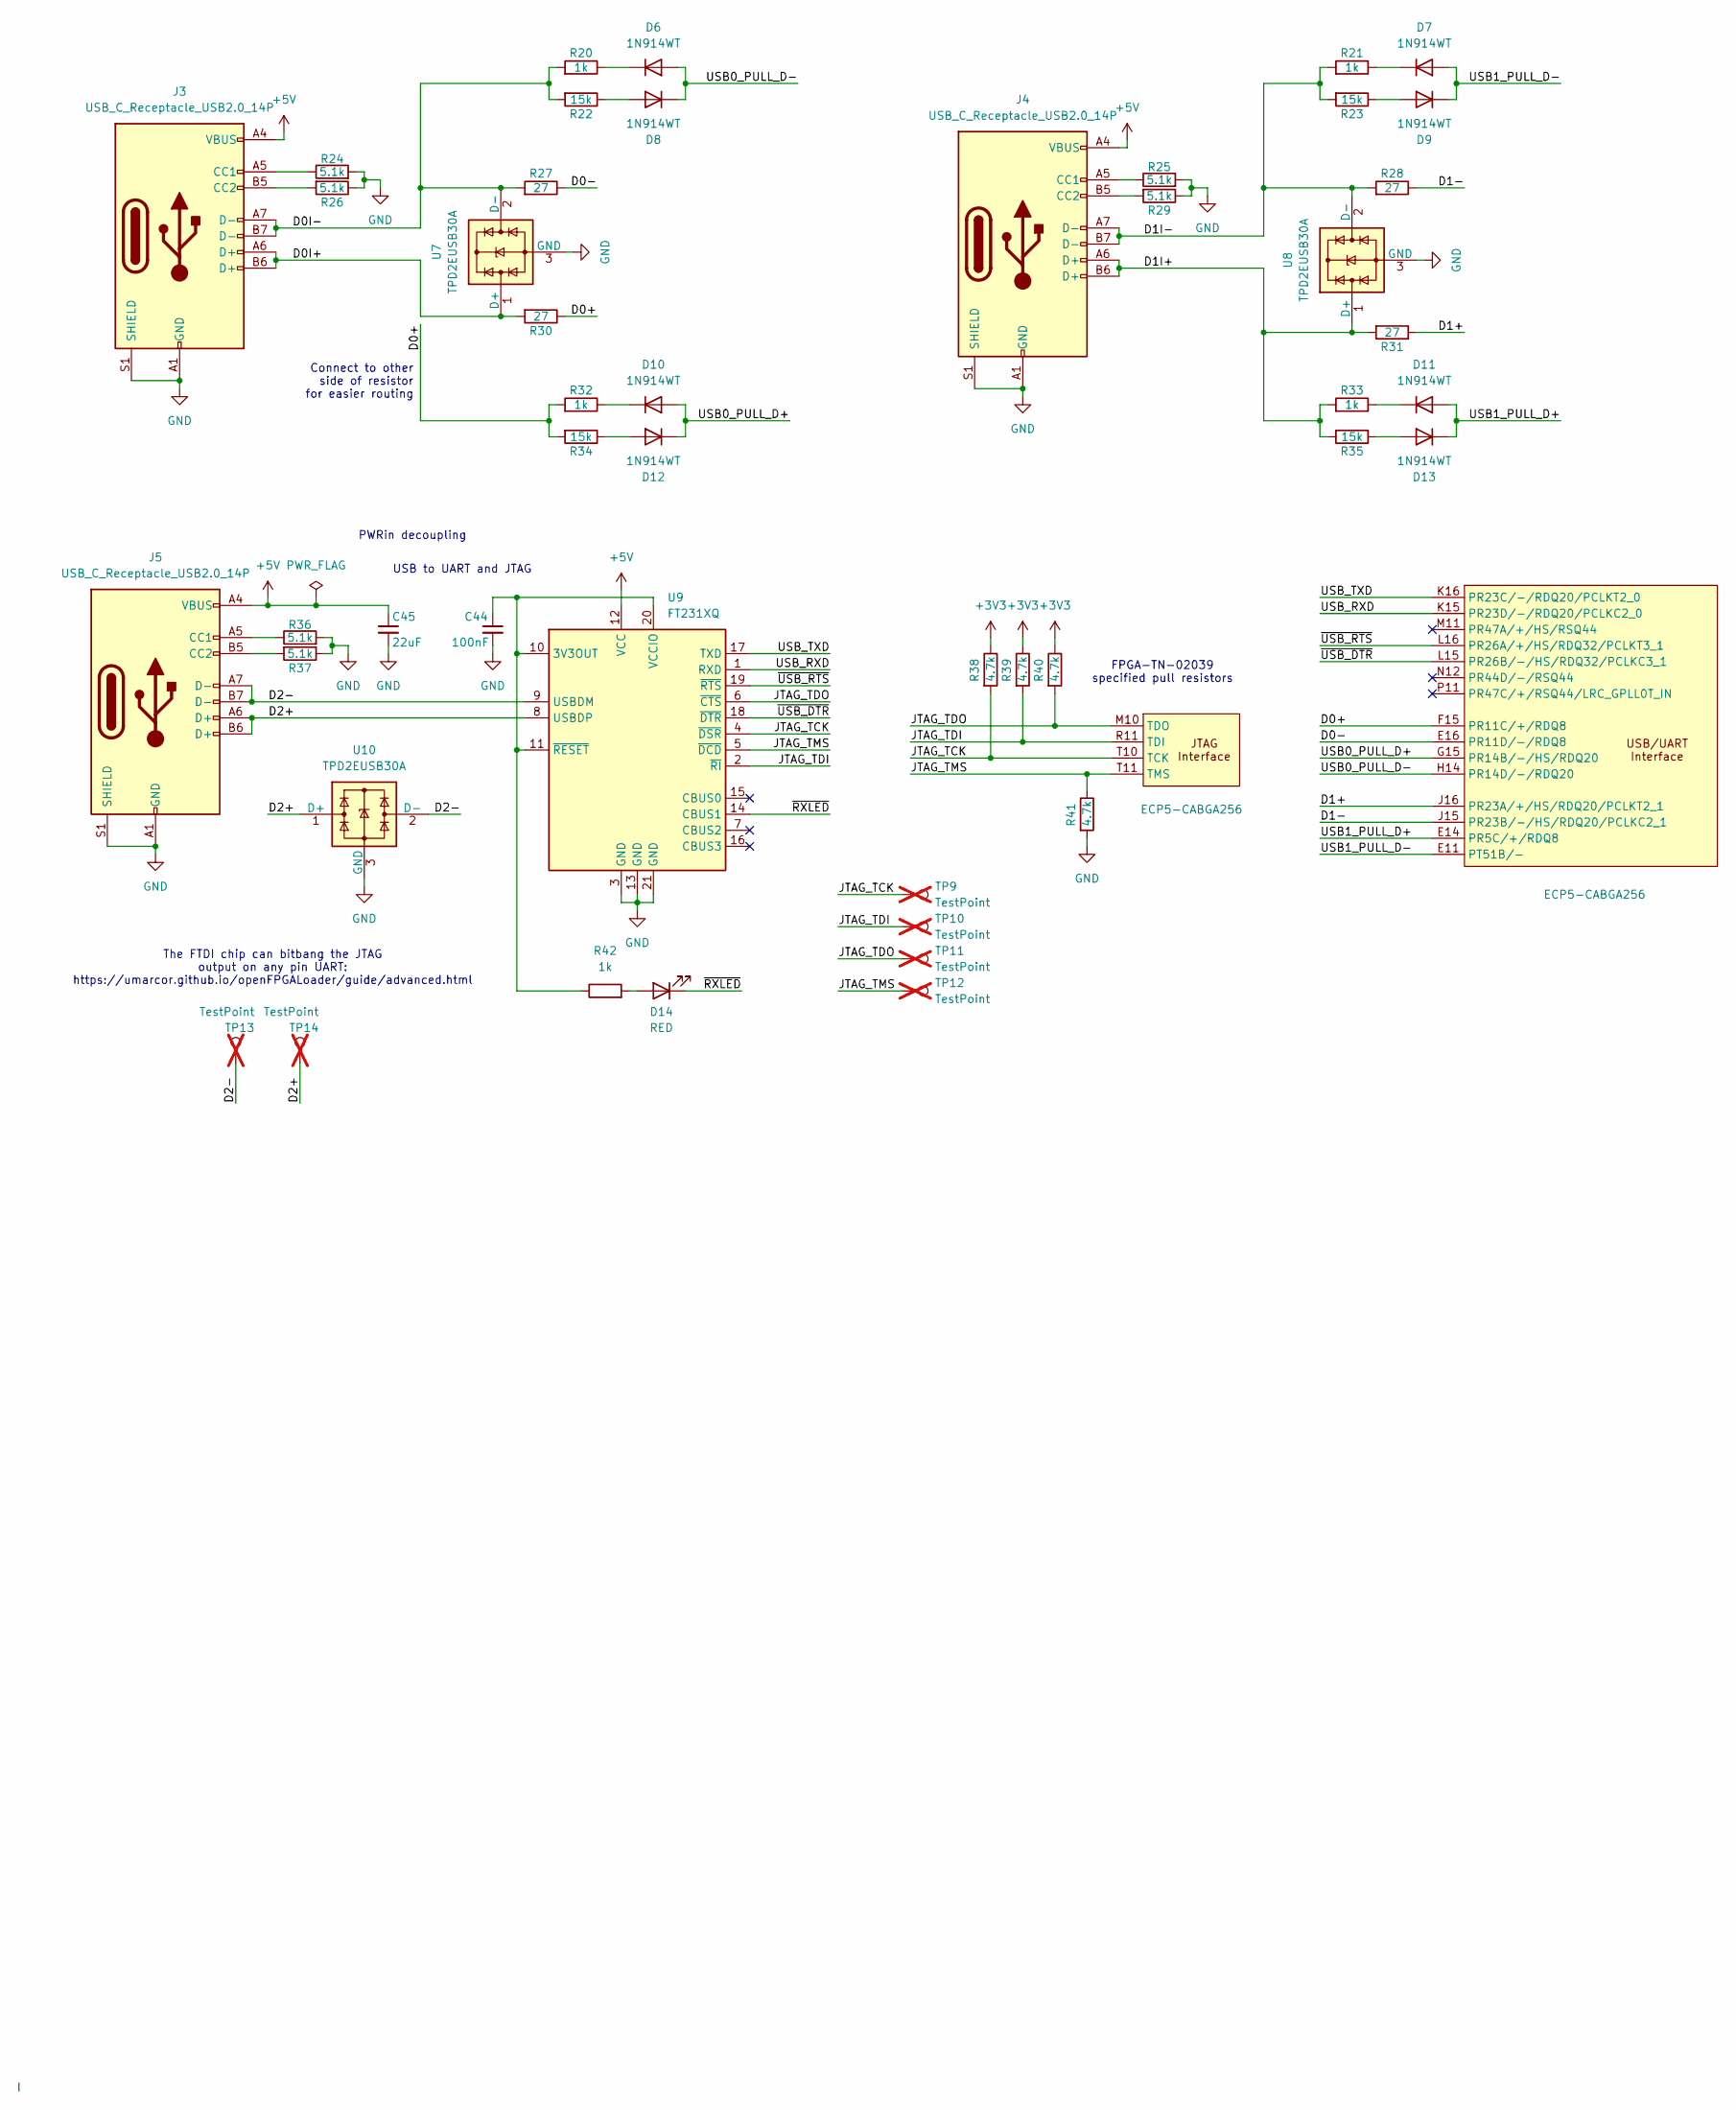
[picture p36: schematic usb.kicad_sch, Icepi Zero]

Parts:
C44: 100nF; C_0402_1005Metric; Manufactuer Part Number CL05B104KB54PNC; LCSC Part # C307331
C45: 22uF; C_0603_1608Metric; Manufactuer Part Number CL10A226MQ8NRNC; LCSC Part # C59461
D6, D7, D8, D9, D10, D11, D12, D13: 1N914WT; D_SOD-523; Manufactuer Part Number 1N914WT; LCSC Part # C2836064
D14: RED; LED_0603_1608Metric; Manufactuer Part Number KT-0603R; LCSC Part # C2286
J3, J4, J5: USB_C_Receptacle_USB2.0_14P; USB_C_Receptacle_GCT_USB4105-xx-A_16P_TopMnt_Horizontal; Manufactuer Part Number TYPE-C 16PIN 2MD(073); LCSC Part # C2765186
R20, R21, R32, R33, R42: 1k; R_0402_1005Metric; Manufactuer Part Number 0402WGF1001TCE; LCSC Part # C11702
R22, R23, R34, R35: 15k; R_0402_1005Metric; Manufactuer Part Number 0402WGF1502TCE; LCSC Part # C25756
R24, R25, R26, R29, R36, R37: 5.1k; R_0402_1005Metric; Manufactuer Part Number 0402WGF5101TCE; LCSC Part # C25905
R27, R28, R30, R31: 27; R_0201_0603Metric; Manufactuer Part Number 0201WMF270JTEE; LCSC Part # C473051
R38, R39, R40, R41: 4.7k; R_0402_1005Metric; Manufactuer Part Number 0402WGF4701TCE; LCSC Part # C25900
TP9, TP10, TP11, TP12: TestPoint; TestPoint_Pad_D1.0mm_Blank; not fitted
TP13, TP14: TestPoint; TestPoint_Pad_D2.0mm_Blank; not fitted
U1: ECP5-CABGA256; BGA-256_14.0x14.0mm_Layout16x16_P0.8mm_Ball0.45mm_Pad0.32mm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; Manufactuer Part Number LFE5U-25F-6BG256C; LCSC Part # C1521614
U7, U8, U10: TPD2EUSB30A; Texas_DRT-3; Manufactuer Part Number TPD2EUSB30ADRTR; LCSC Part # C3011197
U9: FT231XQ; QFN-20-1EP_4x4mm_P0.5mm_EP2.5x2.5mm; Manufactuer Part Number FT231XQ-R; LCSC Part # C132159

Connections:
+3V3: R38.1, R39.1, R40.1; also elsewhere on the board
+5V: C45.1, J3.A4 (VBUS), J3.A9 (VBUS), J3.B4 (VBUS), J3.B9 (VBUS), J4.A4 (VBUS), J4.A9 (VBUS), J4.B4 (VBUS), J4.B9 (VBUS), J5.A4 (VBUS), J5.A9 (VBUS), J5.B4 (VBUS), J5.B9 (VBUS), U9.12 (VCC); also elsewhere on the board
/USB/D0+: R30.1, R32.2, R34.2, U1.F15 (PR11C/+/RDQ8)
/USB/D0-: R27.1, U1.E16 (PR11D/-/RDQ8)
/USB/D0I+: J3.A6 (D+), J3.B6 (D+), R30.2, U7.1 (D+)
/USB/D0I-: J3.A7 (D-), J3.B7 (D-), R20.2, R22.2, R27.2, U7.2 (D-)
/USB/D1+: R31.1, U1.J16 (PR23A/+/HS/RDQ20/PCLKT2_1)
/USB/D1-: R28.1, U1.J15 (PR23B/-/HS/RDQ20/PCLKC2_1)
/USB/D1I+: J4.A6 (D+), J4.B6 (D+), R31.2, R33.2, R35.2, U8.1 (D+)
/USB/D1I-: J4.A7 (D-), J4.B7 (D-), R21.2, R23.2, R28.2, U8.2 (D-)
/USB/D2+: J5.A6 (D+), J5.B6 (D+), TP14.1, U9.8 (USBDP), U10.1 (D+)
/USB/D2-: J5.A7 (D-), J5.B7 (D-), TP13.1, U9.9 (USBDM), U10.2 (D-)
/USB/JTAG_TCK: R38.2, TP9.1, U1.T10 (TCK), U9.4 (~DSR)
/USB/JTAG_TDI: R39.2, TP10.1, U1.R11 (TDI), U9.2 (~RI)
/USB/JTAG_TDO: R40.2, TP11.1, U1.M10 (TDO), U9.6 (~CTS)
/USB/JTAG_TMS: R41.1, TP12.1, U1.T11 (TMS), U9.5 (~DCD)
/USB/USB0_PULL_D+: D10.2 (A), D12.1 (K), U1.G15 (PR14B/-/HS/RDQ20)
/USB/USB0_PULL_D-: D6.2 (A), D8.1 (K), U1.H14 (PR14D/-/RDQ20)
/USB/USB1_PULL_D+: D11.2 (A), D13.1 (K), U1.E14 (PR5C/+/RDQ8)
/USB/USB1_PULL_D-: D7.2 (A), D9.1 (K), U1.E11 (PT51B/-)
/USB/USB_RXD: U1.K15 (PR23D/-/RDQ20/PCLKC2_0), U9.1 (RXD)
/USB/USB_TXD: U1.K16 (PR23C/-/RDQ20/PCLKT2_0), U9.17 (TXD)
/USB/~RXLED: D14.1 (K), U9.14 (CBUS1)
/USB/~USB_DTR: U1.L15 (PR26B/-/HS/RDQ32/PCLKC3_1), U9.18 (~DTR)
/USB/~USB_RTS: U1.L16 (PR26A/+/HS/RDQ32/PCLKT3_1), U9.19 (~RTS)
GND: C44.2, C45.2, J3.A1 (GND), J3.A12 (GND), J3.B1 (GND), J3.B12 (GND), J3.S1 (SHIELD), J4.A1 (GND), J4.A12 (GND), J4.B1 (GND), J4.B12 (GND), J4.S1 (SHIELD), J5.A1 (GND), J5.A12 (GND), J5.B1 (GND), J5.B12 (GND), J5.S1 (SHIELD), R24.2, R25.2, R26.1, R29.1, R36.2, R37.1, R41.2, U7.3 (GND), U8.3 (GND), U9.3 (GND), U9.13 (GND), U9.21 (GND), U10.3 (GND); also elsewhere on the board
unnamed: D6.1 (K), R20.1
unnamed: D7.1 (K), R21.1
unnamed: D8.2 (A), R22.1
unnamed: D9.2 (A), R23.1
unnamed: D10.1 (K), R32.1
unnamed: D11.1 (K), R33.1
unnamed: D12.2 (A), R34.1
unnamed: D13.2 (A), R35.1
unnamed: D14.2 (A), R42.2
unnamed: J3.A5 (CC1), R24.1
unnamed: J3.B5 (CC2), R26.2
unnamed: J4.A5 (CC1), R25.1
unnamed: J4.B5 (CC2), R29.2
unnamed: J5.A5 (CC1), R36.1
unnamed: J5.B5 (CC2), R37.2
unnamed: C44.1, R42.1, U9.10 (3V3OUT), U9.11 (~RESET), U9.20 (VCCIO)

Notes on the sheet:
PWRin decoupling
FPGA-TN-02039 specified pull resistors
USB to UART and JTAG
The FTDI chip can bitbang the JTAG output on any pin UART: https://umarcor.github.io/openFPGALoader/guide/advanced.html
Connect to other side of resistor for easier routing

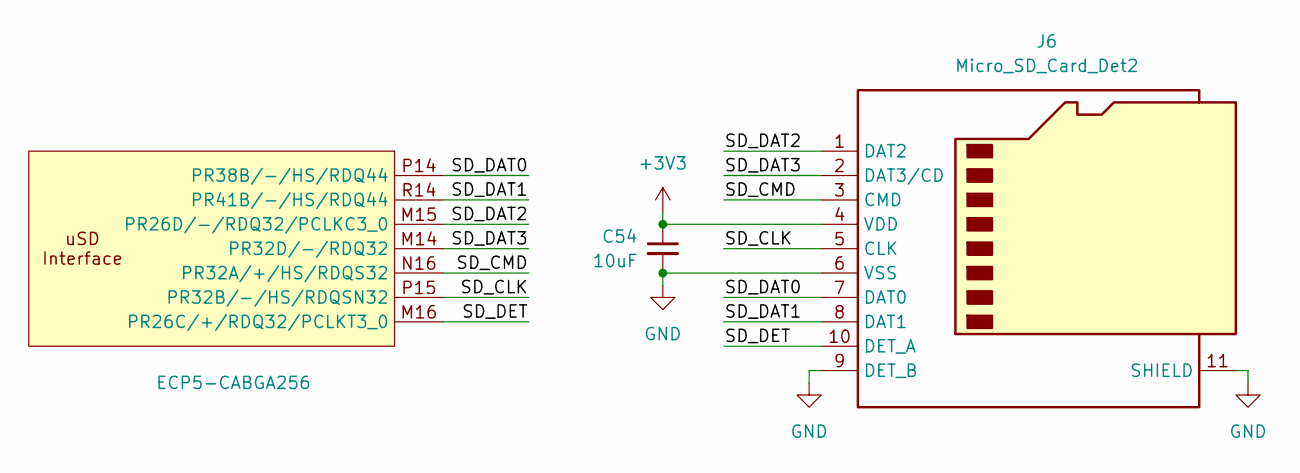
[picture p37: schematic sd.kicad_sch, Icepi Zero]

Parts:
C54: 10uF; C_0603_1608Metric; Manufactuer Part Number CL10A106KP8NNNC; LCSC Part # C19702
J6: Micro_SD_Card_Det2; microSD_HC_SOFNG_TF-008; Manufactuer Part Number TF-008; LCSC Part # C428465
U1: ECP5-CABGA256; BGA-256_14.0x14.0mm_Layout16x16_P0.8mm_Ball0.45mm_Pad0.32mm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; Manufactuer Part Number LFE5U-25F-6BG256C; LCSC Part # C1521614

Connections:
+3V3: C54.1, J6.4 (VDD); also elsewhere on the board
/uSD/SD_CLK: J6.5 (CLK), U1.P15 (PR32B/-/HS/RDQSN32)
/uSD/SD_CMD: J6.3 (CMD), U1.N16 (PR32A/+/HS/RDQS32)
/uSD/SD_DAT0: J6.7 (DAT0), U1.P14 (PR38B/-/HS/RDQ44)
/uSD/SD_DAT1: J6.8 (DAT1), U1.R14 (PR41B/-/HS/RDQ44)
/uSD/SD_DAT2: J6.1 (DAT2), U1.M15 (PR26D/-/RDQ32/PCLKC3_0)
/uSD/SD_DAT3: J6.2 (DAT3/CD), U1.M14 (PR32D/-/RDQ32)
/uSD/SD_DET: J6.10 (DET_A), U1.M16 (PR26C/+/RDQ32/PCLKT3_0)
GND: C54.2, J6.6 (VSS), J6.9 (DET_B), J6.11 (SHIELD); also elsewhere on the board

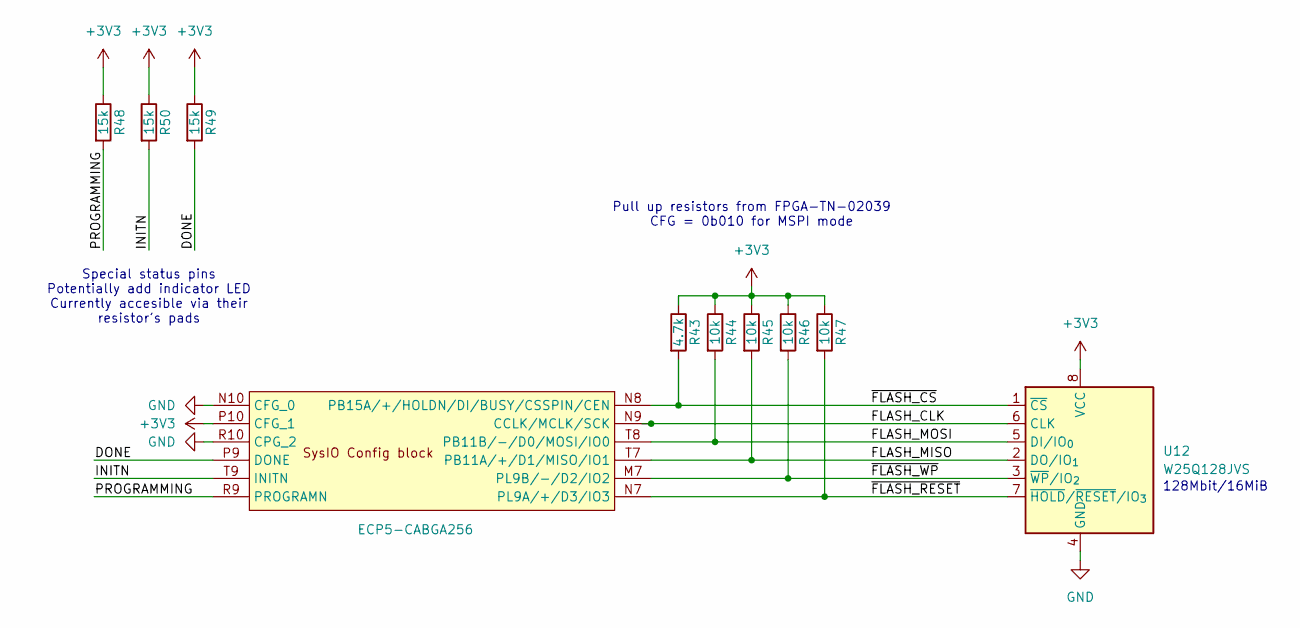
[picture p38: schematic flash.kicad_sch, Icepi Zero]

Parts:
R43: 4.7k; R_0402_1005Metric; Manufactuer Part Number 0402WGF4701TCE; LCSC Part # C25900
R44, R45, R46, R47: 10k; R_0402_1005Metric; Manufactuer Part Number 0402WGF1002TCE; LCSC Part # C25744
R48, R49, R50: 15k; R_0402_1005Metric; Manufactuer Part Number 0402WGF1502TCE; LCSC Part # C25756
U1: ECP5-CABGA256; BGA-256_14.0x14.0mm_Layout16x16_P0.8mm_Ball0.45mm_Pad0.32mm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; Manufactuer Part Number LFE5U-25F-6BG256C; LCSC Part # C1521614
U12: W25Q128JVS; SOIC-8_5.3x5.3mm_P1.27mm; Manufactuer Part Number W25Q128JVSIQ; LCSC Part # C97521

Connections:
+3V3: R43.1, R44.1, R45.1, R46.1, R47.1, R48.1, R49.1, R50.1, U1.P10 (CFG_1), U12.8 (VCC); also elsewhere on the board
/Flash/DONE: R49.2, U1.P9 (DONE)
/Flash/FLASH_CLK: U1.N9 (CCLK/MCLK/SCK), U12.6 (CLK)
/Flash/FLASH_MISO: R45.2, U1.T7 (PB11A/+/D1/MISO/IO1), U12.2 (DO/IO_{1})
/Flash/FLASH_MOSI: R44.2, U1.T8 (PB11B/-/D0/MOSI/IO0), U12.5 (DI/IO_{0})
/Flash/INITN: R50.2, U1.T9 (INITN)
/Flash/PROGRAMMING: R48.2, U1.R9 (PROGRAMN)
/Flash/~FLASH_CS: R43.2, U1.N8 (PB15A/+/HOLDN/DI/BUSY/CSSPIN/CEN), U12.1 (~CS)
/Flash/~FLASH_RESET: R47.2, U1.N7 (PL9A/+/D3/IO3), U12.7 (~HOLD/~RESET/IO_{3})
/Flash/~FLASH_WP: R46.2, U1.M7 (PL9B/-/D2/IO2), U12.3 (~WP/IO_{2})
GND: U1.N10 (CFG_0), U1.R10 (CPG_2), U12.4 (GND); also elsewhere on the board

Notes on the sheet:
128Mbit/16MiB
Special status pins Potentially add indicator LED Currently accesible via their resistor's pads
Pull up resistors from FPGA-TN-02039 CFG = 0b010 for MSPI mode

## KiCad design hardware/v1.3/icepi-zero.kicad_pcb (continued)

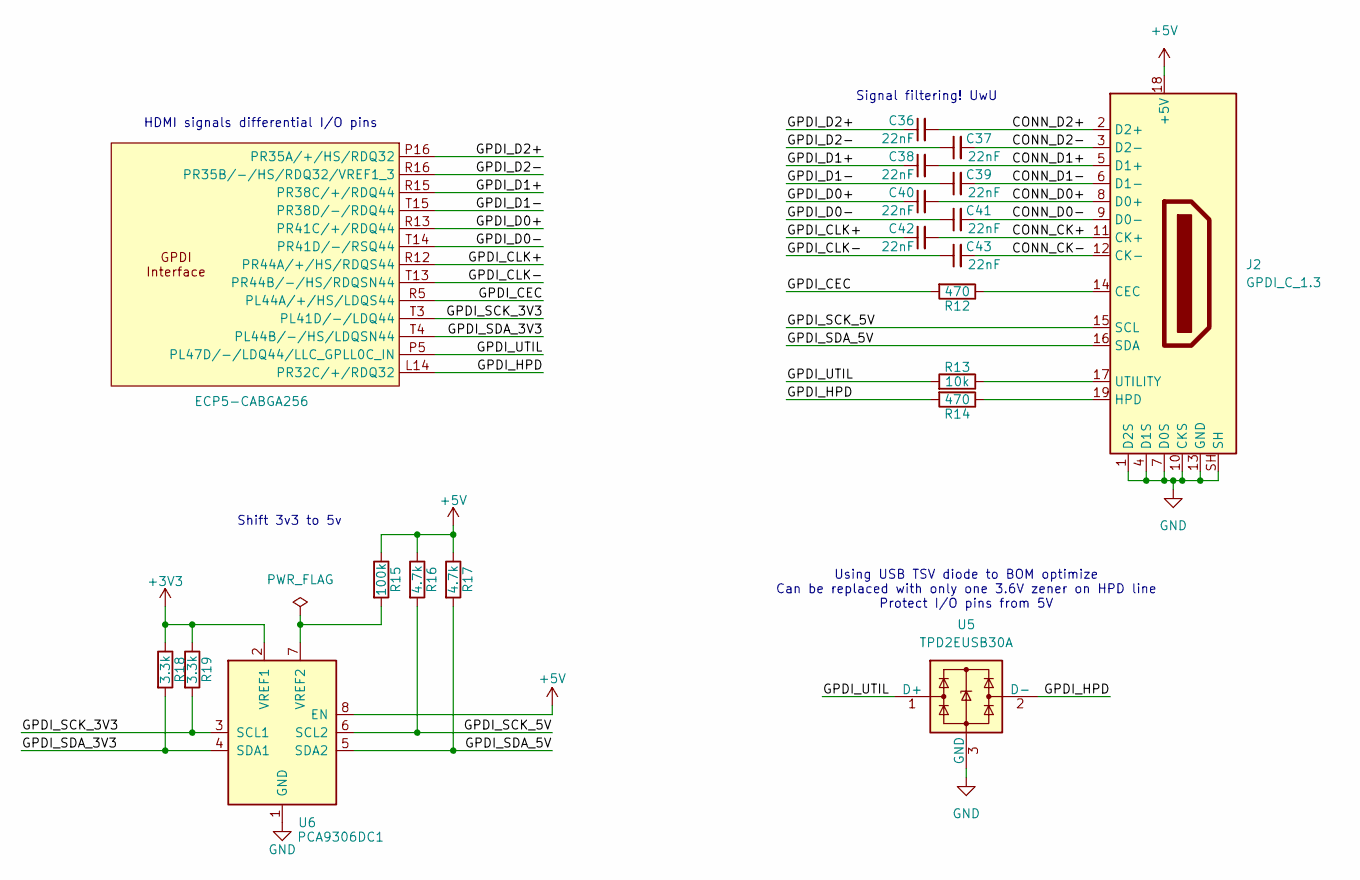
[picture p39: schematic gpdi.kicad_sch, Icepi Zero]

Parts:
C36, C37, C38, C39, C40, C41, C42, C43: 22nF; C_0402_1005Metric; Manufactuer Part Number 0402B223K500NT; LCSC Part # C1532
J2: GPDI_C_1.3; XKB Connection A71-05H4-111N1; Manufactuer Part Number A71-05H4-111N1; LCSC Part # C2682170
R12, R14: 470; R_0402_1005Metric; Manufactuer Part Number 0402WGF4700TCE; LCSC Part # C25117
R13: 10k; R_0402_1005Metric; Manufactuer Part Number 0402WGF1002TCE; LCSC Part # C25744
R15: 100k; R_0402_1005Metric; Manufactuer Part Number 0402WGF1003TCE; LCSC Part # C25741
R16, R17: 4.7k; R_0402_1005Metric; Manufactuer Part Number 0402WGF4701TCE; LCSC Part # C25900
R18, R19: 3.3k; R_0402_1005Metric; Manufactuer Part Number 0402WGF3301TCE; LCSC Part # C25890
U1: ECP5-CABGA256; BGA-256_14.0x14.0mm_Layout16x16_P0.8mm_Ball0.45mm_Pad0.32mm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; Manufactuer Part Number LFE5U-25F-6BG256C; LCSC Part # C1521614
U5: TPD2EUSB30A; Texas_DRT-3; Manufactuer Part Number TPD2EUSB30ADRTR; LCSC Part # C3011197
U6: PCA9306DC1; VSSOP-8_2.3x2mm_P0.5mm; Manufactuer Part Number PCA9306DC1; LCSC Part # C129510

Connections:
+3V3: R18.1, R19.1, U6.2 (VREF1); also elsewhere on the board
+5V: J2.18 (+5V), R15.1, R16.1, R17.1, U6.8 (EN); also elsewhere on the board
/GPDI/CONN_CK+: C42.2, J2.11 (CK+)
/GPDI/CONN_CK-: C43.2, J2.12 (CK-)
/GPDI/CONN_D0+: C40.2, J2.8 (D0+)
/GPDI/CONN_D0-: C41.2, J2.9 (D0-)
/GPDI/CONN_D1+: C38.2, J2.5 (D1+)
/GPDI/CONN_D1-: C39.2, J2.6 (D1-)
/GPDI/CONN_D2+: C36.2, J2.2 (D2+)
/GPDI/CONN_D2-: C37.2, J2.3 (D2-)
/GPDI/GPDI_CEC: R12.2, U1.R5 (PL44A/+/HS/LDQS44)
/GPDI/GPDI_CLK+: C42.1, U1.R12 (PR44A/+/HS/RDQS44)
/GPDI/GPDI_CLK-: C43.1, U1.T13 (PR44B/-/HS/RDQSN44)
/GPDI/GPDI_D0+: C40.1, U1.R13 (PR41C/+/RDQ44)
/GPDI/GPDI_D0-: C41.1, U1.T14 (PR41D/-/RSQ44)
/GPDI/GPDI_D1+: C38.1, U1.R15 (PR38C/+/RDQ44)
/GPDI/GPDI_D1-: C39.1, U1.T15 (PR38D/-/RDQ44)
/GPDI/GPDI_D2+: C36.1, U1.P16 (PR35A/+/HS/RDQ32)
/GPDI/GPDI_D2-: C37.1, U1.R16 (PR35B/-/HS/RDQ32/VREF1_3)
/GPDI/GPDI_HPD: R14.2, U1.L14 (PR32C/+/RDQ32), U5.2 (D-)
/GPDI/GPDI_SCK_3V3: R19.2, U1.T3 (PL41D/-/LDQ44), U6.3 (SCL1)
/GPDI/GPDI_SCK_5V: J2.15 (SCL), R16.2, U6.6 (SCL2)
/GPDI/GPDI_SDA_3V3: R18.2, U1.T4 (PL44B/-/HS/LDQSN44), U6.4 (SDA1)
/GPDI/GPDI_SDA_5V: J2.16 (SDA), R17.2, U6.5 (SDA2)
/GPDI/GPDI_UTIL: R13.2, U1.P5 (PL47D/-/LDQ44/LLC_GPLL0C_IN), U5.1 (D+)
GND: J2.1 (D2S), J2.4 (D1S), J2.7 (D0S), J2.10 (CKS), J2.13 (GND), J2.SH, U5.3 (GND), U6.1 (GND); also elsewhere on the board
unnamed: J2.14 (CEC), R12.1
unnamed: J2.19 (HPD), R14.1
unnamed: J2.17 (UTILITY), R13.1
unnamed: R15.2, U6.7 (VREF2)

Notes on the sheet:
Shift 3v3 to 5v
Using USB TSV diode to BOM optimize Can be replaced with only one 3.6V zener on HPD line Protect I/O pins from 5V
HDMI signals differential I/O pins
Signal filtering! UwU

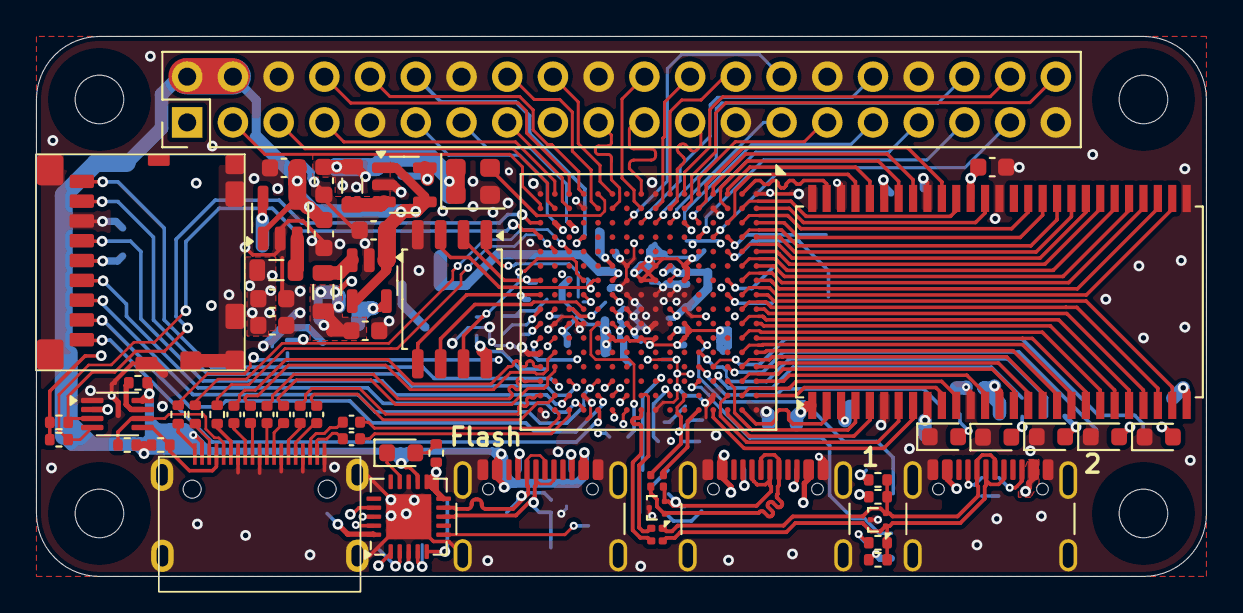
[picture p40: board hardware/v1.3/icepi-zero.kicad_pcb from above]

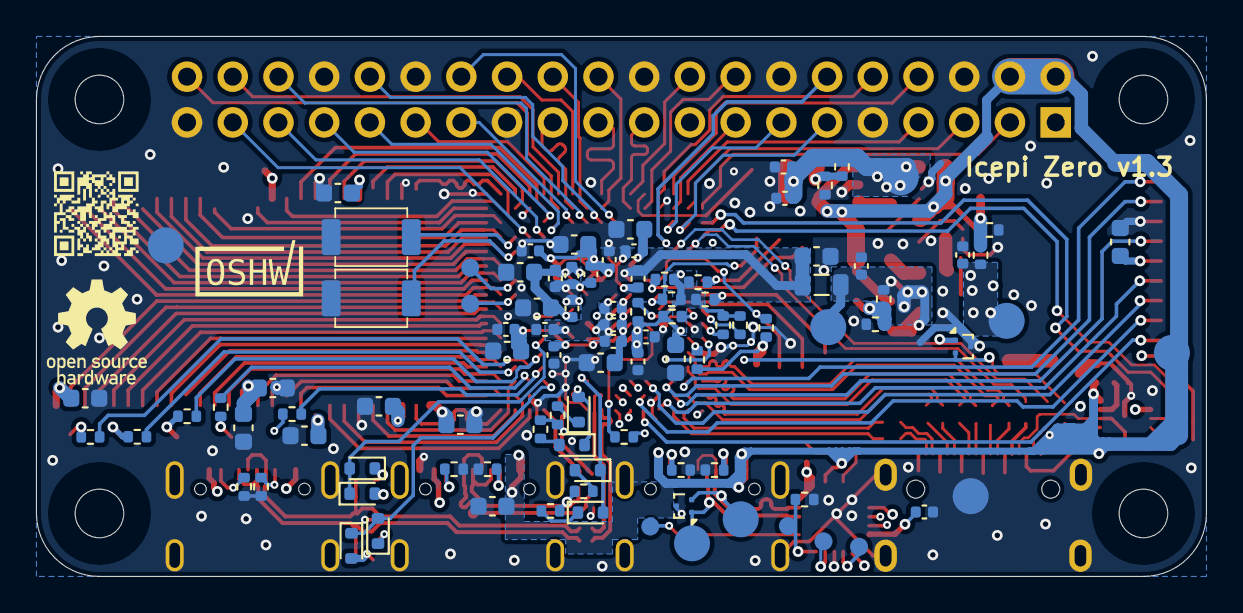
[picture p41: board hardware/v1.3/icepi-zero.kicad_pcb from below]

Board: 4 copper layers, 65.0 x 30.0 mm, 162 parts (99 on the bottom side), 176 nets.

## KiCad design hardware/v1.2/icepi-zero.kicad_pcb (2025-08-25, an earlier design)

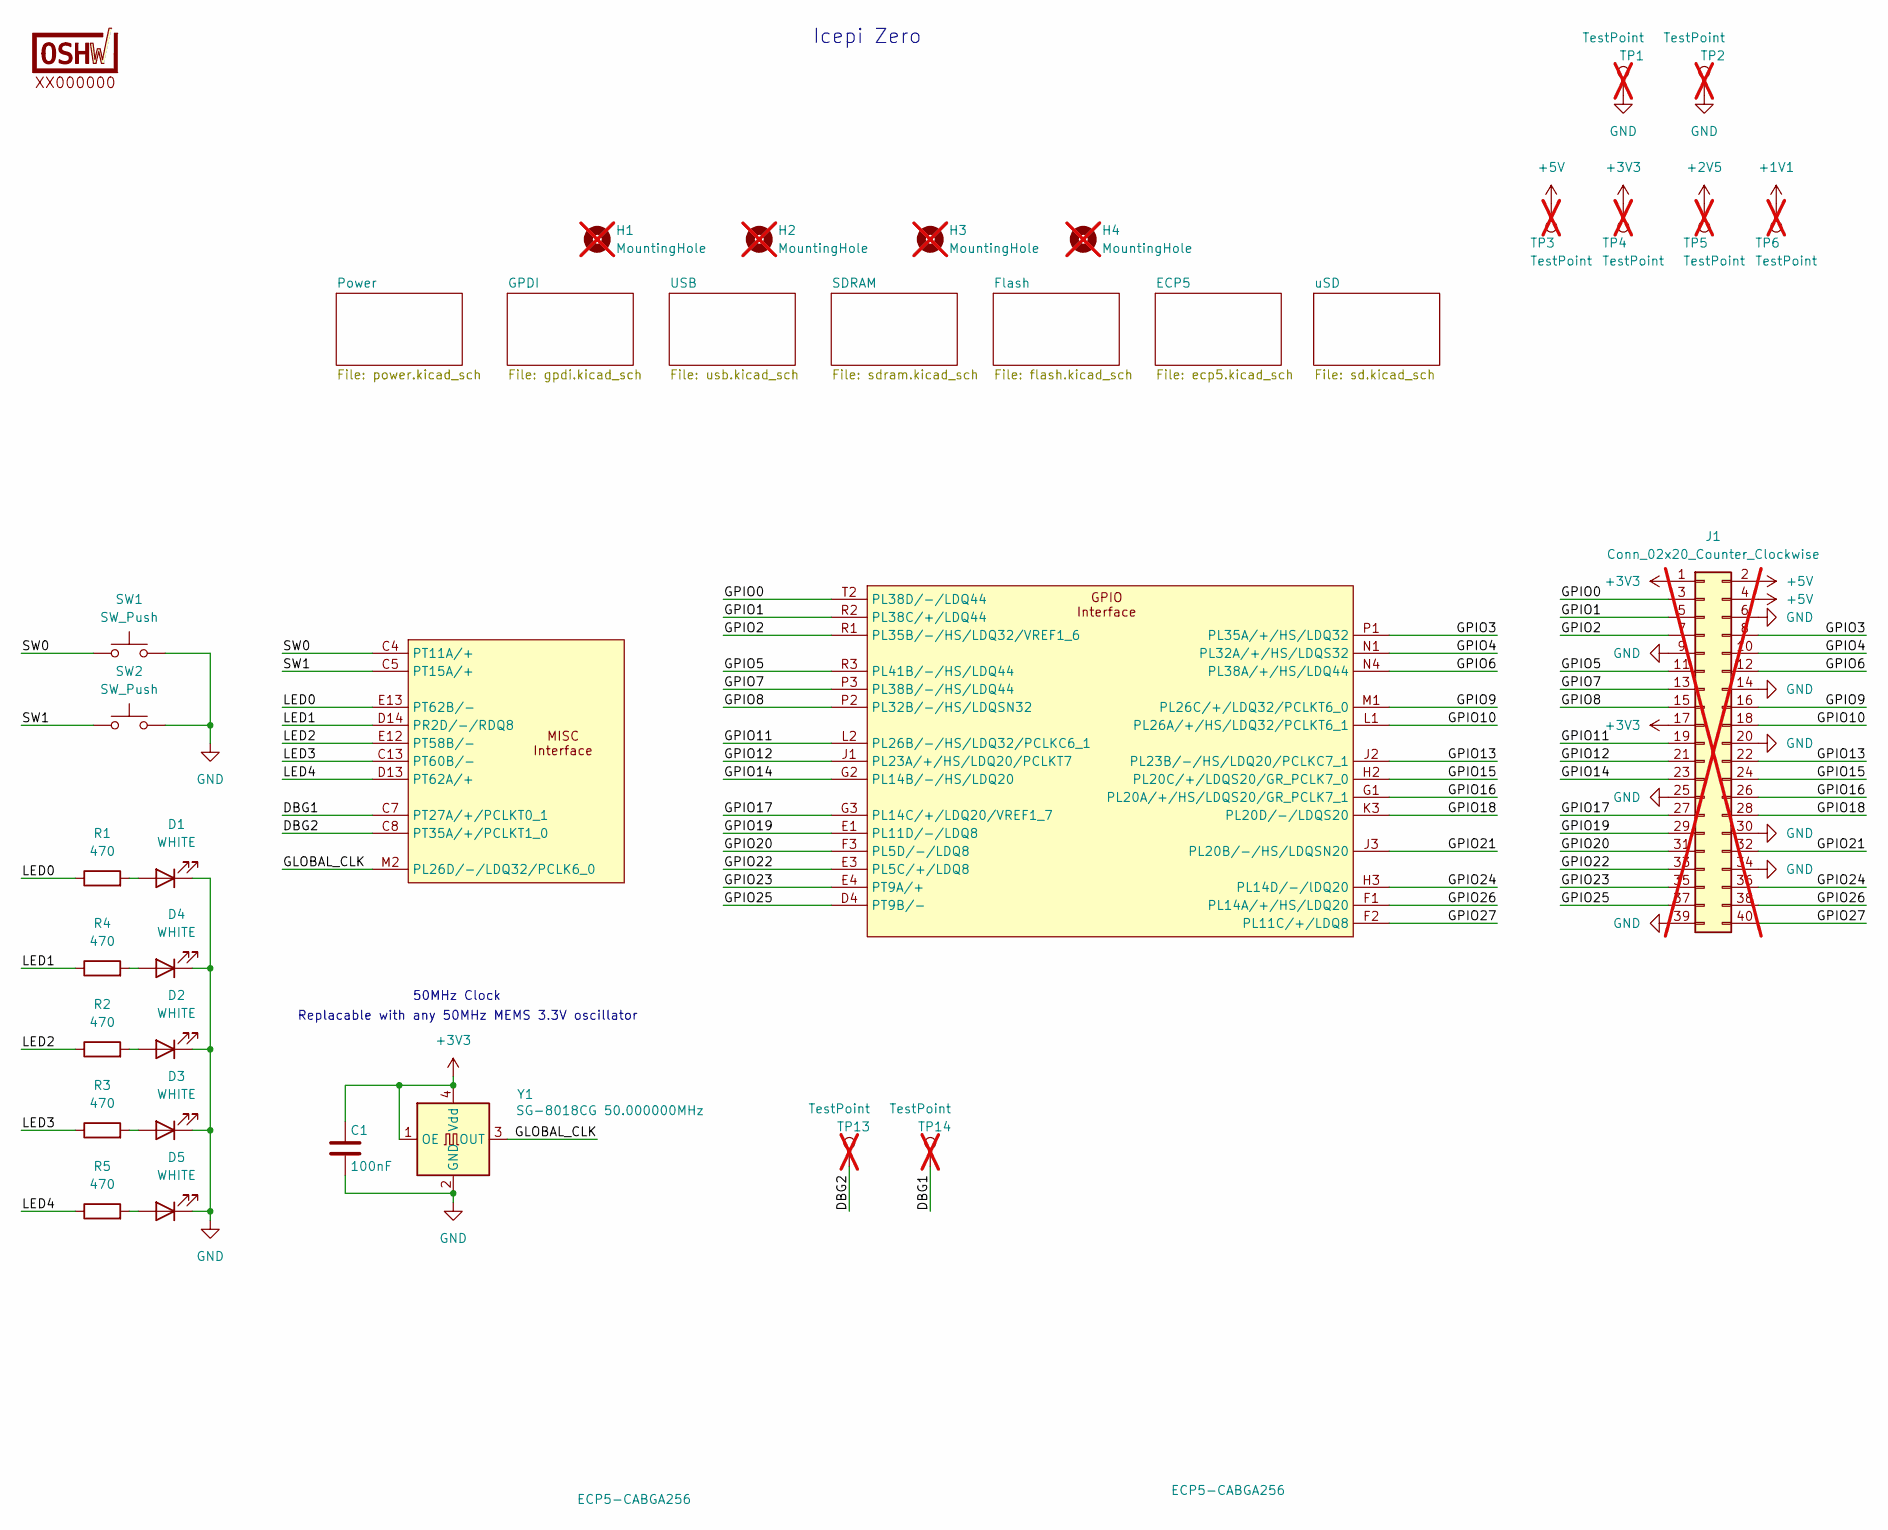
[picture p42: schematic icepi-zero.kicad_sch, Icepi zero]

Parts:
C1: 100nF; C_0402_1005Metric; LCSC Part # C307331
D1, D2, D3, D4, D5: WHITE; LED_0603_1608Metric; LCSC Part # C2290
H1, H2, H3, H4: MountingHole; MountingHole_2.7mm_M2.5; not fitted
J1: Conn_02x20_Counter_Clockwise; PinHeader_2x20_P2.54mm_Vertical; not fitted
LOGO1: OSHW-Certification-Mark-Logo_6x3mm_SilkScreen
R1, R2, R3, R4, R5: 470; R_0402_1005Metric; LCSC Part # C25117
SW1, SW2: SW_Push; switch_button_TS-1088-AR02016; LCSC Part # C720477
TP1, TP2, TP3, TP4, TP5, TP6: TestPoint; TestPoint_Pad_D2.0mm; not fitted
TP13, TP14: TestPoint; TestPoint_Pad_D1.0mm; not fitted
U1: ECP5-CABGA256; BGA-256_14.0x14.0mm_Layout16x16_P0.8mm_Ball0.45mm_Pad0.32mm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
Y1: SG-8018CG 50.000000MHz; Oscillator_SMD_SiT_PQFN-4Pin_2.5x2.0mm; LCSC Part # C390526

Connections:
+1V1: TP6.1; also elsewhere on the board
+2V5: TP5.1; also elsewhere on the board
+3V3: C1.1, J1.1, J1.17, TP4.1, Y1.1 (OE), Y1.4 (Vdd); also elsewhere on the board
+5V: J1.2, J1.4, TP3.1; also elsewhere on the board
/DBG1: TP14.1, U1.C7 (PT27A/+/PCLKT0_1)
/DBG2: TP13.1, U1.C8 (PT35A/+/PCLKT1_0)
/GPIO0: J1.3, U1.T2 (PL38D/-/LDQ44)
/GPIO1: J1.5, U1.R2 (PL38C/+/LDQ44)
/GPIO2: J1.7, U1.R1 (PL35B/-/HS/LDQ32/VREF1_6)
/GPIO3: J1.8, U1.P1 (PL35A/+/HS/LDQ32)
/GPIO4: J1.10, U1.N1 (PL32A/+/HS/LDQS32)
/GPIO5: J1.11, U1.R3 (PL41B/-/HS/LDQ44)
/GPIO6: J1.12, U1.N4 (PL38A/+/HS/LDQ44)
/GPIO7: J1.13, U1.P3 (PL38B/-/HS/LDQ44)
/GPIO8: J1.15, U1.P2 (PL32B/-/HS/LDQSN32)
/GPIO10: J1.18, U1.L1 (PL26A/+/HS/LDQ32/PCLKT6_1)
/GPIO11: J1.19, U1.L2 (PL26B/-/HS/LDQ32/PCLKC6_1)
/GPIO12: J1.21, U1.J1 (PL23A/+/HS/LDQ20/PCLKT7)
/GPIO13: J1.22, U1.J2 (PL23B/-/HS/LDQ20/PCLKC7_1)
/GPIO14: J1.23, U1.G2 (PL14B/-/HS/LDQ20)
/GPIO15: J1.24, U1.H2 (PL20C/+/LDQS20/GR_PCLK7_0)
/GPIO16: J1.26, U1.G1 (PL20A/+/HS/LDQS20/GR_PCLK7_1)
/GPIO17: J1.27, U1.G3 (PL14C/+/LDQ20/VREF1_7)
/GPIO18: J1.28, U1.K3 (PL20D/-/LDQS20)
/GPIO19: J1.29, U1.E1 (PL11D/-/LDQ8)
/GPIO20: J1.31, U1.F3 (PL5D/-/LDQ8)
/GPIO21: J1.32, U1.J3 (PL20B/-/HS/LDQSN20)
/GPIO22: J1.33, U1.E3 (PL5C/+/LDQ8)
/GPIO23: J1.35, U1.E4 (PT9A/+)
/GPIO24: J1.36, U1.H3 (PL14D/-/lDQ20)
/GPIO25: J1.37, U1.D4 (PT9B/-)
/GPIO26: J1.38, U1.F1 (PL14A/+/HS/LDQ20)
/GPIO27: J1.40, U1.F2 (PL11C/+/LDQ8)
/LED0: R1.1, U1.E13 (PT62B/-)
/LED1: R4.1, U1.D14 (PR2D/-/RDQ8)
/LED2: R2.1, U1.E12 (PT58B/-)
/LED3: R3.1, U1.C13 (PT60B/-)
/LED4: R5.1, U1.D13 (PT62A/+)
/SW0: SW1.1, U1.C4 (PT11A/+)
/SW1: SW2.1, U1.C5 (PT15A/+)
GND: C1.2, D1.1 (K), D2.1 (K), D3.1 (K), D4.1 (K), D5.1 (K), J1.6, J1.9, J1.14, J1.20, J1.25, J1.30, J1.34, J1.39, SW1.2, SW2.2, TP1.1, TP2.1, Y1.2 (GND); also elsewhere on the board
unnamed: D1.2 (A), R1.2
unnamed: D2.2 (A), R2.2
unnamed: D3.2 (A), R3.2
unnamed: D4.2 (A), R4.2
unnamed: D5.2 (A), R5.2

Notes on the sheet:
Icepi Zero
Replacable with any 50MHz MEMS 3.3V oscillator
50MHz Clock

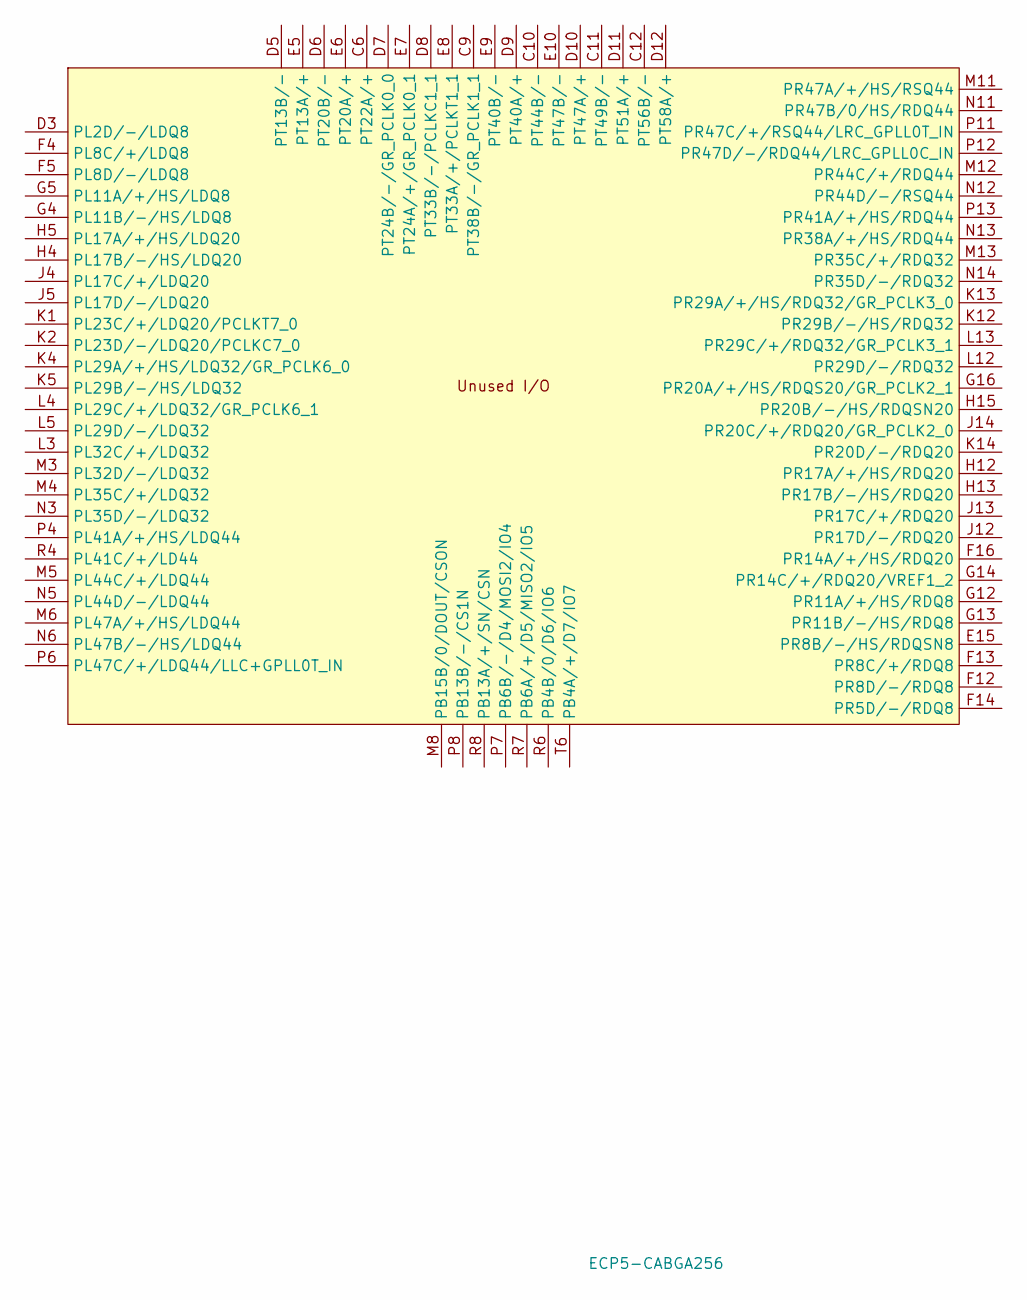
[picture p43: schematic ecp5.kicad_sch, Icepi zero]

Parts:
U1: ECP5-CABGA256; BGA-256_14.0x14.0mm_Layout16x16_P0.8mm_Ball0.45mm_Pad0.32mm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

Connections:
JTAG_TDI: U1.P11 (PR47C/+/RSQ44/LRC_GPLL0T_IN); also elsewhere on the board
JTAG_TDO: U1.M11 (PR47A/+/HS/RSQ44); also elsewhere on the board
JTAG_TMS: U1.N12 (PR44D/-/RSQ44); also elsewhere on the board


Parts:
C39, C40, C41, C42, C43, C44: 100nF; C_0402_1005Metric; LCSC Part # C307331
U1: ECP5-CABGA256; BGA-256_14.0x14.0mm_Layout16x16_P0.8mm_Ball0.45mm_Pad0.32mm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
U10: W9825G6KH; TSOP-II-54_22.2x10.16mm_P0.8mm; LCSC Part # C62246

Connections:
+3V3: C39.1, C40.1, C41.1, C42.1, C43.1, C44.1, U10.1 (VDD), U10.3 (VDDQ), U10.9 (VDDQ), U10.14 (VDD), U10.27 (VDD), U10.43 (VDDQ), U10.49 (VDDQ); also elsewhere on the board
/SDRAM/A0: U1.B10 (PT44A/+), U10.23 (A0)
/SDRAM/A1: U1.A9 (PT42A/+), U10.24 (A1)
/SDRAM/A2: U1.B9 (PT38A/+/GR_PCLK1_0), U10.25 (A2)
/SDRAM/A3: U1.A8 (PT29B/-/PCLKC0_0), U10.26 (A3)
/SDRAM/A4: U1.B8 (PT35B/-/PCLK1_0), U10.29 (A4)
/SDRAM/A5: U1.A7 (PT29A/+/PCLKT0_0), U10.30 (A5)
/SDRAM/A6: U1.B7 (PT27B/-/PCLKC0_1), U10.31 (A6)
/SDRAM/A7: U1.A6 (PT18B/-), U10.32 (A7)
/SDRAM/A8: U1.B6 (PT22B/-), U10.33 (A8)
/SDRAM/A9: U1.A5 (PT18A/+), U10.34 (A9)
/SDRAM/A10: U1.A10 (PT42B/-), U10.22 (A10)
/SDRAM/A11: U1.B5 (PT15B/-), U10.35 (A11)
/SDRAM/A12: U1.A4 (PT6B/-), U10.36 (A12)
/SDRAM/BA0: U1.A11 (PT53A/+), U10.20 (BA0)
/SDRAM/BA1: U1.B11 (PT49A/+), U10.21 (BA1)
/SDRAM/CKE: U1.B4 (PT11B/-), U10.37 (CKE)
/SDRAM/CLK: U1.A3 (PT6A/+), U10.38 (CLK)
/SDRAM/D0: U1.B16 (PR2A/+/HS/RDQ8), U10.2 (DQ0)
/SDRAM/D1: U1.C14 (PR2C/+/RDQ8), U10.4 (DQ1)
/SDRAM/D2: U1.C16 (PR5A/+/HS/RDQ8), U10.5 (DQ2)
/SDRAM/D3: U1.C15 (PR5B/-/HS/RDQ8), U10.7 (DQ3)
/SDRAM/D4: U1.D16 (PR8A/+/HS/RDQS8), U10.8 (DQ4)
/SDRAM/D5: U1.A15 (PT67B/-), U10.10 (DQ5)
/SDRAM/D6: U1.B15 (PR2B/-/HS/RDQ8/S0_IN), U10.11 (DQ6)
/SDRAM/D7: U1.A14 (PT65B/-), U10.13 (DQ7)
/SDRAM/D8: U1.A2 (PT4A/+), U10.42 (DQ8)
/SDRAM/D9: U1.B2 (PL2B/-/HS/LDQ8), U10.44 (DQ9)
/SDRAM/D10: U1.E2 (PL8B/-/HS/LDQSN8), U10.45 (DQ10)
/SDRAM/D11: U1.D1 (PL8A/+/HS/LDQS8), U10.47 (DQ11)
/SDRAM/D12: U1.C2 (PL5B/-/HS/LDQ8), U10.48 (DQ12)
/SDRAM/D13: U1.C1 (PL5A/+/HS/LDQ8), U10.50 (DQ13)
/SDRAM/D14: U1.C3 (PL2C/+/LDQ8), U10.51 (DQ14)
/SDRAM/D15: U1.B1 (PL2A/+/HS/LDQ8), U10.53 (DQ15)
/SDRAM/DQM0: U1.B14 (PT67A/+), U10.15 (DQML)
/SDRAM/DQM1: U1.B3 (PT4B/-), U10.39 (DQMH)
/SDRAM/~CAS: U1.B13 (PT60A/+), U10.17 (~CAS)
/SDRAM/~CS: U1.B12 (PT56A/+), U10.19 (~CS)
/SDRAM/~RAS: U1.A12 (PT53B/-), U10.18 (~RAS)
/SDRAM/~WE: U1.A13 (PT65A/+), U10.16 (~WE)
GND: C39.2, C40.2, C41.2, C42.2, C43.2, C44.2, U10.6 (VSSQ), U10.12 (VSSQ), U10.28 (VSS), U10.41 (VSS), U10.46 (VSSQ), U10.52 (VSSQ), U10.54 (VSS); also elsewhere on the board

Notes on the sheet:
256MiB Memory Can be replaced by digikey 512MiB Memory if I have the $$$


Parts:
C2, C8, C9, C10, C20, C24, C26, C45, C49: 10uF; C_0603_1608Metric; LCSC Part # C19702
C3, C7, C11, C12, C13, C14, C15, C16, C19, C21, C22, C25, C27, C28, C46, C48, C50, C51, C52: 100nF; C_0402_1005Metric; LCSC Part # C307331
C4, C5, C6, C17, C18, C23: 22uF; C_0603_1608Metric; LCSC Part # C59461
FB1: 100R@100MHz; L_0805_2012Metric; LCSC Part # C1015
L1, L2, L3: 2.2uH; L_0805_2012Metric; LCSC Part # C1043
R6: 10k; R_0402_1005Metric; LCSC Part # C25744
R7: 12k; R_0402_1005Metric; LCSC Part # C25752
R8, R10: 15k; R_0402_1005Metric; LCSC Part # C25756
R9: 4.7k; R_0402_1005Metric; LCSC Part # C25900
R11: 3.3k; R_0402_1005Metric; LCSC Part # C25890
U1: ECP5-CABGA256; BGA-256_14.0x14.0mm_Layout16x16_P0.8mm_Ball0.45mm_Pad0.32mm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
U2, U3, U4: TLV62569DBV; SOT-23-5; LCSC Part # C141836

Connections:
+1V1: C5.1, C6.1, C7.1, C8.1, C9.1, C10.1, C11.1, C12.1, C13.1, C14.1, C15.1, C16.1, L1.2, R6.1, U1.G6 (VCC), U1.G7 (VCC), U1.G9 (VCC), U1.L8 (VCC), U1.L9 (VCC), U1.L10 (VCC); also elsewhere on the board
+2V5: C18.1, C19.1, FB1.1, L2.2, R8.1; also elsewhere on the board
+3V3: C2.1, C3.1, C24.1, C25.1, C26.1, C27.1, C28.1, C45.1, C46.1, C48.1, C49.1, C50.1, C51.1, C52.1, L3.2, R10.1, U1.F6 (VCCIO0), U1.F7 (VCCIO0), U1.F10 (VCCIO1), U1.F11 (VCCIO1), U1.H6 (VCCIO7), U1.H7 (VCCIO7), U1.H11 (VCCIO2), U1.J6 (VCCIO6), U1.J7 (VCCIO6), U1.J11 (VCCIO2), U1.K11 (VCCIO3), U1.L6 (VCCIO8), U1.L11 (VCCIO3); also elsewhere on the board
+5V: C4.1, C17.1, C23.1, U2.1 (EN), U2.4 (VIN), U3.1 (EN), U3.4 (VIN), U4.1 (EN), U4.4 (VIN); also elsewhere on the board
/Power/FILTERED_2V5: C20.1, C21.1, C22.1, FB1.2, U1.G11 (VCCAUX), U1.L7 (VCCAUX)
GND: C2.2, C3.2, C4.2, C5.2, C6.2, C7.2, C8.2, C9.2, C10.2, C11.2, C12.2, C13.2, C14.2, C15.2, C16.2, C17.2, C18.2, C19.2, C20.2, C21.2, C22.2, C23.2, C24.2, C25.2, C26.2, C27.2, C28.2, C45.2, C46.2, C48.2, C49.2, C50.2, C51.2, C52.2, R7.2, R9.2, R11.2, U1.A1 (GND), U1.A16 (GND), U1.D2 (GND), U1.D15 (GND), U1.F8 (GND), U1.F9 (GND), U1.G8 (GND), U1.G10 (GND), U1.H1 (GND), U1.H8 (GND), U1.H9 (GND), U1.H10 (GND), U1.H16 (GND), U1.J8 (GND), U1.J9 (GND), U1.J10 (GND), U1.K6 (GND), U1.K7 (GND), U1.K8 (GND), U1.K9 (GND), U1.K10 (GND), U1.N2 (GND), U1.N15 (GND), U1.T1 (GND), U1.T5 (GND), U1.T12 (GND), U1.T16 (GND), U2.2 (GND), U3.2 (GND), U4.2 (GND); also elsewhere on the board
unnamed: R6.2, R7.1, U2.5 (FB)
unnamed: L1.1, U2.3 (SW)
unnamed: R8.2, R9.1, U3.5 (FB)
unnamed: L2.1, U3.3 (SW)
unnamed: R10.2, R11.1, U4.5 (FB)
unnamed: L3.1, U4.3 (SW)

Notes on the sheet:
(15/4.7+1)*0.6=2.5
(10/12+1)*0.6=1.1
(15/3.3+1)*0.6=3.3
Voltage Regulators

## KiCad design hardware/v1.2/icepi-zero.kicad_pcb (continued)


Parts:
C38: 100nF; C_0402_1005Metric; LCSC Part # C307331
D6, D7, D9, D10, D11, D12, D13, D14: 1N914WT; D_SOD-523; LCSC Part # C2836064
D8: RED; LED_0603_1608Metric; LCSC Part # C2286
J3, J4, J5: USB_C_Receptacle_USB2.0_14P; USB_C_Receptacle_GCT_USB4105-xx-A_16P_TopMnt_Horizontal; LCSC Part # C2765186
R20, R21, R22, R23: 4.7k; R_0402_1005Metric; LCSC Part # C25900
R24, R25, R29, R31, R36, R37: 5.1k; R_0402_1005Metric; LCSC Part # C25905
R26, R28, R32, R35, R41: 1k; R_0402_1005Metric; LCSC Part # C11702
R27, R34, R39, R42: 15k; R_0402_1005Metric; LCSC Part # C25756
R30, R33, R38, R40: 27; R_0201_0603Metric; LCSC Part # C473051
TP7, TP8: TestPoint; TestPoint_Pad_D2.0mm; not fitted
TP9, TP10, TP11, TP12: TestPoint; TestPoint_Pad_D1.0mm; not fitted
U1: ECP5-CABGA256; BGA-256_14.0x14.0mm_Layout16x16_P0.8mm_Ball0.45mm_Pad0.32mm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
U6: FT231XQ; QFN-20-1EP_4x4mm_P0.5mm_EP2.5x2.5mm; LCSC Part # C132159
U7, U8, U9: TPD2EUSB30A; Texas_DRT-3; LCSC Part # C3011197

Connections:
+3V3: R20.1, R21.1, R22.1; also elsewhere on the board
+5V: J3.A4 (VBUS), J3.A9 (VBUS), J3.B4 (VBUS), J3.B9 (VBUS), J4.A4 (VBUS), J4.A9 (VBUS), J4.B4 (VBUS), J4.B9 (VBUS), J5.A4 (VBUS), J5.A9 (VBUS), J5.B4 (VBUS), J5.B9 (VBUS), U6.12 (VCC); also elsewhere on the board
/USB/D0+: R40.1, R41.2, R42.2, U1.F15 (PR11C/+/RDQ8)
/USB/D0-: R38.1, U1.E16 (PR11D/-/RDQ8)
/USB/D0A+: J5.A6 (D+), J5.B6 (D+), R40.2, U9.1 (D+)
/USB/D0A-: J5.A7 (D-), J5.B7 (D-), R32.2, R34.2, R38.2, U9.2 (D-)
/USB/D1+: R33.1, U1.J16 (PR23A/+/HS/RDQ20/PCLKT2_1)
/USB/D1-: R30.1, U1.J15 (PR23B/-/HS/RDQ20/PCLKC2_1)
/USB/D1A+: J4.A6 (D+), J4.B6 (D+), R33.2, R35.2, R39.2, U8.1 (D+)
/USB/D1A-: J4.A7 (D-), J4.B7 (D-), R26.2, R27.2, R30.2, U8.2 (D-)
/USB/D2+: J3.A6 (D+), J3.B6 (D+), TP8.1, U6.8 (USBDP), U7.1 (D+)
/USB/D2-: J3.A7 (D-), J3.B7 (D-), TP7.1, U6.9 (USBDM), U7.2 (D-)
/USB/USB0_PULL_D+: D13.2 (A), D14.1 (K), U1.G15 (PR14B/-/HS/RDQ20)
/USB/USB0_PULL_D-: D9.2 (A), D10.1 (K), U1.H14 (PR14D/-/RDQ20)
/USB/USB1_PULL_D+: D11.2 (A), D12.1 (K), U1.E14 (PR5C/+/RDQ8)
/USB/USB1_PULL_D-: D6.2 (A), D7.1 (K), U1.E11 (PT51B/-)
/USB/USB_RXD: U1.K15 (PR23D/-/RDQ20/PCLKC2_0), U6.1 (RXD)
/USB/USB_TXD: U1.K16 (PR23C/-/RDQ20/PCLKT2_0), U6.17 (TXD)
/USB/~RXLED: D8.1 (K), U6.14 (CBUS1)
/USB/~USB_DTR: U1.L15 (PR26B/-/HS/RDQ32/PCLKC3_1), U6.18 (~DTR)
/USB/~USB_RTS: U1.L16 (PR26A/+/HS/RDQ32/PCLKT3_1), U6.19 (~RTS)
GND: C38.2, J3.A1 (GND), J3.A12 (GND), J3.B1 (GND), J3.B12 (GND), J3.S1 (SHIELD), J4.A1 (GND), J4.A12 (GND), J4.B1 (GND), J4.B12 (GND), J4.S1 (SHIELD), J5.A1 (GND), J5.A12 (GND), J5.B1 (GND), J5.B12 (GND), J5.S1 (SHIELD), R23.2, R24.2, R25.1, R29.2, R31.1, R36.2, R37.1, U6.3 (GND), U6.13 (GND), U6.21 (GND), U7.3 (GND), U8.3 (GND), U9.3 (GND); also elsewhere on the board
JTAG_TCK: R20.2, TP9.1, U1.T10 (TCK), U6.4 (~DSR)
JTAG_TDI: R21.2, TP10.1, U1.P11 (PR47C/+/RSQ44/LRC_GPLL0T_IN), U1.R11 (TDI), U6.2 (~RI)
JTAG_TDO: R22.2, TP11.1, U1.M10 (TDO), U1.M11 (PR47A/+/HS/RSQ44), U6.6 (~CTS)
JTAG_TMS: R23.1, TP12.1, U1.N12 (PR44D/-/RSQ44), U1.T11 (TMS), U6.5 (~DCD)
unnamed: D6.1 (K), R26.1
unnamed: D7.2 (A), R27.1
unnamed: D8.2 (A), R28.2
unnamed: D9.1 (K), R32.1
unnamed: D10.2 (A), R34.1
unnamed: D11.1 (K), R35.1
unnamed: D12.2 (A), R39.1
unnamed: D13.1 (K), R41.1
unnamed: D14.2 (A), R42.1
unnamed: J3.A5 (CC1), R24.1
unnamed: J3.B5 (CC2), R25.2
unnamed: J4.A5 (CC1), R29.1
unnamed: J4.B5 (CC2), R31.2
unnamed: J5.A5 (CC1), R36.1
unnamed: J5.B5 (CC2), R37.2
unnamed: C38.1, R28.1, U6.10 (3V3OUT), U6.11 (~RESET), U6.20 (VCCIO)

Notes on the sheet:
~{USB_DCD}
~{USB_RI}
USB to UART and JTAG
The FTDI chip can probably bit bang the JTAG output on any pin: https://umarcor.github.io/openFPGALoader/guide/advanced.html ULX chose the pins because to program their esp32, they needed specific uart outputs, and the ones left got used as JTAG
~{USB_CTS}


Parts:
C47: 10uF; C_0603_1608Metric; LCSC Part # C19702
J6: Micro_SD_Card_Det2; microSD_HC_SOFNG_TF-008; LCSC Part # C428465
U1: ECP5-CABGA256; BGA-256_14.0x14.0mm_Layout16x16_P0.8mm_Ball0.45mm_Pad0.32mm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

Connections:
+3V3: C47.1, J6.4 (VDD); also elsewhere on the board
/uSD/SD_CLK: J6.5 (CLK), U1.P15 (PR32B/-/HS/RDQSN32)
/uSD/SD_CMD: J6.3 (CMD), U1.N16 (PR32A/+/HS/RDQS32)
/uSD/SD_DAT0: J6.7 (DAT0), U1.P14 (PR38B/-/HS/RDQ44)
/uSD/SD_DAT1: J6.8 (DAT1), U1.R14 (PR41B/-/HS/RDQ44)
/uSD/SD_DAT2: J6.1 (DAT2), U1.M15 (PR26D/-/RDQ32/PCLKC3_0)
/uSD/SD_DAT3: J6.2 (DAT3/CD), U1.M14 (PR32D/-/RDQ32)
/uSD/SD_DET: J6.10 (DET_A), U1.M16 (PR26C/+/RDQ32/PCLKT3_0)
GND: C47.2, J6.6 (VSS), J6.9 (DET_B), J6.11 (SHIELD); also elsewhere on the board


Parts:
R43: 4.7k; R_0402_1005Metric; LCSC Part # C25900
R44, R45, R46, R47: 10k; R_0402_1005Metric; LCSC Part # C25744
R48, R49, R50: 15k; R_0402_1005Metric; LCSC Part # C25756
U1: ECP5-CABGA256; BGA-256_14.0x14.0mm_Layout16x16_P0.8mm_Ball0.45mm_Pad0.32mm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
U11: W25Q128JVS; SOIC-8_5.3x5.3mm_P1.27mm; LCSC Part # C97521

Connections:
+3V3: R43.1, R44.1, R45.1, R46.1, R47.1, R48.1, R49.1, R50.1, U1.P10 (CFG_1), U11.8 (VCC); also elsewhere on the board
/Flash/FLASH_CLK: U1.N9 (CCLK/MCLK/SCK), U11.6 (CLK)
DONE: R49.2, U1.P9 (DONE)
FLASH_MISO: R44.2, U1.T7 (PB11A/+/D1/MISO/IO1), U11.2 (DO/IO_{1})
FLASH_MOSI: R45.2, U1.T8 (PB11B/-/D0/MOSI/IO0), U11.5 (DI/IO_{0})
GND: U1.N10 (CFG_0), U1.R10 (CPG_2), U11.4 (GND); also elsewhere on the board
INITN: R50.2, U1.T9 (INITN)
PROGRAMMING: R48.2, U1.R9 (PROGRAMN)
~FLASH_CS: R43.2, U1.N8 (PB15A/+/HOLDN/DI/BUSY/CSSPIN/CEN), U11.1 (~CS)
~FLASH_RESET: R46.2, U1.N7 (PL9A/+/D3/IO3), U11.7 (~HOLD/~RESET/IO_{3})
~FLASH_WP: R47.2, U1.M7 (PL9B/-/D2/IO2), U11.3 (~WP/IO_{2})

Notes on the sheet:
128Mbit/16MiB
TODO: DONE!
Pull up resistors, click to see docs


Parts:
C29, C30, C31, C32, C33, C34, C35, C36: 22nF; C_0402_1005Metric; LCSC Part # C1532
C37: 100pF; C_0402_1005Metric; LCSC Part # C1546
J2: GPDI_C_1.3; XKB Connection A71-05H4-111N1; Manufactuer Part Number A71-05H4-111N1; LCSC Part # C2682170
R12, R14: 470; R_0402_1005Metric; LCSC Part # C25117
R13: 10k; R_0402_1005Metric; LCSC Part # C25744
R15: 100k; R_0402_1005Metric; LCSC Part # C25741
R16, R17: 4.7k; R_0402_1005Metric; LCSC Part # C25900
R18, R19: 3.3k; R_0402_1005Metric; LCSC Part # C25890
U1: ECP5-CABGA256; BGA-256_14.0x14.0mm_Layout16x16_P0.8mm_Ball0.45mm_Pad0.32mm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
U5: PCA9306DC1; VSSOP-8_2.3x2mm_P0.5mm; LCSC Part # C129510

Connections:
+3V3: R18.1, R19.1, U5.2 (VREF1); also elsewhere on the board
+5V: J2.18 (+5V), R15.1, R16.1, R17.1, U5.8 (EN); also elsewhere on the board
/GPDI/CONN_CK+: C35.2, J2.11 (CK+)
/GPDI/CONN_CK-: C36.2, J2.12 (CK-)
/GPDI/CONN_D0+: C33.2, J2.8 (D0+)
/GPDI/CONN_D0-: C34.2, J2.9 (D0-)
/GPDI/CONN_D1+: C31.2, J2.5 (D1+)
/GPDI/CONN_D1-: C32.2, J2.6 (D1-)
/GPDI/CONN_D2+: C29.2, J2.2 (D2+)
/GPDI/CONN_D2-: C30.2, J2.3 (D2-)
/GPDI/GPDI_CEC: R12.2, U1.R5 (PL44A/+/HS/LDQS44)
/GPDI/GPDI_CLK+: C35.1, U1.R12 (PR44A/+/HS/RDQS44)
/GPDI/GPDI_CLK-: C36.1, U1.T13 (PR44B/-/HS/RDQSN44)
/GPDI/GPDI_D0+: C33.1, U1.R13 (PR41C/+/RDQ44)
/GPDI/GPDI_D0-: C34.1, U1.T14 (PR41D/-/RSQ44)
/GPDI/GPDI_D1+: C31.1, U1.R15 (PR38C/+/RDQ44)
/GPDI/GPDI_D1-: C32.1, U1.T15 (PR38D/-/RDQ44)
/GPDI/GPDI_D2+: C29.1, U1.P16 (PR35A/+/HS/RDQ32)
/GPDI/GPDI_D2-: C30.1, U1.R16 (PR35B/-/HS/RDQ32/VREF1_3)
/GPDI/GPDI_HPD: R14.2, U1.L14 (PR32C/+/RDQ32)
/GPDI/GPDI_SCK_3V3: R19.2, U1.T3 (PL41D/-/LDQ44), U5.3 (SCL1)
/GPDI/GPDI_SCK_5V: J2.15 (SCL), R16.2, U5.6 (SCL2)
/GPDI/GPDI_SDA_3V3: R18.2, U1.T4 (PL44B/-/HS/LDQSN44), U5.4 (SDA1)
/GPDI/GPDI_SDA_5V: J2.16 (SDA), R17.2, U5.5 (SDA2)
/GPDI/GPDI_UTIL: R13.2, U1.P5 (PL47D/-/LDQ44/LLC_GPLL0C_IN)
GND: C37.2, J2.1 (D2S), J2.4 (D1S), J2.7 (D0S), J2.10 (CKS), J2.13 (GND), J2.SH, U5.1 (GND); also elsewhere on the board
unnamed: J2.14 (CEC), R12.1
unnamed: J2.19 (HPD), R14.1
unnamed: J2.17 (UTILITY), R13.1
unnamed: C37.1, R15.2, U5.7 (VREF2)

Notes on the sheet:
Shift 3v3 to 5v
HDMI signals must go into differential pairs

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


Board: 4 copper layers, 65.0 x 30.0 mm, 159 parts (94 on the bottom side), 176 nets.

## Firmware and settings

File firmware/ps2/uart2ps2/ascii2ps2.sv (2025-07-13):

module ascii2ps2 #(
	parameter BUFFER_SIZE = 15
) (
    input clk,
    input reset,

    // UART input
    input [7:0] ascii,
    input       latch,

    // PS2 Scancode output
    input              ready,
    output logic [7:0] scancode,
    output logic       send,
    output wire shifts
);
    logic                     [7:0] buffer [0:BUFFER_SIZE-1];
    logic [$clog2(BUFFER_SIZE)-1:0] waddress;
    logic [$clog2(BUFFER_SIZE)-1:0] raddress;

    wire [7:0] scancode_press;
    wire shift;
    assign shifts = shift;

    scancode_translator translator(
        .ascii(ascii),
        .ps2(scancode_press),
        .shift(shift)
    );

    always_ff @(posedge clk) begin
        if (reset) begin
            scancode = 0;
            send = 0;
            waddress = 0;
            raddress = 0;
        end else begin
        if (latch && ((raddress == BUFFER_SIZE-1) ? 0 : raddress+1) != waddress) begin
            // Shifts
            if (shift) begin
                buffer[waddress] <= 8'h12; // Press shift
                buffer[waddress+1] <= scancode_press;
                buffer[waddress+2] <= 8'hF0;

                if (waddress >= BUFFER_SIZE-3) begin
                    buffer[0] <= scancode_press;

                    // Release shift
                    buffer[1] <= 8'hF0;
                    buffer[2] <= 8'h12;
                end else begin
                    buffer[waddress+3] <= scancode_press;

                    buffer[waddress+4] <= 8'hF0;
                    buffer[waddress+5] <= 8'h12;
                end

                if (waddress >= BUFFER_SIZE-3) begin
                    waddress <= 3;
                end else if (waddress >= BUFFER_SIZE-6) begin
                    waddress <= 0;
                end else begin
                    waddress <= waddress + 6;
                end
            end else begin
                // No shift
                buffer[waddress] <= scancode_press;
                buffer[waddress+1] <= 8'hF0;
                buffer[waddress+2] <= scancode_press;

                if (waddress >= BUFFER_SIZE-3) begin
                    waddress <= 0;
                end else begin
                    waddress <= waddress + 3;
                end
            end
        end

        if (send) begin
            send <= 0; // Send should be pulse of 1 clk cycle
        end else if (waddress != raddress && ready) begin
            // We need to send some characters
            send <= 1;
            scancode <= buffer[raddress];

            if (raddress >= BUFFER_SIZE-1) begin
                raddress <= 0;
            end else begin
                raddress <= raddress + 1;
            end
        end
        end
    end
endmodule

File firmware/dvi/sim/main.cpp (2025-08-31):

#include <iostream>
#include <string>

#include <boost/program_options.hpp>
namespace po = boost::program_options;

#include <SDL3/SDL.h>

#include <verilated.h>
#include <verilated_vcd_c.h>

#include "../obj_dir/Vvga.h"

constexpr int DEFAULT_W = 640;
constexpr int DEFAULT_H = 480;

static auto destroyWindow = [](SDL_Window* w) { SDL_DestroyWindow(w); };
static auto destroyRenderer = [](SDL_Renderer* r) { SDL_DestroyRenderer(r); };
static auto destroyTexture = [](SDL_Texture* r) { SDL_DestroyTexture(r); };

static std::unique_ptr<SDL_Window, decltype(destroyWindow)> window;
static std::unique_ptr<SDL_Renderer, decltype(destroyRenderer)> renderer;
static std::unique_ptr<SDL_Texture, decltype(destroyTexture)> texture;
static std::unique_ptr<std::uint32_t> screen;

static int frames;
static std::uint64_t ticks;

int setupVGA() {
    SDL_SetAppMetadata("VGA simulator", "1.0", "com.cyao.vgasimulator");
    if (!SDL_Init(SDL_INIT_VIDEO)) {
        SDL_Log("Couldn't initialize SDL: %s", SDL_GetError());
        return 1;
    }

    if (!SDL_CreateWindowAndRenderer("VGA verilog simulator", DEFAULT_W, DEFAULT_H, 0,
                                     std::out_ptr(window), std::out_ptr(renderer))) {
        SDL_Log("Couldn't create window/renderer: %s", SDL_GetError());
        return 1;
    }

    texture = decltype(texture)(SDL_CreateTexture(renderer.get(), SDL_PIXELFORMAT_RGBA8888,
                                        SDL_TEXTUREACCESS_STREAMING, DEFAULT_W, DEFAULT_H));

	SDL_SetRenderDrawBlendMode(renderer.get(), SDL_BLENDMODE_NONE);
	SDL_SetTextureBlendMode(texture.get(), SDL_BLENDMODE_NONE);
	SDL_SetWindowPosition(window.get(), SDL_WINDOWPOS_CENTERED, SDL_WINDOWPOS_CENTERED);
	SDL_RaiseWindow(window.get());

    screen = decltype(screen)(new std::uint32_t[DEFAULT_W * DEFAULT_H]);

    SDL_memset(screen.get(), 0xFF, DEFAULT_W * DEFAULT_H * 4);

    return 0;
}

int drawVGA(Vvga* vga) {
    static int x;

    static int pitch;
	static void* pixels;

    if (vga->de) {
        screen.get()[x] = (static_cast<std::uint32_t>(vga->vga_b) <<  8) ^
                          (static_cast<std::uint32_t>(vga->vga_g) << 16) ^
                          (static_cast<std::uint32_t>(vga->vga_r) << 24);

        x += 1;
    } else {
        // Let us quit
        SDL_Event e;
        SDL_PollEvent(&e);
        [[unlikely]] if (e.type == SDL_EVENT_QUIT) {
            return 1;
        }

        if (!vga->vsync && x != 0) {
            x = 0;

            SDL_LockTexture(texture.get(), NULL, &pixels, &pitch);

            assert(pitch == sizeof(std::uint32_t) * DEFAULT_W);

            SDL_memcpy(pixels, screen.get(), DEFAULT_W * DEFAULT_H * sizeof(std::uint32_t));
            SDL_UnlockTexture(texture.get());
            SDL_RenderTexture(renderer.get(), texture.get(), NULL, NULL);
            SDL_RenderPresent(renderer.get());

            frames += 1;

            if (SDL_GetTicks() - ticks > 2000) { // Per 2 seconds
                std::cout << "FPS:" << static_cast<float>(frames) / (static_cast<float>(SDL_GetTicks() - ticks) / 1000) << std::endl;
                frames = 0;
                ticks = SDL_GetTicks();
            }
        }

        return 0;
    }

    return 0;
}

int main(int argc, char** argv) {
    // Parse cli options
    po::options_description desc("Allowed options");
    desc.add_options()
        ("help",      "display this text and exit")
        ("trace",     "produce waveform dump")
        ("tracefile", po::value<std::string>()->default_value("wave.vcd"), "waveform file name")
    ;

    po::variables_map vm;
    po::store(po::parse_command_line(argc, argv, desc), vm);
    po::notify(vm);

    // Print help message
    if (vm.count("help")) {
        std::cout << desc << "\n";
        return 1;
    }

    if (setupVGA()) {
        return 1;
    }

    Verilated::mkdir("logs");
    VerilatedVcdC* tfp = nullptr;
    VerilatedContext* const contextp = new VerilatedContext;
    contextp->debug(0); // 0 is off, 9 highest
    
    bool trace = false;
    if (vm.count("trace")) {
        contextp->traceEverOn(true);
        trace = true;
    } else {
        contextp->traceEverOn(false);
    }

    contextp->commandArgs(argc, argv);

    const auto top = std::unique_ptr<Vvga>(new Vvga(contextp, "TOP"));
    // Trace to 99 depth
    if (trace) {
        tfp = new VerilatedVcdC;
        top->trace(tfp, 99);
        tfp->open(vm["tracefile"].as<std::string>().data());
    }

    ticks = SDL_GetTicks();
    while (!contextp->gotFinish()) {
        contextp->timeInc(1); // Time is passing uwu
        top->clkp = !top->clkp; // 50MHz clock
        
        // Signals are posedge in verilog, so we change on negedge
        if (!top->clkp) {
            // TODO: LED and btn

            if (drawVGA(top.get())) {
                // Quit
                return 0;
            }
        }

        top->eval();

        if (trace) {
            tfp->dump(contextp->time());
        }
    }

    if (trace) {
        tfp->close();
    }
    top->final();
}

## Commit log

2025-05-30 Improvements of v1.1
    [ecp5.kicad_sch, flash.kicad_sch, gpio.kicad_sch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]
2025-05-30 Clean up the design by a bit
    [ecp5.kicad_sch, flash.kicad_sch, gpio.kicad_sch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]
2025-05-30 Board type
    [bom.csv, designators.csv, icepi-zero.kicad_pcb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]
2025-05-30 Add gerbers
2025-06-01 Correct solder keepout on mounting points and move resistors
    [icepi-zero.kicad_pcb]
2025-06-01 Make routing more optimized
    [ecp5.kicad_sch, icepi-zero.kicad_pcb, positions.csv]
2025-06-01 Improve HDMI spacing and impedance control
    [icepi-zero.kicad_pcb, positions.csv]
2025-06-05 OSHWA cerification :yay: and pinout diagram
    [designators.csv, icepi-zero.kicad_pcb, icepi-zero.kicad_sch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]
2025-06-07 Fix wrong dates on shematic and pcb sheet
    [ecp5.kicad_sch, flash.kicad_sch, gpio.kicad_sch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]
2025-06-07 Update pcb pic on readme
    [icepi-zero.kicad_pcb, positions.csv]
2025-06-08 Fix spelling error in lpf
    [icepi-zero.kicad_pcb]
2025-06-08 Fix pin assignment errors and schematic lable naming mismatch between versions
    [gpio.kicad_sch, icepi-zero.kicad_sch]
2025-06-08 Replace unavaliable part
    [icepi-zero.kicad_sch]
2025-06-11 Increase pad spacing to 1.9mm and change SCL name to SCK
    [bom.csv, ecp5.kicad_sch, flash.kicad_sch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]
2025-06-11 Fix wrong comment text
    [power.kicad_sch]
2025-06-11 Remove unused silkscreen identifier
    [icepi-zero.kicad_pcb]
2025-06-14 Fix typo in filename
    [bom.csv, icepi-zero.kicad_pcb, icepi-zero.kicad_sch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]
2025-06-15 V1.2 - some pin optimization + usb improvements
    [bom.csv, designators.csv, ecp5.kicad_sch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]
2025-06-16 Fix typo in README
    [icepi-zero.kicad_pcb]
2025-06-17 Update pic on readme
    [ecp5.kicad_sch, flash.kicad_sch, gpio.kicad_sch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]
2025-06-17 update usb's pin def to not be a differential pair
2025-06-17 Update dvi implementation
    [icepi-zero.kicad_pcb]
2025-06-18 Trying to document my journey :)
    [bom.csv, designators.csv, flash.kicad_sch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]
2025-06-19 Writing up my journey :)
    [usb.kicad_sch]
2025-06-22 Custom ECP5-CABGA256 symbol
    [ecp5.kicad_sch, gpdi.kicad_sch, gpio.kicad_sch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]
2025-06-25 Remove sponsorship info because divergent views
    The advertisement was entirely voluntary from my part at the start - but currently they are trying to implement enforced advertisement which isn't in lines of my views for the future of this non-prof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
2025-06-27 Remove external library dependency
    [gpdi.kicad_sch]
2025-06-28 Fix UART example
2025-06-30 Fix pcb view link
2025-07-03 Put better pin names for LPF files
    [bom.csv, designators.csv, ecp5.kicad_sch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]
2025-07-03 Don't overwrite v1.2 with v1.3
    [bom.csv, icepi-zero.kicad_pcb, icepi-zero.kicad_sch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]
2025-07-08 Fix wrongly constrained pin
2025-07-09 Regenerate IBOM
    [bom.csv, designators.csv, ecp5.kicad_sch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]
2025-07-11 Add wip uart 2 ps2 converter
    [icepi-zero.kicad_pcb]
2025-07-12 UART to PS2 converter
    [ecp5.kicad_sch, flash.kicad_sch, gpdi.kicad_sch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]
2025-07-13 Improve Makefile and v1.0 lpf
    [icepi-zero.kicad_pcb, icepi-zero.kicad_sch, positions.csv]
2025-07-14 Correct flash pin names
2025-07-16 I hate lattice - PCLKC is not a clock pin...
    [bom.csv, designators.csv, ecp5.kicad_sch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]
2025-07-23 Newest source files
    [icepi-zero.kicad_pcb, sdram.kicad_sch, usb.kicad_sch]
2025-08-04 Refine README
    [bom-icepi-zero-v1.3.ods, bom-icepi-zero-v1.3.xls, bom.csv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]
2025-08-14 Change to more optimal inductor
    [bom.csv, icepi-zero.kicad_pcb, power.kicad_sch]
2025-08-25 Added start of documentation and changed GPDI
    [bom-icepi-zero-v1.3.ods, bom-icepi-zero-v1.3.xls, bom.csv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]
2025-08-26 DVI multires
    [icepi-zero.kicad_pcb, usb.kicad_sch]
2025-09-01 Update files
    [bom-icepi-zero-v1.3.ods, bom-icepi-zero-v1.3.xls, bom.csv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]
2025-09-15 Update to v1.3 board
    [bom.csv, designators.csv, ecp5.kicad_sch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]
2025-09-18 Final mass production files
    [bom.csv, bom.xlsx, designators.csv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]
2025-10-11 Improve makefile and hardware
    [flash.kicad_sch, gpdi.kicad_sch, icepi-zero.kicad_pcb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]
2026-01-01 Revert 6b868bc pin definiton change
    [icepi-zero.kicad_pcb]
2026-01-10 Update user buttons to 2
2026-01-14 Change LED's resistor values to make them dimmer
    [bom.csv, designators.csv, flash.kicad_sch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]
2026-01-19 Add pdf schematic
2026-03-15 Remove ugly stub
    [flash.kicad_sch]
2026-04-03 Updated OpenOCD config for icepi-zero to restore UART mode on exit.
2026-04-03 Added 3D printable case.

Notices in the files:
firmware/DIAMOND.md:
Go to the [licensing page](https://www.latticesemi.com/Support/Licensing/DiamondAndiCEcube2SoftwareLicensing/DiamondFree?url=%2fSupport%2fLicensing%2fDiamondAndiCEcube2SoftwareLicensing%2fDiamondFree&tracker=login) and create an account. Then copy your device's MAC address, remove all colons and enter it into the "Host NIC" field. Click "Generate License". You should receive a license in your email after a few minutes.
